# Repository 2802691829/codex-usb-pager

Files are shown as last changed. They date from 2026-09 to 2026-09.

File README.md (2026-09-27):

# Codex USB Pager

一个基于 RP2040-Zero 的桌面 USB 状态提示器。它通过 USB CDC 接收电脑端汇总状态，
用 1.3 英寸 ST7789 屏幕显示 Codex 任务状态、并行任务数量和每周余量，并在需要人工
处理或任务完成时通过有源蜂鸣器提示。

本仓库同时包含程序源码、主机端工具、测试、已验证 UF2，以及最终四卡扣树脂外壳的
可编辑模型和打印文件。

## 项目简介

主要能力：

- 将多个 Codex 任务聚合为一个 `RUNNING`、`WAIT`、`DONE` 或 `ERROR` 状态；
- 在屏幕上显示 Blossom 动画、并行任务效果和周余量；
- 通过边沿事件控制蜂鸣器，普通运行和心跳保持静音；
- 提供可编辑 FreeCAD 外壳、STEP 交换模型及前后壳 STL；
- 保留固件、主机端和外壳几何测试，方便后续维护。

## 硬件与接线

核心硬件：

- 控制器：RP2040-Zero；
- 屏幕：1.3 英寸 ST7789 IPS，240 × 240，七针 SPI；
- 蜂鸣器：三针低电平触发有源蜂鸣器；
- 板载状态灯：GP16 上的 WS2812；
- 连接方式：RP2040-Zero USB-C，USB CDC。

| 模块引脚 | RP2040-Zero | 说明 |
| --- | --- | --- |
| 屏幕 GND | GND | 共地 |
| 屏幕 VCC | 3V3 | 不要接 5 V |
| 屏幕 SCL | GP12 | PIO SPI 时钟 |
| 屏幕 SDA | GP11 | PIO SPI 数据 |
| 屏幕 RES | GP10 | 复位 |
| 屏幕 DC | GP9 | 命令/数据 |
| 屏幕 BLK | GP8 | 高电平开启背光 |
| 蜂鸣器 GND | GND | 共地 |
| 蜂鸣器 IO | GP14 | 低电平触发 |
| 蜂鸣器 VCC | 3V3 | 模块供电 |

不要使用裸露的两针无源蜂鸣器。

## USB 状态协议

电脑端通过 USB CDC 发送一行以换行符结束的 ASCII 快照：

```text
STATE <state> RUN=<n> WAIT=<n> DONE=<n> BAL=<token> EV=<event>
```

示例：

```text
STATE RUNNING RUN=2 WAIT=0 DONE=14 BAL=82 EV=NONE
```

- 状态：`IDLE`、`RUNNING`、`WAIT`、`DONE`、`ERROR`；
- 事件：`NONE`、`WAIT`、`DONE`、`ERROR`；
- 8 秒未收到有效快照时，固件进入 `OFFLINE`；
- `RUNNING` 且 `RUN>1` 时显示多任务动画。

## 屏幕与蜂鸣器行为

- `OFFLINE`：六个灰色 Blossom 部件落到白色六边形底部；
- `IDLE/READY`：六个绿色部件缓慢环绕，中央显示周余量；
- `RUNNING`：紫色 Blossom 旋转并带有加速和缩放脉冲；
- 多任务运行：主 Blossom 位于前方，后方叠加模糊彩色层；
- `WAIT`：琥珀色确认画面；
- `DONE`：完成画面每三秒脉冲一次，不显示勾号。

蜂鸣器事件：

- `EV=WAIT`：三次安静短鸣；
- `EV=DONE`：一次安静短鸣；
- `EV=ERROR`：五次安静短鸣；
- `RUNNING`、`IDLE`、`OFFLINE`、心跳和普通工具活动静音。

## 快速使用已验证固件

已打包固件位于：

```text
firmware-release/codex_pager_rp2040.uf2
```

烧录步骤：

1. 按住 RP2040-Zero 的 `BOOT` 键；
2. 连接 USB，或在按住 `BOOT` 时复位；
3. 等待电脑出现 `RPI-RP2` 磁盘；
4. 将 UF2 文件复制到该磁盘；
5. 复制完成后磁盘自动消失，控制器重新启动。

仅修改电脑端 Hook 或聚合逻辑时不需要重新烧录固件。

## 从源码构建固件

需要 Raspberry Pi Pico SDK、CMake 和可用的 ARM GCC 工具链。在仓库根目录运行：

```powershell
powershell -ExecutionPolicy Bypass -File tools/build_rp2040.ps1
```

构建结果：

```text
build-rp2040/codex_pager_rp2040.uf2
```

固件源码位于 `ports/rp2040-zero/firmware/`，原生行为测试位于
`ports/rp2040-zero/tests/`。

## 主机端工具

需要 Python 3，并安装串口与测试依赖：

```powershell
python -m pip install pyserial pytest
```

主要入口：

- `tools/pager_daemon.py`：聚合任务状态并持续发送 USB 快照；
- `tools/pager_hook_runtime.py`：接收 Codex Hook 事件；
- `tools/session_watcher.py`：读取语义会话事件；
- `tools/pager_runtime.py`：维护多任务运行状态；
- `tools/pager_transport.py`：USB 串口传输；
- `tools/weekly_balance.py`：读取周余量。

启动守护进程：

```powershell
python tools/pager_daemon.py
```

`installed-hooks/` 保存当时安装使用的 Hook 和配置快照。复制或修改 Hook 前，请先阅读
`PROGRAM_HANDOFF.md`，并根据本机 Codex 配置目录调整绝对路径。同一时间只运行一个
`pager_daemon.py` 进程。

## 最终四卡扣外壳

最终模型位于 `enclosure/`：

- 可编辑 FreeCAD：`enclosure/outputs/blossom-enclosure.FCStd`；
- STEP：`enclosure/outputs/blossom-enclosure.step`；
- 前壳 STL：`enclosure/outputs/blossom-front.stl`；
- 后壳 STL：`enclosure/outputs/blossom-rear.stl`；
- 参数化建模源码：`enclosure/cad/`；
- 几何测试：`enclosure/tests/`；
- 审计结果：`enclosure/outputs/audit.json`。

只有 `audit.json` 中 `passed=true`，并且 `checks` 中每一项均为 `true` 时，STL 才可
作为打印候选。

树脂打印建议：

- 倾斜摆放，避免将正反面 Blossom 浮雕和正面六边形承靠边直接贴平台；
- 支撑尽量放在隐藏内表面，避开屏幕承靠面、四个卡扣受力面和滑动导轨；
- 普通壳壁为 1.50 mm；卡扣根部和导轨受力壁不低于 1.30 mm；
- 已知薄桥、支撑和止挡不低于 0.80 mm；
- 清洗、排液并完全固化后再试装，不要强压未固化卡扣。

合盖顺序：

1. 将上方两个公头倾斜插入后壳上方接收槽；
2. 放平前壳；
3. 从底边向上滑动 2.50 mm，直到下方两个卡扣进入浅止动。

USB 开口相对早期基线向上移动 5.00 mm。蜂鸣器完全内置，不设置外部开孔。

## 测试

主机端回归命令：

```powershell
python -m pytest tools/test_pager_runtime.py tools/test_session_watcher.py tools/test_pager_state.py tools/test_codex_log_watcher.py tools/test_pager_transport.py -q
```

外壳源码测试：

```powershell
python -m pytest enclosure/tests -q
```

本次 GitHub 整理按用户要求未重新运行测试；历史交接记录中的最近一次主机端结果为
2026-08-21 的 50 项通过，外壳最终审计文件记录 `passed=true`。

## 目录结构

```text
assets/                 Blossom 原始资源
Core/                   生成后的 Blossom 掩码源码
docs/program-history/   程序设计历史
enclosure/              最终四卡扣外壳源码、测试和输出
firmware-release/       已打包 UF2
installed-hooks/        Hook 安装快照
ports/rp2040-zero/      RP2040 固件和测试
tools/                  电脑端工具和测试
PROGRAM_HANDOFF.md      程序维护交接说明
```

## 维护说明

- 修改前先阅读 `PROGRAM_HANDOFF.md`；
- 保持多任务聚合：单个任务提前完成时必须静音，最后一个活动任务结束后才能发出完成事件；
- 不要随意修改 Blossom 中心、花瓣比例、六边形边界、配色或过渡动画；
- 构建目录、Python 缓存、临时测试目录和对象文件不会纳入版本控制；
- 本仓库不包含旧版外壳基线、旧 ZIP 或工作区中的其他项目。

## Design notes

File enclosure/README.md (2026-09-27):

# Blossom 外壳输出说明

`outputs/` 根目录保存已确认的只读基线；本次四卡扣改造全部位于
`outputs/four-latch-retrofit/`，不会覆盖基线文件。

## 最终文件

- `blossom-enclosure.FCStd`：可编辑 FreeCAD 源模型。
- `blossom-enclosure.step`：前壳与后壳组合交换模型。
- `blossom-front.stl`：前壳树脂打印网格。
- `blossom-rear.stl`：后壳树脂打印网格。
- `audit.json`：尺寸、装配避让和网格完整性审计。
- `review-dimensions.txt`：关键尺寸摘要。
- `review-*.png`：外观、内部、屏幕退让、四卡扣和三段装配复核图。

只有 `audit.json` 中 `passed` 为 `true`，并且所有 `checks` 均为 `true` 时，
两份 STL 才可作为打印候选。

## 合盖顺序

1. 将上方两个公头倾斜插入后壳上方接收槽。
2. 放平前壳。
3. 从底边向上滑动 `2.50 mm`，直到下方两个卡扣进入 `0.25 mm` 浅止动。

屏幕由后壳内陷支撑和四个边缘止挡固定，正面不设屏幕卡槽。USB 开口相对
基线向上移动 `5.00 mm`。蜂鸣器完全内置，本版本不增加蜂鸣器开孔。

## 嘉立创树脂打印

- 建议倾斜摆放，避免把正反 Blossom 浮雕和正面六边形承靠边直接贴平台。
- 支撑尽量落在隐藏内表面，避开屏幕承靠面、四个卡扣受力面和滑动导轨。
- 普通壳壁为 `1.50 mm`；卡扣根部和导轨受力壁不低于 `1.30 mm`；已知薄片、
  桥和止挡不低于 `0.80 mm`。
- 清洗、排液并完全固化后再试装。首次合盖应缓慢滑入，不要在未固化树脂上
  强行按压卡扣。

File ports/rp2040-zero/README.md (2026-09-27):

# Codex Pager: RP2040-Zero Porting Guide

This directory freezes the working STM32 pager design so it can be ported to an
RP2040-Zero without rediscovering the protocol, animation, or asset pipeline.
The STM32 implementation remains the behavioral reference.

## Current Status

The RP2040-Zero now drives the ST7789 through the verified PIO/DMA path. USB
CDC, the onboard WS2812 on GP16, and the optional active-low buzzer on GP14
remain active.

The temporary status effects are:

- `IDLE`: low cool white.
- `RUNNING`: blue-purple breathing.
- Multi-task running: the purple foreground Blossom continues uninterrupted;
  each additional task adds one complete, translucent blue/violet/cyan Blossom
  behind it, capped at three ghosts.
- `WAIT`: amber double flash.
- `DONE`: soft green pop every three seconds.
- `ERROR`: red triple flash and five short buzzer pulses.
- `OFFLINE`: dim red slow flash after eight seconds without a valid snapshot.

Every RGB channel is clamped to 20 out of 255.

## Frozen Behavior

- Display: ST7789, 240x240, RGB565, seven-pin SPI module.
- States: `IDLE`, `RUNNING`, multi-task running, `WAIT`, `DONE`, `ERROR`, and
  `OFFLINE`.
- Fixed visual center: `(120, 109)`.
- Animated region: `(34, 23)`, size `172x172`.
- Footer begins at y=196.
- Frame target: 72 ms.
- State transition: 260 ms exit followed by 480 ms enter.
- Running cycle: 4.7 seconds with continuous angular acceleration and scale.
- Multi-task cycle: 4.6 seconds plus three translucent colored Blossom layers.
- DONE has no check badge. Its pearl Blossom and mint ring pulse every 3 seconds.
- The active-low buzzer is non-blocking: 25 ms on and 180 ms between beeps.
- Host timeout: 8 seconds, then `OFFLINE`.

The exact animation and palette implementation is in
`../../Core/Src/oled.c`. Do not redraw the logo from primitives.

## Proposed RP2040-Zero Wiring

| Display/module pin | RP2040-Zero | Purpose |
| --- | --- | --- |
| GND | GND | Common ground |
| VCC | 3V3 | ST7789 power |
| SCL | GP12 | PIO SPI clock |
| SDA | GP11 | SPI1 TX |
| RES | GP10 | Display reset |
| DC | GP9 | Command/data |
| BLK | GP8 | Backlight, high=on |
| Buzzer IO | GP14 | Active-low buzzer input |
| Buzzer VCC | 3V3 | Buzzer module power |
| Buzzer GND | GND | Common ground |

The bare two-pin passive buzzer is not part of this saved design.

## USB Wire Protocol

The device receives newline-terminated ASCII over USB CDC:

```text
STATE <state> RUN=<n> WAIT=<n> DONE=<n> BAL=<token> EV=<event>\n
```

Example:

```text
STATE RUNNING RUN=3 WAIT=0 DONE=14 BAL=82 EV=NONE
```

Rules:

- `WAIT` has visual priority over running tasks.
- `RUNNING` with `RUN>1` selects the multi-task animation.
- `EV=WAIT`, `EV=DONE`, and `EV=ERROR` trigger 3, 1, and 5 quiet short pulses
  respectively. The boot pulse is one short pulse. RUNNING and multi-task
  running stay silent.
- Events are edge notifications; heartbeat snapshots normally use `EV=NONE`.
- Existing host aggregation remains in `../../tools/`.

## Files To Reuse

| Source | RP2040 use |
| --- | --- |
| `../../assets/openai-blossom.svg` | Canonical official Blossom source |
| `../../tools/generate_blossom_asset.py` | Regenerate the packed mask and sine table |
| `../../Core/Inc/blossom_asset.h` | Copy unchanged |
| `../../Core/Src/blossom_asset.c` | Copy unchanged; 8192-byte 4-bit alpha mask |
| `../../Core/Src/oled.c` | Behavioral reference for palette, animation, and compositing |
| `../../Core/Src/main.c` | Behavioral reference for parsing, timeout, and buzzer scheduling |
| `../../tools/pager_state.py` | Host state aggregation |
| `../../tools/pager_runtime.py` | Multi-task runtime database |
| `../../tools/pager_daemon.py` | Two-second heartbeat sender |

## Recommended Pico SDK Architecture

Use Pico SDK C/C++ with TinyUSB enabled.

1. Core 0 owns TinyUSB CDC, command parsing, the 8-second host timeout, and the
   non-blocking buzzer state machine.
2. The display renderer may remain on core 0 initially. Move it to core 1 only
   if USB servicing becomes uneven during full-frame animation.
3. Use a PIO state machine plus DMA for ST7789 output because the required
   consecutive GP29/GP28 wiring is not a fixed hardware SPI SCK/TX pair.
4. Render one 172-pixel RGB565 scanline into a 344-byte buffer. Use two line
   buffers and DMA so the next line can be composed while the previous line is
   transmitted.
5. Keep all animation calculations integer-only. Reuse `g_sin_q15[256]`, Q12
   scale, 8-bit angle, RGB565 blending, and 4-bit bilinear mask sampling.
6. Call `tud_task()` frequently. Accumulate CDC bytes until newline, then pass
   one complete line to the existing parser logic.

## Porting Boundaries

Preserve these functions conceptually:

```text
ui_init()
ui_set_dashboard(state, run, wait, done, balance)
ui_update(time_ms)
buzzer_start(count)
buzzer_update(time_ms)
process_line(ascii_line)
```

Replace only these STM32-specific pieces:

- `HAL_GetTick()` -> `to_ms_since_boot(get_absolute_time())`
- GPIO BSRR writes -> Pico GPIO helpers or SPI peripheral output
- software SPI and `set_window()` transport -> Pico PIO + DMA
- STM32 USB device stack -> TinyUSB CDC
- STM32 startup, linker script, HAL, and Cube USB files -> Pico SDK CMake target

## Host Discovery Change

`../../tools/send_pager.py` discovers both the Pico SDK RP2040 CDC identity
`2E8A:000A` and the STM32 reference identity `0483:5740`. The RP2040 firmware
uses the product string `Codex Pager`; `--port COMx` remains available.

## Stage 1 Build

Required tools are Pico SDK 2.2.0, ARM GNU Toolchain 14.3, CMake, NMake, and
picotool 2.2.0 or another picotool compatible with SDK requirement 2.1.1.

On this Windows machine, the ARM linker cannot consume object paths containing
Chinese characters. Build through an ASCII source path and keep the SDK and
build directory on an ASCII path. The verified target is:

```text
PICO_BOARD=pico
firmware target: codex_pager_rp2040
UF2: build-rp2040/codex_pager_rp2040.uf2
```

Native core tests:

```powershell
cmake -S ports/rp2040-zero/tests -B <ascii-build-dir> -G "NMake Makefiles"
cmake --build <ascii-build-dir>
ctest --test-dir <ascii-build-dir> --output-on-failure
```

Firmware configuration follows the same pattern with
`ports/rp2040-zero/firmware`, `PICO_SDK_PATH`, `PICO_TOOLCHAIN_PATH`,
`PICO_BOARD=pico`, and `picotool_DIR` set explicitly.

The verified local build helper stages the source and SDK under an ASCII-only
temporary path before compiling, then copies the UF2 back into the project:

```powershell
powershell -ExecutionPolicy Bypass -File tools/build_rp2040.ps1
```

## Acceptance Checklist

- ST7789 initializes at 240x240 with correct orientation and RGB order.
- Blossom bounding box is centered on `(120, 109)` at zero rotation.
- Rotation does not change the center pixel or create a visible jump.
- Single-task running completes a smooth 4.7-second cycle.
- `RUN=3` shows three translucent ghost Blossoms behind the primary Blossom.
- WAIT has three short low-level buzzer pulses without freezing animation.
- DONE contains no check and pulses at 0, 3, 6 seconds.
- State transitions last 650 ms and never clear to a bright frame.
- USB remains responsive while animation is active.
- Missing heartbeat produces OFFLINE after 8 seconds.
- The existing Python state/runtime tests still pass.

## Prompt For A Future Codex Session

```text
Read codex_usb_pager/ports/rp2040-zero/README.md and port_manifest.json.
Continue from the tested stage-1 Pico SDK firmware. Reuse blossom_asset.c/h and
the host wire protocol. Keep ST7789 output on BLK=GP8, DC=GP9, RES=GP10,
SDA=GP11, SCL=GP12 with packed whole-region PIO/DMA output, then add the
non-blocking active-low buzzer on GP14. Build and test before flashing. Do not
redesign the visuals.
```

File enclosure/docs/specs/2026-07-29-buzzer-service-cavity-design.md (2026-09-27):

# Blossom Buzzer Service Cavity Design

Date: 2026-07-29

## Goal

Replace the buzzer-matched cylindrical relief with a substantially larger
service cavity in the left rear Blossom petal. The cavity must maximize usable
assembly space without changing the visible enclosure exterior.

## Approved Geometry

- Keep the buzzer validation envelope at 12.0 mm diameter and 11.5 mm height.
- Remove the buzzer envelope's cylindrical shape as the production cavity
  boundary.
- Create a connected service cavity that opens from the existing rectangular
  electronics cavity into the left Blossom petal.
- Start the service cavity at the PCB/buzzer front plane, Z = 4.30 mm.
- Extend it to Z = 18.30 mm, the safe inner rear surface, instead of stopping
  at the buzzer's 11.5 mm validation height.
- Define its generous pre-clipping window as X = -28.0 to -12.0 mm and
  Y = -5.5 to 18.0 mm. This overlaps the existing electronics cavity by
  2.0 mm and leaves the lower latch and upper locator outside the window.
- Give the pre-clipping window 3.0 mm corner radii.
- Expand the cavity toward the left petal as far as the protected inner
  Blossom contour permits.
- Preserve at least 1.50 mm of exterior wall and relief backing around the new
  cavity.
- Keep the service cavity clear of the upper locator tongue/socket pair and
  the lower hidden spring latch and its activity tunnel.
- Use rounded transitions where the service cavity joins the existing
  electronics cavity. No buzzer-shaped circular wall is retained.

## Closure Features

The small raised feature and matching recess shown near the upper shell edge
are the front-shell locator tongue and rear-shell locator socket. They prevent
upper-edge shear, rocking, and assembly misalignment. The side spring latches
remain responsible for locking the enclosure.

Both upper locators remain unchanged and hidden after assembly.

## Exterior Contract

The following visible geometry must remain unchanged:

- 56.0 mm Blossom outer width and unwarped SVG proportion.
- Front and rear 1.5 mm Blossom relief.
- Front screen hexagon and screen pocket alignment.
- Rear rounded USB opening.
- Continuous front and rear exterior surfaces with no buzzer opening.

The service cavity cutter is clipped to an internal protected Blossom core.
It must not intersect the exterior guard.

## Mechanical Keepouts

The new cavity must not obstruct:

- the 26.30 x 29.30 mm screen pocket and its retainers;
- the four screen locating posts;
- the two upper tongue/socket locators;
- the two lower hidden spring latches and their motion envelopes;
- the USB adapter window and support structure.

## Verification

Automated checks must prove:

- buzzer service cavity exterior breach volume is 0.0 mm3;
- buzzer obstruction volume remains 0.0 mm3;
- closure, USB, screen, and assembly interference volumes remain 0.0 mm3;
- the rear shell remains valid and a single solid;
- front and rear exterior dimensions and relief depths are unchanged;
- the new service cavity is wider and deeper than the 12.0 x 11.5 mm buzzer
  validation envelope;
- rendered rear-inside and assembly-cutaway views visibly show the enlarged
  non-cylindrical cavity;
- front and rear exterior renders remain visually unchanged.

## Deliverables

- Updated FreeCAD source model.
- Regenerated FCStd, STEP, front STL, and rear STL files.
- Updated geometry audit and regression tests.
- Updated review renders and a refreshed handoff archive.

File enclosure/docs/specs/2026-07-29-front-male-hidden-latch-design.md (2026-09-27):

# 前壳公扣、后壳弹片隐藏卡扣设计

日期：2026-07-29

## 背景与问题

上一版闭合结构把插舌盲槽和卡勾槽直接切入前壳。前壳接缝厚度为
2.3 mm，而正面白块区域又下凹 1.5 mm，局部只保留 0.8 mm 材料。
卡槽从内侧继续切入后，与正面凹陷切削发生重叠，形成正面可见孔。

本次修改必须满足：

- 前壳正面和侧面均看不到卡扣孔。
- 后壳背面和侧面也不能出现母槽通孔。
- 仍然采用隐藏结构，不在外轮廓增加凸耳。
- 偶尔拆开时可用指甲完成，不使用螺丝或工具。
- 屏幕固定、USB 后开孔、蜂鸣器全内藏和 1.5 mm Blossom 凹凸保持不变。

## 选定结构

卡扣公母方向反转为“前壳短刚性公扣 + 后壳长弹片母扣”。

### 顶部定位

前壳内侧设置两个刚性定位舌，沿装配方向伸入后壳。后壳内侧设置两个
有封底的定位盲槽。定位舌只负责对中和限制横向晃动，不承担弹性锁止。

初始尺寸：

- 定位舌：宽 5.0 mm、厚 1.0 mm、从接缝向后伸出 2.5 mm。
- 两个定位舌中心为 X = ±10.0 mm、Y = 19.75 mm，以正面有效显示区
  中心为坐标原点。
- 舌尖设置 0.5 mm 导入斜面或等效圆角。
- 后壳盲槽：四周单边间隙 0.25 mm，深度 2.8 mm。
- 盲槽与后壳任何外表面之间保留至少 1.0 mm 实体材料。

### 底部锁止

前壳左右侧花瓣各设置一个短刚性公扣。公扣本体与前壳形成连续实体，
只提供导入斜面和浅锁止台阶，不使用长弹性臂。原底部位置因左侧弹片
会侵入 Blossom 曲面 1.0 mm 外表保护层，并与 USB 内部结构争用空间，
不再使用。

后壳左右侧花瓣各设置一根长悬臂弹片。弹片从后壳较深位置向接缝延伸，
自由端设置母扣窗口或锁止肩。压合时前壳公扣使后壳弹片轻微向外偏转，
越过锁止台阶后回弹。拆卸时，从后壳底部指甲凹位轻撬，20° 脱扣斜面
把轴向拉力转换成小幅弹片偏转。

初始尺寸：

- 前壳公扣宽 4.0 mm，本体厚 1.2 mm。
- 公扣从接缝向后伸出 2.2 mm。
- 两个公扣初始中心为 X = ±15.0 mm、Y = -9.0 mm；实际 CAD 允许在
  相同侧花瓣内微调不超过 1.0 mm，以同时满足外表保护层和内部避让。
- 锁止量 0.35 mm；若首版过紧，优先降到 0.30 mm。
- 导入斜面 35°，脱扣斜面 20°。
- 后壳弹片有效长度 13.0 mm、宽 4.0 mm、厚 1.0 mm。
- 弹片沿 Z 轴布置，自由端靠近接缝，根部位于接缝后方约 13.4 mm。
- 弹片根部圆角 R1.0 mm。
- 弹片周边活动间隙每侧 0.30 mm。
- 指甲凹位保持 10.0 × 1.2 × 0.8 mm，位于后壳底部接缝。

公扣采用短而厚的刚性结构，避免前壳拆开后留下容易折断的长臂。弹性
和磨损集中在可单独重印的后壳上。

## 蜂鸣器净空

蜂鸣器改到屏幕 PCB 左侧、靠上位置，继续完全封闭，不增加声孔。

- 实物圆柱直径 11.0 mm，CAD 净空直径采用 12.0 mm。
- 实物圆柱高度 10.0 mm，CAD 净空高度采用 11.5 mm。
- 用户实测圆柱边缘距 PCB 上边约 7.0 mm、距 PCB 下边约 19.0 mm。
- 屏幕 PCB 高度按 39.22 mm。两组边距与实物直径合计相差 2.22 mm，
  因此以两种中心推算值的平均值定位：在现有外壳坐标系中
  Y = 4.36 mm。
- 使用直径 12.0 mm 净空后，理论上边距约 7.61 mm、下边距约
  19.61 mm。
- 横向按照片将圆柱中心初始设为 X = -9.0 mm。蜂鸣器净空允许通过
  左侧局部圆柱腔超出 28 mm 主电子腔，但不得侵入 1.0 mm 外表保护层。
- 净空从屏幕 PCB 后表面向后延伸 11.5 mm，并与 USB、左右卡扣、
  屏幕定位柱和后壳保持零实体干涉。

## 几何布置

- 两个顶部定位舌和两个侧面公扣均位于 28.0 × 39.5 mm 主电子腔包络
  以外。
- 公扣、弹片和母槽不得与屏幕 PCB、四根定位柱、USB 转接口、USB
  受力板、蜂鸣器或线材包络相交。
- 前壳闭合结构只能增加材料，不得从 `FrontClosureBlank` 原有实体中
  切除材料。
- 后壳定位盲槽、弹片活动腔和母扣窗口全部从接缝内侧形成；任何切削均
  不得到达后壳外表面。
- 前后壳闭合后，公扣和弹片均位于 Blossom 外轮廓投影以内。

## 自动验收

在现有实体审计上增加以下检查：

1. `front_closure_skin_removed_mm3 == 0.0`：最终前壳相对
   `FrontClosureBlank` 不得损失任何原表皮材料。
2. 前壳两个定位舌和两个刚性公扣均与前壳形成连续实体。
3. 后壳两根弹片均与后壳形成连续实体，且各自具有独立活动间隙。
4. 两个公扣均进入对应母扣包络，并具有 0.30–0.35 mm 有效锁止量。
5. 顶部定位舌进入盲槽，但与槽底和四周保留规定间隙。
6. 后壳闭合结构切削不与背面及侧面连续的 1.0 mm 外表保护层相交。
7. 前后壳装配实体干涉体积保持 0。
8. 屏幕和 USB 遮挡体积保持 0。
9. 前壳、后壳均为单一有效实体。
10. `buzzer_obstruction_mm3 == 0.0`：最终后壳、USB 结构和卡扣不得
    进入直径 12.0 mm、高 11.5 mm 的蜂鸣器净空。
11. 蜂鸣器净空与后壳 1.0 mm 外表保护层不得相交。

## 人工验收

重新输出以下不透明审阅图：

- 前壳正面正投影：确认没有矩形孔或透光区域。
- 前壳内面：确认四个公头位置和屏幕固定结构互不干涉。
- 后壳背面正投影：确认母槽和弹片活动腔不透出。
- 后壳内面：确认两根长弹片可以自由变形。
- 接缝剖面和单侧卡扣放大图：确认公扣导入、锁止和脱扣方向。
- 蜂鸣器净空图：确认左侧圆柱包络、USB 和两侧卡扣之间有余量。

首版树脂试装时先检查扣合力、指甲拆卸力和弹片根部是否白化。若扣合
过紧，只调整母扣间隙或把锁止量从 0.35 mm 降到 0.30 mm；不缩短
13.0 mm 弹片，也不在前壳重新开槽。

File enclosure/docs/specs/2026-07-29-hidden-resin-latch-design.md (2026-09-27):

# Blossom 外壳隐藏易拆卡扣设计

日期：2026-07-29

## 目标

把现有四个仅用于占位的矩形块替换为能够真实扣合的隐藏闭合结构，并把完全平整的前壳内面改为能够真实固定屏幕的卡槽与定位柱。外壳使用未知型号的光敏树脂打印，因此按普通偏脆树脂设计：装好后可靠固定，偶尔拆开时可用指甲轻松开启，不需要螺丝或工具。

## 现有问题

当前 `TopHookLeft`、`TopHookRight`、`ReleaseLatchLeft` 和 `ReleaseLatchRight` 都是融合在后壳上的简单矩形实体。前壳没有配合槽，这些实体也没有弹性臂、倒钩、导入斜面或脱扣斜面，所以不能产生机械锁止。现有审计只检查对象名称是否存在，无法证明前后壳能够扣合。

当前前壳内面只有一块平整的矩形承托面，没有与屏幕玻璃外框配合的卡槽，也没有利用 PCB 四角安装孔的定位柱。屏幕位置仅由 28 × 39.5 mm 电子组件包络间接表达，不能保证实际显示区域与正面六边形窗口同心，也不能保证拆下后壳时屏幕仍固定在前壳。

## 闭合结构

采用“顶部定位插舌 + 底部双悬臂浅卡勾”：

1. 后壳顶部设置两个刚性插舌，前壳内侧设置两个盲槽。装配时先以小角度插入顶部，再压下后壳底部。插舌只负责定位和形成开启转轴，不依靠弯曲锁止。
2. 后壳底部左右各设置一个长悬臂卡勾。卡臂从后壳内部向前壳延伸，位于电子器件包络之外，并与后壳形成连续实体。
3. 前壳内侧切出两个对应卡槽。压合时，卡勾的导入斜面使卡臂轻微向内偏转；越过槽口后回弹并形成浅锁止。
4. 后壳底部接缝设置一个不贯穿的指甲凹位。拆壳时从凹位轻撬，卡勾上的脱扣斜面把轴向拉力转化为很小的卡臂偏转，使底端先脱开，再从顶部插舌退出。
5. 所有插舌、卡臂、卡勾和卡槽均位于 Blossom 外轮廓以内；闭合后从正面、背面和侧面都看不到凸出的卡扣。

## 初始尺寸

尺寸以首版试打印为基准，后续只通过参数调整：

- 顶部插舌：每个宽 5.0 mm、厚 1.0 mm、有效插入 2.5 mm。
- 插舌盲槽：单边装配间隙 0.25 mm，槽底保留至少 0.8 mm 壁厚。
- 底部卡臂：每个长 13.0 mm、宽 4.0 mm、厚 1.0 mm。
- 卡臂根部圆角：半径 1.0 mm，避免树脂应力集中。
- 卡勾锁止量：0.40 mm。
- 卡勾导入斜面：35°。
- 卡勾脱扣斜面：20°，避免形成难以撬开的直角倒扣。
- 卡槽周边间隙：每侧 0.30 mm。
- 指甲凹位：宽 10.0 mm、高 1.2 mm、最大内凹 0.8 mm，仅削薄后壳接缝外缘，不贯穿壳体。
- 最小实体壁厚：0.8 mm。

若切片软件的尺寸补偿或打印收缩导致配合偏紧，优先增加卡槽间隙或把锁止量从 0.40 mm 降至 0.30 mm，不缩短卡臂。

## 前壳屏幕固定结构

屏幕模块使用用户提供的 1.3 英寸 ST7789 尺寸图和实测高度：

- PCB 外形：27.78 × 39.22 mm。
- 屏幕有效显示区：23.40 × 23.40 mm。
- 屏幕玻璃外框：25.30 × 29.22 mm。
- 屏幕玻璃正面到 PCB 正面：2.0 mm。
- 四个安装孔：直径 2.0 mm，孔中心距 PCB 各边均为 2.50 mm。

屏幕固定采用“屏幕面卡槽 + 四定位柱 + 两个浅防脱压唇”：

1. 前壳内面增加 25.70 × 29.62 mm 的矩形屏幕面卡槽，等于屏幕玻璃外框四周各留 0.20 mm 间隙。卡槽有效深度 1.0 mm，承力面避开 23.40 × 23.40 mm 有效显示区，并在正面六边形窗口以外形成分散承托。
2. 四根定位柱利用 PCB 四角的直径 2.0 mm 安装孔定位。柱中心相对 PCB 中心的坐标为 X = ±11.39 mm、Y = ±17.11 mm；柱径 1.65 mm，根部加强台直径 3.2 mm，根部带圆角。
3. 定位柱只控制平面位置，不承担屏幕压紧力。屏幕玻璃正面到 PCB 正面的 2.0 mm 高度用于确定卡槽承力面、加强台和定位柱的 Z 向关系。
4. 屏幕面卡槽左右各设置一个隐藏的浅防脱压唇。压唇只越过屏幕玻璃后缘 0.25 mm，不接触 PCB 边缘，不压迫有效显示区；拆下后壳时屏幕仍保留在前壳。
5. 根据尺寸图，有效显示区中心相对 PCB 中心向排针一侧偏移 1.64 mm。正面六边形窗口继续以有效显示区中心为基准；PCB、屏幕玻璃卡槽和四根定位柱整体向排针对侧平移 1.64 mm，不能再与六边形窗口直接同心。
6. 屏幕装入方向为从前壳内侧压入。卡槽入口和压唇均增加圆角或导入斜面，避免刮伤屏幕玻璃边缘。
7. 后壳 28 × 39.5 mm 电子腔与 PCB 使用相同的 -1.64 mm 中心偏移，电子腔底边位于 Y = -21.39 mm。USB 开孔底边随 PCB 基准移到 Y = -24.75 mm，继续保持距屏幕 PCB 底边 3.5 mm。

## 与现有结构的关系

- 删除四个矩形占位块及把它们直接融合到后壳的逻辑。
- 删除现有整块矩形 `screen_ledge`，改为屏幕面卡槽、分散承托面、四根定位柱和两个浅防脱压唇。
- USB 圆角开孔、USB 受力板和 5 mm 内部间隙保持不变。
- 蜂鸣器继续完全藏在内部，不增加声孔。
- 正反面 Blossom 凹凸深度 1.5 mm 和圆滑过渡保持不变。
- 卡臂与电子器件腔、屏幕 PCB、USB 转接口及线材包络不得相交。

## 验收与验证

模型和自动检查必须同时满足：

1. 前壳包含两个真实插舌盲槽和两个真实卡槽；后壳包含两个插舌及两个带斜面的悬臂卡勾。
2. 卡槽必须从前壳实体中实际切除，卡臂和插舌必须与后壳形成连续实体，不能只创建同名辅助对象。
3. 装配位置下，前后壳的非配合实体不得互相穿透；卡勾位于对应卡槽包络内并具有 0.30–0.40 mm 的有效锁止量。
4. 指甲凹位不贯穿壳体，外轮廓没有新增卡扣凸起。
5. 屏幕和 USB 的遮挡体积均为 0。
6. FreeCAD 几何有效性检查通过，前壳和后壳均为可导出的有效实体。
7. 输出正面、背面、侧面、接缝剖面和卡扣局部放大图供人工确认；确认后再导出最终 STL。
8. 屏幕卡槽、定位柱和防脱压唇必须与前壳形成连续实体，不能只是同名辅助对象。
9. 四根定位柱中心与安装孔理论中心偏差为 0；定位柱与直径 2.0 mm 安装孔之间保留 0.175 mm 径向间隙。
10. 屏幕玻璃外框与卡槽之间保留每侧 0.20 mm 间隙，有效显示区与正面六边形窗口按显示区中心对齐。
11. 屏幕承托面和防脱压唇不得侵入 23.40 × 23.40 mm 有效显示区；定位柱及加强台不得与屏幕玻璃外框相交。
12. 装配位置下前壳与后壳的实体干涉体积为 0；四根定位柱及屏幕固定结构不得与后壳电子腔边缘相交。

## 首版试装预期

合壳时先插入顶部，再按压底部两侧，能够感觉到一次轻微扣合。拆壳时用指甲从底部凹位轻撬，不需要明显蛮力；后壳底部先脱开，随后向下退出顶部插舌。卡扣不应出现白化、裂纹或永久变形。

屏幕从前壳内侧装入时，屏幕玻璃外框先进入矩形卡槽，四个安装孔随后落到定位柱上，左右浅压唇以很小变形越过玻璃后缘。屏幕应无明显晃动，玻璃和 PCB 不受持续挤压；拆下后盖并轻晃前壳时，屏幕不脱落。

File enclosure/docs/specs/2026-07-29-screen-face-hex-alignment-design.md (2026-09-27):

# 屏幕凸起卡槽与六边形视窗对齐设计

日期：2026-07-29

## 问题与根因

当前前壳使用 `27.1 mm` 的六边形对边尺寸。该正六边形采用上下顶点
朝向，因此上下顶点距离为：

`27.1 / (sqrt(3) / 2) = 31.29 mm`

该开口高于屏幕凸起部分的 `29 mm` 高度，并且以外壳/显示有效区中心
定位，没有从屏幕凸起顶部建立基准。因此六边形超出屏幕平面，屏幕卡槽
也表现为按旧的近似玻璃尺寸固定，而不是卡住实际屏幕凸起。

## 已确认的实物尺寸

- 屏幕凸起部分：宽 `26.0 mm`、高 `29.0 mm`。
- 屏幕凸起四周有 `0.5 mm` 黑边，外观上不得从前壳视窗露出。
- 屏幕凸起底部有 `3.0 mm` 非显示区域，六边形视窗不得保留在该区域。
- 六边形上下顶点距离：`23.5 mm`。
- 卡槽采用方案 1：屏幕凸起四周单边装配间隙 `0.15 mm`。

PCB 的 `27.78 × 39.22 mm` 外形和四个 `Ø2 mm` 定位孔继续用于定位柱，
但不再作为屏幕卡槽和六边形视窗的外形基准。

沿用规格图中屏幕凸起顶部距 PCB 顶边 `5.00 mm` 的定位尺寸。将屏幕凸起
高度改为实测 `29.00 mm` 后，其底边距 PCB 底边为
`39.22 - 5.00 - 29.00 = 5.22 mm`。

## 屏幕凸起卡槽

卡槽内包络为：

- 宽：`26.0 + 2 × 0.15 = 26.30 mm`
- 高：`29.0 + 2 × 0.15 = 29.30 mm`

卡槽的前端承托平面与屏幕凸起正面平行并贴合，使屏幕凸起进入卡槽后
由前壳内面确定 Z 向位置。四根 PCB 定位柱保留，负责孔位对中；卡槽负责
约束屏幕凸起的 X/Y 外形。左右压片继续从背面压住屏幕凸起，但不得进入
六边形可视开口，也不得与蜂鸣器 `Ø12 × 11.5 mm` 净空相交。

屏幕凸起正面和卡槽承托平面均使用前壳内面
`Z = front_seam_z = 2.30 mm` 作为装配基准。`2.0 mm` 的屏幕凸起厚度
从该平面向后壳方向延伸；不得用 PCB 正面或背面替代这个承托基准。

卡槽不得以 PCB 的 `27.78 × 39.22 mm` 外框生成，也不得将 PCB 整体夹紧
在玻璃/屏幕凸起卡槽内。

在现有坐标系中，PCB 中心 Y 为 `-1.64 mm`，因此：

- PCB 顶边 Y：`-1.64 + 39.22 / 2 = 17.97 mm`
- 屏幕凸起顶边 Y：`17.97 - 5.00 = 12.97 mm`
- 屏幕凸起中心 Y：`12.97 - 29.00 / 2 = -1.53 mm`

卡槽中心使用 `(X, Y) = (0.00, -1.53) mm`，不再直接复用 PCB 中心。

## 六边形视窗

六边形保持正六边形、上下顶点朝向：

- 上下顶点距离：`23.50 mm`
- 左右对边距离：`23.50 × sqrt(3) / 2 = 20.35 mm`

比例约束的含义是六边形自身保持正六边形、Blossom 外形继续按原 SVG
等比生成，二者均不得沿单一轴拉伸。Blossom 外壳目标宽度保持
`56.0 mm`；只把独立六边形切口等比缩放到 `23.50 mm` 上下顶点距离，
不把整个外壳缩小到无法容纳屏幕 PCB 的尺寸。

定位使用屏幕凸起顶部，而不是 PCB、外壳或旧显示有效区中心：

1. 屏幕凸起顶部为 Y 向基准。
2. 六边形上顶点位于屏幕凸起顶部向下 `0.50 mm`，遮住顶部黑边。
3. 六边形下顶点位于上顶点向下 `23.50 mm`。
4. 屏幕凸起底边距六边形下顶点：
   `29.0 - 0.5 - 23.5 = 5.0 mm`。

因此底部 `3.0 mm` 非显示区、底部 `0.5 mm` 黑边以及额外 `1.5 mm`
遮挡余量均位于前壳覆盖区内，不会从六边形视窗露出。

横向以 `26.0 mm` 屏幕凸起中心对齐。六边形左右对边仅宽 `20.35 mm`，
每侧覆盖余量为 `(26.0 - 20.35) / 2 = 2.825 mm`，大于 `0.5 mm`
黑边宽度。

对应现有外壳坐标：

- 六边形上顶点 Y：`12.97 - 0.50 = 12.47 mm`
- 六边形中心 Y：`12.47 - 23.50 / 2 = 0.72 mm`
- 六边形下顶点 Y：`0.72 - 23.50 / 2 = -11.03 mm`

六边形中心使用 `(X, Y) = (0.00, 0.72) mm`，不得再次居中到外壳原点。

六边形切口只贯穿前壳显示窗口所需厚度，并在屏幕凸起正面平面终止；
不得延伸到 PCB 平面，也不得切坏卡槽、定位柱、压片或隐藏卡扣。

## 保持不变的结构

- USB 后开孔尺寸、圆角和位置。
- 蜂鸣器 `Ø12 × 11.5 mm` 内部净空及无声孔设计。
- 前壳刚性公扣、后壳弹性母扣和指甲拆卸凹位。
- 前后壳 Blossom 凹凸高度差 `1.5 mm`。
- Blossom 外形目标宽度 `56.0 mm`，SVG 等比缩放，不拉伸。
- 四个 PCB 定位柱的孔位基准。

## 自动验收

1. 参数检查：
   - 六边形上下顶点距离为 `23.50 mm`。
   - 六边形左右对边距离为 `20.35 mm`，允许计算舍入误差 `±0.01 mm`。
   - 屏幕凸起包络为 `26.0 × 29.0 mm`。
   - 卡槽内包络为 `26.30 × 29.30 mm`。
2. 位置检查：
   - 六边形上顶点距屏幕凸起顶部 `0.50 mm`。
   - 六边形下顶点距屏幕凸起底部 `5.00 mm`。
   - 六边形与屏幕凸起横向中心一致。
   - 屏幕凸起顶边距 PCB 顶边 `5.00 mm`，卡槽中心 Y 为 `-1.53 mm`。
   - 六边形中心 Y 为 `0.72 mm`。
   - 屏幕凸起正面与卡槽承托面同位于 `Z = 2.30 mm`。
3. 几何检查：
   - 六边形切口完全位于屏幕凸起投影内。
   - 卡槽与六边形切口、定位柱、压片的实体关系正确。
   - 屏幕、USB、蜂鸣器及卡扣实体干涉体积均为 `0`。
   - 前壳和后壳均保持单一有效实体。
4. 回归检查：
   - 现有卡扣咬合、活动间隙、蜂鸣器间隙和 USB 开口契约继续通过。

## 人工验收视图

- 前壳正面正投影：六边形上顶点从屏幕顶部黑边内侧开始，四周不露黑边，
  底部不露 `3 mm` 非显示区。
- 前壳内面正投影：能看到 `26.30 × 29.30 mm` 屏幕凸起卡槽、四根 PCB
  定位柱和左右压片，且卡槽不再沿 PCB 外框生成。
- 屏幕装配剖面：屏幕凸起正面与前壳承托平面贴合，PCB 位于卡槽后方，
  六边形切口不延伸到 PCB 平面。

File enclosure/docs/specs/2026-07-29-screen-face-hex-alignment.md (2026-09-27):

# Screen Face Pocket and Hex Alignment Implementation Plan

> **For agentic workers:** REQUIRED SUB-SKILL: Use superpowers:subagent-driven-development (recommended) or superpowers:executing-plans to implement this plan task-by-task. Steps use checkbox (`- [ ]`) syntax for tracking.

**Goal:** Rebuild the front shell so its locating pocket grips the measured
`26 × 29 mm` raised screen face and its regular hexagonal window is `23.5 mm`
point-to-point, top-referenced to hide the black border and lower non-display
area.

**Architecture:** Keep PCB-hole posts referenced to the PCB, but introduce
separate screen-face and window datums in `EnclosureParameters`. Build the
screen pocket from the face datum, translate the independent regular-hex cut
to its calculated Y centre, and expose actual FreeCAD bounds through the audit
so tests verify the exported solid rather than source constants alone.

**Tech Stack:** Python 3, pytest, FreeCAD 1.1 Python API, OpenCascade/Part,
FreeCAD GUI renderer.

## Global Constraints

- Blossom target width remains `56.0 mm`; its SVG is uniformly scaled and
  never stretched along one axis.
- The regular hex remains undistorted, with `23.50 mm` between top and bottom
  vertices and `20.35 mm` between left and right flats.
- Raised screen face is `26.0 × 29.0 mm`; pocket clearance is `0.15 mm` per
  side, producing `26.30 × 29.30 mm`.
- Raised-face top is `5.00 mm` below the PCB top; face centre Y is `-1.53 mm`.
- Hex top vertex is `0.50 mm` below the face top; hex centre Y is `0.72 mm`;
  its bottom vertex leaves `5.00 mm` of covered face.
- Raised-face front and the front-shell bearing plane are both `Z = 2.30 mm`.
- USB, buzzer, hidden latches, PCB locating posts and `1.5 mm` Blossom relief
  remain unchanged and unobstructed.

---

### Task 1: Screen-face and regular-hex parameter contract

**Files:**
- Modify: `codex_usb_pager/enclosure/tests/test_enclosure_params.py`
- Modify: `codex_usb_pager/enclosure/cad/enclosure_params.py`

**Interfaces:**
- Consumes: existing PCB centre and dimensions.
- Produces: `front_hex_point_to_point_mm`,
  `front_hex_across_flats_mm`, `front_hex_center_y_mm`,
  `screen_face_center_y_mm`, `screen_face_top_y_mm`,
  `screen_pocket_mm`.

- [ ] **Step 1: Write failing parameter tests**

```python
def test_hex_is_regular_and_top_referenced_to_screen_face():
    assert DEFAULTS.front_hex_point_to_point_mm == 23.5
    assert round(DEFAULTS.front_hex_across_flats_mm, 2) == 20.35
    assert DEFAULTS.screen_face_top_y_mm == 12.97
    assert DEFAULTS.front_hex_center_y_mm == 0.72
    assert DEFAULTS.front_hex_top_margin_mm == 0.50
    assert DEFAULTS.front_hex_bottom_margin_mm == 5.00

def test_screen_pocket_grips_measured_raised_face():
    assert DEFAULTS.screen_face_mm == (26.0, 29.0)
    assert DEFAULTS.screen_face_clearance_mm == 0.15
    assert DEFAULTS.screen_pocket_mm == (26.30, 29.30)
    assert DEFAULTS.screen_face_center_y_mm == -1.53
    assert DEFAULTS.screen_face_top_offset_from_pcb_mm == 5.0
```

- [ ] **Step 2: Verify the new tests fail for the old values**

Run:

```powershell
python -m pytest enclosure/tests/test_enclosure_params.py -q
```

Expected: failures showing the old `31.3 mm` point-to-point hex,
`25.30 × 29.22 mm` face and `0.20 mm` side clearance.

- [ ] **Step 3: Implement the datum properties**

Use these definitions in `EnclosureParameters`:

```python
front_hex_point_to_point_mm: float = 23.5
screen_face_mm: tuple[float, float] = (26.0, 29.0)
screen_face_clearance_mm: float = 0.15
screen_face_top_offset_from_pcb_mm: float = 5.0
screen_black_border_mm: float = 0.5

@property
def front_hex_across_flats_mm(self) -> float:
    return self.front_hex_point_to_point_mm * sqrt(3.0) / 2.0

@property
def screen_face_top_y_mm(self) -> float:
    return round(
        self.screen_pcb_center_y_mm
        + self.screen_pcb_mm[1] / 2.0
        - self.screen_face_top_offset_from_pcb_mm,
        2,
    )

@property
def screen_face_center_y_mm(self) -> float:
    return round(
        self.screen_face_top_y_mm - self.screen_face_mm[1] / 2.0,
        2,
    )

@property
def front_hex_center_y_mm(self) -> float:
    return round(
        self.screen_face_top_y_mm
        - self.screen_black_border_mm
        - self.front_hex_point_to_point_mm / 2.0,
        2,
    )
```

Keep `front_hex_across_corners_mm` as a compatibility property returning
`front_hex_point_to_point_mm`.

- [ ] **Step 4: Verify parameter tests and the complete pure-Python suite**

Run:

```powershell
python -m pytest enclosure/tests/test_enclosure_params.py -q
python -m pytest enclosure/tests -q
```

Expected: all tests pass except later geometry-contract tests that have not
yet been introduced.

- [ ] **Step 5: Commit Task 1**

```powershell
git add codex_usb_pager/enclosure/cad/enclosure_params.py codex_usb_pager/enclosure/tests/test_enclosure_params.py
git commit -m "feat: define measured screen face and hex datums"
```

### Task 2: Build the raised-face pocket and translated hex cut

**Files:**
- Modify: `codex_usb_pager/enclosure/tests/test_screen_mount_contract.py`
- Modify: `codex_usb_pager/enclosure/cad/build_blossom_enclosure.py`

**Interfaces:**
- Consumes: Task 1 datum properties.
- Produces: translated `FrontHexCut`, `ScreenPocketEnvelope`,
  face-centred locating frame and retainers; PCB posts remain PCB-centred.

- [ ] **Step 1: Write failing build-contract tests**

```python
def test_regular_hexagon_accepts_an_xy_centre():
    assert "def regular_hexagon(" in BUILD
    assert "center_x: float = 0.0" in BUILD
    assert "center_y: float = 0.0" in BUILD
    assert "DEFAULTS.front_hex_center_y_mm" in BUILD

def test_screen_frame_uses_face_centre_but_posts_keep_pcb_centres():
    mount = BUILD[BUILD.index("def build_screen_mount("):]
    assert "DEFAULTS.screen_face_center_y_mm" in mount
    assert "DEFAULTS.screen_post_centres_mm" in mount
    assert '"ScreenPocketEnvelope"' in BUILD
```

- [ ] **Step 2: Verify contract tests fail**

Run:

```powershell
python -m pytest enclosure/tests/test_screen_mount_contract.py -q
```

Expected: failure because the hex is origin-centred and the frame reuses the
PCB centre.

- [ ] **Step 3: Translate the regular hex without distorting it**

Change the helper signature and point creation:

```python
def regular_hexagon(
    across_flats: float,
    z: float,
    height: float,
    center_x: float = 0.0,
    center_y: float = 0.0,
):
    apothem = across_flats / 2.0
    radius = apothem / (sqrt(3.0) / 2.0)
    points = [
        App.Vector(
            center_x + radius * cos(pi / 6.0 + index * pi / 3.0),
            center_y + radius * sin(pi / 6.0 + index * pi / 3.0),
            z,
        )
        for index in range(6)
    ]
```

Create `front_hex_cut` with
`center_y=DEFAULTS.front_hex_center_y_mm`.

- [ ] **Step 4: Separate screen-face and PCB datums**

Inside `build_screen_mount()`:

```python
pocket_width, pocket_height = DEFAULTS.screen_pocket_mm
face_centre_y = DEFAULTS.screen_face_center_y_mm
```

Use `face_centre_y` for the rectangular frame, face envelope and retainers.
Continue using `DEFAULTS.screen_post_centres_mm` for all four posts. Create a
clearance solid named `ScreenPocketEnvelope` with dimensions
`26.30 × 29.30 mm`, based at `Z = 2.30 mm`, for audit and review only.

- [ ] **Step 5: Verify build-contract and full tests**

Run:

```powershell
python -m pytest enclosure/tests/test_screen_mount_contract.py -q
python -m pytest enclosure/tests -q
```

Expected: all pure-Python tests pass.

- [ ] **Step 6: Commit Task 2**

```powershell
git add codex_usb_pager/enclosure/cad/build_blossom_enclosure.py codex_usb_pager/enclosure/tests/test_screen_mount_contract.py
git commit -m "feat: align screen pocket and front hex"
```

### Task 3: Audit actual exported face, pocket and window geometry

**Files:**
- Modify: `codex_usb_pager/enclosure/tests/test_audit_contract.py`
- Modify: `codex_usb_pager/enclosure/tests/freecad_latch_geometry_contract.py`
- Modify: `codex_usb_pager/enclosure/cad/audit_blossom_enclosure.py`

**Interfaces:**
- Consumes: `FrontHexCut`, `ScreenFaceEnvelope`, `ScreenPocketEnvelope`.
- Produces: serialisable actual-bound metrics and FreeCAD assertions.

- [ ] **Step 1: Add failing audit-contract fields**

Require these report fields:

```python
required = {
    "front_hex_point_to_point_mm",
    "front_hex_across_flats_mm",
    "front_hex_center_y_mm",
    "screen_face_dimensions_mm",
    "screen_face_center_y_mm",
    "screen_pocket_dimensions_mm",
    "screen_pocket_center_y_mm",
    "screen_hex_top_margin_mm",
    "screen_hex_bottom_margin_mm",
    "screen_face_front_z_mm",
}
assert required <= set(AUDIT_SOURCE)
```

- [ ] **Step 2: Verify the audit tests fail**

Run:

```powershell
python -m pytest enclosure/tests/test_audit_contract.py -q
```

Expected: missing actual-bound fields.

- [ ] **Step 3: Report actual FreeCAD bounds**

Read `ScreenPocketEnvelope` and derive:

```python
hex_box = front_hex.BoundBox
face_box = screen_face.BoundBox
pocket_box = screen_pocket.BoundBox
```

Return rounded values for X/Y lengths and centres, plus:

```python
"screen_hex_top_margin_mm": round(face_box.YMax - hex_box.YMax, 3),
"screen_hex_bottom_margin_mm": round(hex_box.YMin - face_box.YMin, 3),
"screen_face_front_z_mm": round(face_box.ZMin, 3),
```

- [ ] **Step 4: Assert actual exported geometry**

Extend `freecad_latch_geometry_contract.py`:

```python
assert_close(report["front_hex_point_to_point_mm"], 23.50)
assert_close(report["front_hex_across_flats_mm"], 20.35)
assert_close(report["front_hex_center_y_mm"], 0.72)
assert report["screen_face_dimensions_mm"] == [26.0, 29.0]
assert report["screen_pocket_dimensions_mm"] == [26.3, 29.3]
assert_close(report["screen_face_center_y_mm"], -1.53)
assert_close(report["screen_pocket_center_y_mm"], -1.53)
assert_close(report["screen_hex_top_margin_mm"], 0.50)
assert_close(report["screen_hex_bottom_margin_mm"], 5.00)
assert_close(report["screen_face_front_z_mm"], 2.30)
```

Retain every existing USB, buzzer, latch, interference and single-solid
assertion.

- [ ] **Step 5: Verify pure-Python tests**

Run:

```powershell
python -m pytest enclosure/tests -q
```

Expected: all tests pass.

- [ ] **Step 6: Commit Task 3**

```powershell
git add codex_usb_pager/enclosure/cad/audit_blossom_enclosure.py codex_usb_pager/enclosure/tests/test_audit_contract.py codex_usb_pager/enclosure/tests/freecad_latch_geometry_contract.py
git commit -m "test: audit screen pocket and hex alignment"
```

### Task 4: Cold-build, render and final visual acceptance

**Files:**
- Modify if required by the new review object:
  `codex_usb_pager/enclosure/cad/render_blossom_review.py`
- Modify if required:
  `codex_usb_pager/enclosure/tests/test_render_contract.py`
- Generate ignored artifacts:
  `codex_usb_pager/enclosure/outputs/*`

**Interfaces:**
- Consumes: all Task 1–3 geometry and audit objects.
- Produces: FCStd, STEP, front/rear STL and seven stable review PNGs.

- [ ] **Step 1: Cold-build FreeCAD outputs**

Run from `codex_usb_pager`:

```powershell
"code=open(r'enclosure/cad/build_blossom_enclosure.py').read(); exec(compile(code, r'enclosure/cad/build_blossom_enclosure.py', 'exec'), {'__name__':'__main__','__file__':r'enclosure/cad/build_blossom_enclosure.py'})" | & 'C:\Program Files\FreeCAD 1.1\bin\FreeCADCmd.exe' -c
```

Expected: `BUILD PASS`.

- [ ] **Step 2: Run actual FreeCAD audit and geometry contract**

Run:

```powershell
"import sys; sys.argv=[r'enclosure/cad/audit_blossom_enclosure.py', r'enclosure/outputs/blossom-enclosure.FCStd']; code=open(r'enclosure/cad/audit_blossom_enclosure.py').read(); exec(compile(code, r'enclosure/cad/audit_blossom_enclosure.py', 'exec'), {'__name__':'__main__','__file__':r'enclosure/cad/audit_blossom_enclosure.py'})" | & 'C:\Program Files\FreeCAD 1.1\bin\FreeCADCmd.exe' -c

"import sys; sys.argv=[r'enclosure/tests/freecad_latch_geometry_contract.py', r'enclosure/outputs/blossom-enclosure.FCStd']; code=open(r'enclosure/tests/freecad_latch_geometry_contract.py').read(); exec(compile(code, r'enclosure/tests/freecad_latch_geometry_contract.py', 'exec'), {'__name__':'__main__','__file__':r'enclosure/tests/freecad_latch_geometry_contract.py'})" | & 'C:\Program Files\FreeCAD 1.1\bin\FreeCADCmd.exe' -c
```

Expected: audit fields match the spec and
`FREECAD LATCH CONTRACT PASS`.

- [ ] **Step 3: Render review images**

Run:

```powershell
$macro=(Resolve-Path 'enclosure\cad\render_blossom_review.FCMacro').Path
$process=Start-Process -FilePath 'C:\Program Files\FreeCAD 1.1\bin\FreeCAD.exe' -ArgumentList @($macro) -WindowStyle Hidden -Wait -PassThru
$process.ExitCode
```

Expected: exit code `0`, seven `1600 × 1200` PNGs and no lingering FreeCAD
process.

- [ ] **Step 4: Inspect front exterior, front inside and assembly views**

Confirm:

- outer Blossom remains `56.0 mm` and visually undistorted;
- hex is regular, centred X=0 and Y=0.72, with no black-border exposure;
- pocket follows the `26 × 29 mm` raised face, not the PCB outline;
- four PCB posts, both retainers, USB, buzzer and hidden latches remain clear.

- [ ] **Step 5: Run final suite and clean-state checks**

```powershell
python -m pytest enclosure/tests -q
git diff --check
git status --short --branch
```

Expected: all tests pass, no whitespace errors, only intentional tracked
changes before the final commit.

- [ ] **Step 6: Commit any renderer updates**

```powershell
git add codex_usb_pager/enclosure/cad/render_blossom_review.py codex_usb_pager/enclosure/tests/test_render_contract.py
git commit -m "test: review corrected screen and hex alignment"
```

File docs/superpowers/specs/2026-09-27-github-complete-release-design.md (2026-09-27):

# Codex USB Pager GitHub 完整发布设计

日期：2026-09-27

## 目标

把 Codex USB Pager 的程序与最终外壳模型整理到同一个独立 GitHub 仓库，
为后续下载、维护、构建、烧录和树脂打印提供一份清晰、可复现的发布源。

## 仓库设置

- 仓库名：`codex-usb-pager`
- 默认可见性：私有
- 默认分支：`main`
- 本地独立仓库：`C:\Users\28026\Documents\saltyfish\codex-usb-pager-github`
- 不上传原始 `saltyfish` 工作区中的其他项目。

## 内容结构

程序文件保持当前独立仓库结构不变，包括：

- RP2040-Zero 固件源码、测试和已验证 UF2；
- 主机端事件聚合、USB 通信、周余量读取和测试；
- Blossom 图形资源和程序设计历史；
- 程序交接说明与已安装 Hook 快照。

新增 `enclosure/`，只收录最终四卡扣外壳版本：

- `enclosure/cad/`：参数、建模、渲染和审计脚本；
- `enclosure/tests/`：外壳几何与源码约束测试；
- `enclosure/outputs/`：FreeCAD 源文件、STEP、前后壳 STL、`audit.json`、
  尺寸摘要和复核图；
- `enclosure/docs/`：最终外壳相关设计与实施文档。

旧基线外壳、旧 ZIP、构建缓存、Python 缓存、临时测试目录、对象文件和
重复输出不进入仓库。

## README

根目录 `README.md` 使用中文，按实际使用顺序说明：

1. 项目用途与仓库目录；
2. RP2040-Zero、屏幕、蜂鸣器接线；
3. USB 状态协议和屏显/蜂鸣器行为；
4. 直接使用已验证 UF2 的烧录步骤；
5. 从源码构建固件的方法；
6. 主机端工具的安装、启动与验证；
7. 最终四卡扣外壳文件选择、树脂打印建议和合盖顺序；
8. 测试命令、维护入口和已知环境注意事项。

README 不声称未重新验证的功能已经通过测试，并明确外壳输出必须以
`audit.json` 中 `passed=true` 且所有检查为真作为打印候选条件。

## 验证与安全

上传前执行以下检查：

- 文件清单与目录结构检查；
- 密钥、令牌、密码和私钥模式扫描；
- Git 暂存差异与工作区状态检查；
- 外壳审计结果读取与关键输出存在性检查；
- README 中的路径和命令与实际仓库一致性检查。

本任务不修改固件、主机端业务逻辑或外壳几何，不烧录设备，也不删除原始
工作区文件。

## 发布流程

1. 在本地独立仓库加入最终外壳文件并更新 README；
2. 完成验证后提交到 `main`；
3. 用户在 GitHub 完成一次登录；
4. 创建私有仓库 `codex-usb-pager`；
5. 配置 `origin` 并推送 `main`；
6. 打开仓库页面，核对 README 和文件目录可见。

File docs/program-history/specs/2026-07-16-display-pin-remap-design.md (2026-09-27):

# Display Pin Remap Design

## Goal

Move the ST7789 control signals to a compact PB5-PB9 group so the screen wiring can be resoldered cleanly and tested independently from the animation renderer.

## Wiring

| ST7789 pin | STM32F103 pin |
| --- | --- |
| GND | GND |
| VCC | 3.3V |
| SCL | PB9 |
| SDA | PB8 |
| RES | PB7 |
| DC | PB6 |
| BLK | PB5 |

## Transport

PB9 and PB8 are not an STM32F103 hardware SPI clock/data pair. The diagnostic firmware therefore uses software SPI. It starts at the established low diagnostic rate so wiring and display initialization are tested before performance tuning.

## Diagnostic Behavior

After reset, the display initializes and shows three static horizontal bars: red, green, and blue. Codex state rendering remains disabled during this test. A successful result is three stable colored bars with no black screen.

## Verification

1. Automated tests assert the pin mapping and diagnostic transport configuration.
2. The firmware builds without errors.
3. STM32CubeProgrammer verifies the programmed image.
4. The user visually confirms the RGB bars before animation rendering is restored.

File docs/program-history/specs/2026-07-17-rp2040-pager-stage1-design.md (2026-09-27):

# RP2040 Pager Stage 1 Design

## Goal

Bring up the RP2040-Zero as the new Codex pager core using USB CDC and its onboard WS2812 status LED before the replacement ST7789 display arrives.

## Hardware

- Controller: RP2040-Zero with 264 KB SRAM and 2 MB flash.
- Onboard status LED: WS2812 data input on GP16.
- Maximum LED brightness: 8 percent.
- Buzzer reserved for stage 1 follow-up: active low three-pin module, IO on GP14, VCC on 3V3, and common GND.
- No display or buzzer is connected during the initial USB and LED bring-up.

## Future Display Pinout

The replacement seven-pin ST7789 display will use the physically sequential left-side pads:

| ST7789 | RP2040-Zero |
| --- | --- |
| GND | GND |
| VCC | 3V3 |
| SCL | GP29 |
| SDA | GP28 |
| RES | GP27 |
| DC | GP26 |
| BLK | GP15 |

GP29 and GP28 will use a PIO state machine with DMA rather than a fixed-function SPI peripheral. Display implementation is outside stage 1.

## Firmware Architecture

- Build with the Raspberry Pi Pico SDK in C/C++.
- Expose a USB CDC serial interface compatible with the existing line-oriented pager protocol.
- Parse complete newline-terminated snapshots without blocking the animation loop.
- Keep the most recent valid snapshot and transition to OFFLINE after the existing host timeout.
- Drive the single WS2812 from a dedicated PIO state machine on GP16.
- Run stage 1 on one core. Reserve multicore rendering and display DMA for the display stage.

## State Behavior

| State | LED behavior | Buzzer behavior after follow-up |
| --- | --- | --- |
| IDLE | Low-brightness cool white | Silent |
| RUNNING | Smooth blue-purple breathing | Silent |
| MULTI | Alternating blue and purple | Silent |
| WAIT | Amber double flash | Two very short pulses |
| DONE | Soft green pop | One very short pulse |
| ERROR | Red triple flash | Three very short pulses |
| OFFLINE | Dim red slow flash | Silent |

All LED effects use a perceptual brightness curve and never exceed 8 percent output.

## Protocol Compatibility

Stage 1 accepts the existing snapshot format, including state, running count, waiting count, completed count, balance, and event fields. Multiple running tasks select MULTI. Unknown or malformed lines do not replace the last valid state.

## Verification

1. Unit tests cover parsing, state selection, timeout behavior, and LED effect bounds.
2. The Pico SDK build produces a UF2 image for RP2040.
3. Copying the UF2 to RPI-RP2 reboots the board as a USB CDC device.
4. A host smoke test sends IDLE, RUNNING, MULTI, WAIT, DONE, ERROR, and OFFLINE snapshots and verifies the corresponding onboard LED behavior.
5. Stage 1 is accepted before any display or buzzer wiring is added.

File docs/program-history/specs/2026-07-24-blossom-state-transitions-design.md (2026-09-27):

# Blossom State Transition Design

## Goal

Replace generic scene cross-fades between `OFFLINE`, `READY`, and `RUNNING`
with continuous Blossom motion that communicates the state change itself.
The animation must remain responsive to Codex events, preserve the official
Blossom geometry, and avoid visible seams, image swaps, or paused rotation.

This design also defines the return to `READY` after a run or the existing
completion hold finishes.

## Steady States

### OFFLINE

- The Blossom is separated into six complete woven pieces.
- The pieces use a restrained blue-gray color: logical RGB `#738094`.
- Position, angle, drift phase, and drift period differ for every piece.
- Motion is slow and irregular. The pieces never gather while offline.
- Weekly balance is hidden.

### READY

- The same six pieces are evenly spaced around the center.
- All pieces use green: logical RGB `#39D298`.
- The six-piece group revolves slowly around the center at a constant speed.
- Each piece preserves its orientation relative to the revolving group.
- The weekly remaining value is centered as an integer without a percent sign.

### RUNNING

- The six pieces form one exact, seamless official Blossom.
- The complete Blossom uses a deeper purple: logical RGB `#6449E0`.
- It rotates continuously with the existing subtle scale breathing.
- Rotation uses elapsed time rather than frame count, so a slow frame cannot
  permanently alter speed or introduce an intentional pause.
- Weekly balance is hidden.

## Lossless Six-Piece Asset

The asset generator derives six mutually exclusive masks from the existing
official Blossom mask. Every lit source pixel belongs to exactly one piece.
At the assembled origin:

`piece_0 | piece_1 | ... | piece_5 == official_blossom`

The six masks may touch but cannot overlap or leave uncovered pixels. Their
union is the running-state image. Firmware does not replace the assembled
pieces with a second logo bitmap at the end of a transition.

This invariant removes the seam and geometry jump seen when independent
outlined petals were cross-faded into a separate full-logo image.

## State Transitions

All timings start immediately when the new host state is accepted. Smoothstep
or smootherstep easing is used for position, orientation, scale, color, and
text opacity. No transition begins with a stationary delay.

### READY To RUNNING

1. Over 900 ms, the green pieces leave the ready orbit and follow continuous
   curved paths into their exact assembled positions. The weekly value fades
   out during the first 650 ms.
2. The seamless green Blossom holds for 150 ms. It does not rotate yet.
3. Over 400 ms, the complete Blossom changes from `#39D298` to `#6449E0`.
4. Rotation starts only after the color transition completes and then remains
   continuous for the entire running state.

Total time to steady `RUNNING` is 1,450 ms. Visual response begins on the first
rendered frame after the state event.

### RUNNING Or DONE To READY

1. Over 350 ms, the complete Blossom decelerates smoothly and stops at the
   nearest visually balanced orientation.
2. Over 350 ms, purple changes to ready green while the Blossom remains whole.
3. Over 800 ms, the six masks separate from their exact assembled positions
   and move to the six evenly spaced ready-orbit positions.
4. The weekly value fades in during the final 550 ms. Slow ready revolution
   begins as the separation finishes, with matched angular velocity at the
   handoff.

The existing `DONE` presentation and hold remain intact. When that hold ends,
the same whole-Blossom-to-ready separation sequence is used.

### OFFLINE To READY

1. Each gray piece immediately reduces its independent drift and angular
   wobble.
2. Over 1,200 ms, all six pieces follow separate curved paths to the evenly
   spaced ready ring, correct their orientations, and change from `#738094`
   to `#39D298`.
3. The weekly value fades in over the final 500 ms.
4. Ready revolution begins with continuous phase and velocity as the pieces
   reach their destinations.

This path does not assemble the full Blossom. It directly converts irregular
offline scatter into the ordered ready orbit.

### READY To OFFLINE

When the host heartbeat expires or the desktop bridge exits, the ready orbit
loses synchronization over 900 ms. The pieces change from green to blue-gray,
separate toward their offline anchor positions, and acquire their individual
drift phases. The weekly value fades out during the first 450 ms.

## State And Event Flow

The host continues to send the existing state snapshot and heartbeat. A newly
received state updates the transition target immediately. Firmware owns all
animation time and does not require per-frame USB traffic.

If a new state arrives during a transition, the next transition starts from
the currently rendered pose, color, angular velocity, and text opacity. It
must not restart from a canned endpoint. Priority and multi-task state
selection remain controlled by the existing pager core.

Heartbeat timeout remains the source of `OFFLINE`. A valid snapshot received
while offline starts `OFFLINE -> READY`, or transitions directly toward a
higher-priority active state when Codex is already running.

## Rendering And Performance

- Reuse the existing packed RGB565 double-buffered scene and DMA transport.
- Precompute the six source masks at build time. Do not allocate per frame.
- Use fixed-point interpolation for transforms and RGB565 color changes.
- Clear and redraw only the established animated scene region.
- Frame timing remains elapsed-time based with a 25 ms target.
- No transition may add a deliberate wait, full-screen clear, row-by-row DMA
  restart, or second full-resolution transition buffer.

## Verification

Host and firmware tests must cover:

- every official Blossom pixel belongs to exactly one of the six masks;
- the assembled six-mask union equals the official Blossom byte for byte;
- no uncovered seam exists at the `READY -> RUNNING` endpoint;
- state color endpoints match the three logical RGB values;
- position, rotation, scale, and opacity are continuous at every phase
  boundary;
- running rotation begins after recoloring and never intentionally pauses;
- running or done returns through the green separation animation;
- offline recovery reaches the ordered ready orbit without full assembly;
- a state interruption continues from the current rendered pose;
- weekly balance fades only on transitions that enter or leave `READY`;
- the host build, RP2040 firmware build, and existing transport tests pass.

Physical verification on the 240 x 240 ST7789 panel must confirm:

- green and deep purple are clearly distinguishable;
- the assembled Blossom has no visible gaps;
- no horizontal refresh band or full-frame flash appears;
- transitions begin promptly when a Codex state changes;
- steady running animation remains smooth at the achieved frame rate.

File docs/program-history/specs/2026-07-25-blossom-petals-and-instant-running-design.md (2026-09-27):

# Blossom Petals And Instant Running Design

## Scope

This change corrects two behaviors in the RP2040-Zero Codex pager:

1. READY and OFFLINE must use six closed Blossom petals whose proportions and
   ribbon thickness match the canonical Blossom asset.
2. RUNNING must be sent as soon as Codex accepts a user prompt, without waiting
   for the buffered JSONL session event.

The display wiring, ST7789 profile, weekly balance display, buzzer behavior,
USB CDC protocol, and existing state priority remain unchanged.

## Canonical Visual Source

`assets/openai-blossom.svg` is the only geometry source.

The six petal masks are generated from the six outer hole contours in that SVG:

- Preserve each original hole contour without resizing or reshaping it.
- Expand each hole outward by the canonical ribbon width of 15.889 SVG units.
- Subtract the original hole from the expanded region.
- The result is one closed ring with a continuous inner and outer edge.
- Generate all six rings at one shared scale and one shared ribbon width.
- Do not independently fit, crop, or normalize individual petals.

The full assembled RUNNING logo continues to use the canonical complete
Blossom alpha mask. The six ring masks are not permanently overlaid at the
center because that would produce incorrect overlaps.

## State Motion

### READY

- Six green closed petals orbit the center at equal angular spacing.
- All petals use the same source scale and ribbon width.
- Weekly balance remains centered as digits only.

### READY To RUNNING

- The first RUNNING frame changes the petals to the running purple palette.
- The six petals begin moving toward their canonical center positions
  immediately.
- The aggregation lasts 800 ms.
- Near the end of aggregation, the six petal layer fades out while the complete
  canonical Blossom layer fades in at the same position and scale.
- The crossfade must not expose a gap or show six closed rings stacked at full
  opacity.
- Once assembled, the complete Blossom starts the existing faster RUNNING
  rotation.

### RUNNING To READY

- Rotation eases to a stop.
- The complete purple Blossom crossfades to six green closed petals.
- The petals separate to their READY orbit without a size jump.

### OFFLINE To READY

- Offline petals retain their irregular drifting positions.
- They recolor to READY green and settle into the regular orbit.
- They do not assemble into the full Blossom during this transition.

## Immediate RUNNING Detection

The existing JSONL watcher remains useful for completion and fallback events,
but it cannot be the primary prompt-start signal because Codex may buffer its
write for tens of seconds.

The daemon adds an incremental watcher for:

`%USERPROFILE%\.codex\logs_2.sqlite`

The watcher:

- Opens the database read-only and remains compatible with WAL mode.
- Records the current maximum `logs.id` at startup to ignore stale entries.
- Polls only rows with `id > last_id`.
- Detects `target = codex_core::session::handlers` entries whose body contains
  a `Submission` with `op: UserInput`.
- Uses the row's `thread_id` as the task identifier.
- Records `UserPromptSubmit` and sends the aggregate snapshot immediately.
- Advances its cursor even for irrelevant rows.
- Reopens the database after replacement, transient locking, or schema access
  failure.

The target from prompt acceptance to serial write is under 100 ms on the local
machine. The existing JSONL detection remains as a deduplicated fallback.

## Data Flow

1. Codex accepts the user's prompt.
2. Codex writes the submission log row.
3. The SQLite watcher detects the new row.
4. `RuntimeStore` records the task as RUNNING.
5. The daemon sends the aggregate `STATE ...` line over USB CDC.
6. RP2040 changes the first display frame to running purple and starts
   aggregation.

## Error Handling

- Missing or locked log database: continue using JSONL and heartbeat fallback.
- Duplicate SQLite and JSONL prompt events: update the same task row without
  creating an additional task.
- USB temporarily unavailable: retain runtime state and retry on heartbeat.
- Invalid or missing `thread_id`: ignore the row and advance the log cursor.
- Asset generation failure: do not replace the existing generated C asset.

## Verification

Automated checks must prove:

- Six petal masks exist and all are closed rings.
- Every mask uses the same ribbon width within raster tolerance.
- All six masks use a shared global scale.
- The full Blossom remains unchanged.
- Aggregation starts purple at elapsed time zero.
- Aggregation ends on the canonical full mask without a size jump.
- A new SQLite UserInput row produces one immediate RUNNING event.
- Old, irrelevant, duplicate, missing-thread, and locked-database cases are
  handled safely.
- Existing host tests, Python tests, RP2040 build, SRAM size check, and USB
  flash verification pass.

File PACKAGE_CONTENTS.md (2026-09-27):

# Package Contents

The ZIP beside this folder contains the current program handoff only:

- `PROGRAM_HANDOFF.md` and `NEW_SESSION_PROMPT.txt`
- active RP2040 firmware and firmware tests
- computer-side pager tools and Python tests
- canonical Blossom asset and generated mask source
- program design plans/specifications
- current verified UF2 image
- installed pager hook scripts and hook JSON snapshot

Build folders, Python caches, temporary test directories, STM32 third-party
libraries, enclosure/CAD files, and unrelated workspace files are excluded.

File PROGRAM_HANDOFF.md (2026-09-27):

# Codex USB Pager Program Handoff

Updated: 2026-08-21

This document is the source of truth for the program side of the finished
Codex pager. The enclosure is complete and is intentionally outside this
handoff.

## 1. Current Hardware

- Controller: RP2040-Zero, RP2040 dual-core Cortex-M0+, 2 MB flash.
- Display: 1.3-inch ST7789 IPS, 240 x 240, seven-pin SPI module.
- Buzzer: three-pin active buzzer module marked `Low level trigger`.
- Onboard status LED: WS2812 on GP16.
- Host connection: USB CDC over the RP2040-Zero USB-C connector.

### Wiring

| Module pin | RP2040-Zero pin | Notes |
| --- | --- | --- |
| Display GND | GND | Common ground |
| Display VCC | 3V3 | Do not use 5 V |
| Display SCL | GP12 | PIO SPI clock |
| Display SDA | GP11 | PIO SPI data |
| Display RES | GP10 | Reset |
| Display DC | GP9 | Command/data |
| Display BLK | GP8 | Backlight, high = on |
| Buzzer GND | GND | Common ground |
| Buzzer IO | GP14 | Active-low trigger |
| Buzzer VCC | 3V3 | Module power |

The bare two-pin passive buzzer is not used.

## 2. USB Protocol

The computer sends one newline-terminated ASCII snapshot over USB CDC:

```text
STATE <state> RUN=<n> WAIT=<n> DONE=<n> BAL=<token> EV=<event>\n
```

Example:

```text
STATE RUNNING RUN=2 WAIT=0 DONE=14 BAL=82 EV=NONE
```

States: `IDLE`, `RUNNING`, `WAIT`, `DONE`, `ERROR`. If no valid snapshot is
received for 8 seconds, the firmware enters `OFFLINE`. `RUNNING` with
`RUN>1` selects the multi-task scene.

Events are edge notifications: `NONE`, `WAIT`, `DONE`, `ERROR`.

## 3. Current Visual Behavior

- `OFFLINE`: six grey Blossom pieces fall and remain irregularly piled near
  the bottom, bounded by the white hexagon.
- `IDLE/READY`: six green pieces are evenly separated around the center and
  orbit slowly. Weekly balance is shown as a number in the center.
- `RUNNING`: assembled purple Blossom rotates with acceleration and a scale
  pulse around a fixed center.
- Multi-task running: the main Blossom remains in front; additional blurred
  colored Blossom layers rotate behind it, capped by the firmware design.
- `WAIT`: amber confirmation scene.
- `DONE`: no check mark; the completed scene pulses every three seconds.
- The white hexagon is the reserved visible boundary used by the finished
  enclosure opening.

Do not redraw the Blossom or change its center, petal proportions, hexagon,
palette, or transition choreography unless the user explicitly requests it.

## 4. Buzzer Rules

- `EV=WAIT`: three quiet short pulses.
- `EV=DONE`: one quiet short pulse.
- `EV=ERROR`: five quiet short pulses.
- `RUNNING`, `IDLE`, `OFFLINE`, heartbeats, and normal tool activity are
  silent.
- The firmware uses 25 ms on and 180 ms gap, non-blocking.

### False-beep fix made on 2026-08-21

The false beeps did not originate in the RP2040 buzzer driver. They came from
host events being interpreted as final completion:

1. A hidden approval-review turn produced `task_complete` while the visible
   user task was still running.
2. Network reconnect/abort produced `turn_aborted`, previously mapped to
   completion.
3. A context-free Stop/notify path duplicated completion notifications.

Current host behavior:

- Hidden internal approval-review messages and their completion are ignored.
- `turn_aborted` changes the task to `IDLE` and emits no buzzer event.
- Stop Hooks and legacy notify-DONE calls do not decide completion.
- Final completion comes from the semantic session JSONL `task_complete`.
- With multiple tasks, an early completion is retained silently. `DONE` is
  emitted once only after no task remains in RUNNING or WAIT.
- `PermissionRequest` remains the only normal source of `EV=WAIT`.

Relevant files:

- `tools/session_watcher.py`
- `tools/pager_hook_runtime.py`
- `tools/pager_runtime.py`
- `tools/pager_daemon.py`
- `ports/rp2040-zero/firmware/src/buzzer.c`

## 5. Host Signal Pipeline

The active host hook is:

```text
C:\Users\28026\.codex\hooks\codex_pager.py
```

It locates this project at:

```text
C:\Users\28026\Documents\saltyfish\codex_usb_pager\tools
```

The active configuration has two compatible notification entry points:

- `C:\Users\28026\.codex\hooks.json` for prompt, tool, permission, and Stop
  hooks.
- `notify` in `C:\Users\28026\.codex\config.toml` calling
  `codex_notify_pager.py` after a turn.

Both eventually pass through `pager_hook_runtime.py`. Stop is deliberately
ignored there, so duplicate DONE notifications cannot reach the buzzer.

The daemon also watches:

- `C:\Users\28026\.codex\logs_2.sqlite` for prompt-start activity.
- `C:\Users\28026\.codex\sessions\*.jsonl` for semantic turn events.
- Codex usage data for weekly balance updates.

Runtime aggregation is stored in:

```text
%TEMP%\codex_pager_runtime.sqlite
```

Only one `pager_daemon.py` process should run.

## 6. Important Source Files

- `ports/rp2040-zero/firmware/`: active RP2040 firmware.
- `ports/rp2040-zero/tests/`: native firmware behavior tests.
- `ports/rp2040-zero/README.md`: build, protocol, wiring, and acceptance notes.
- `tools/`: host hooks, daemon, USB transport, balance reader, and tests.
- `assets/openai-blossom.svg`: canonical Blossom source.
- `Core/Inc/blossom_asset.h` and `Core/Src/blossom_asset.c`: generated packed
  Blossom mask used by the RP2040 target.
- `docs/superpowers/plans` and `docs/superpowers/specs`: program design history.

## 7. Build, Test, and Flash

Build the RP2040 firmware through the ASCII-path helper:

```powershell
powershell -ExecutionPolicy Bypass -File tools/build_rp2040.ps1
```

Output:

```text
build-rp2040\codex_pager_rp2040.uf2
```

Current packaged UF2 SHA-256:

```text
BEA1BA1EAFFA862EFF384F55C65FCB4C9D2883CC2602B250E1D0FD3D482FAD3A
```

To flash: hold BOOT while connecting or resetting the RP2040-Zero, wait for
the `RPI-RP2` drive, then copy the UF2 to that drive. The drive disappears
after a successful flash. Host-only hook fixes do not require reflashing.

Host regression command:

```powershell
python -m pytest tools/test_pager_runtime.py tools/test_session_watcher.py tools/test_pager_state.py tools/test_codex_log_watcher.py tools/test_pager_transport.py -q
```

Latest result on 2026-08-21: 50 tests passed.

## 8. Known Local Environment Issues

- Some old pytest temporary folders have Windows permission residue. Use a
  fresh unique `--basetemp` or elevated test run. This does not affect pager
  runtime behavior. Cleanup is recommended later.
- The primary Codex session JSONL was about 536 MB during the last diagnosis.
  Archive/rotate it only after fully closing Codex. This is recommended to
  prevent future watcher slowdown.
- The working tree contains many uncommitted and untracked project files.
  Do not reset, clean, or delete them automatically.
- Build through `tools/build_rp2040.ps1`; older toolchains failed on paths with
  Chinese characters and occasionally left PDB/build processes behind.

## 9. First Checks in a New Session

1. Read this file and `ports/rp2040-zero/README.md` before editing.
2. Confirm the pager appears as USB CDC and only one daemon is alive.
3. Read the runtime snapshot; during work it must be `RUNNING` with
   `EV=NONE`.
4. Run the host regression tests before modifying the hook pipeline.
5. For a buzzer complaint, first log the received host event and snapshot.
   Do not change the firmware buzzer timings until the host source is proven.
6. Preserve multi-task aggregation: individual task completion must stay
   silent until the last active task finishes.

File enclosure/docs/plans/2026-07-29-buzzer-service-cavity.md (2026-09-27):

# Buzzer Service Cavity Implementation Plan

> **For agentic workers:** REQUIRED SUB-SKILL: Use superpowers:subagent-driven-development (recommended) or superpowers:executing-plans to implement this plan task-by-task. Steps use checkbox (`- [ ]`) syntax for tracking.

**Goal:** Replace the buzzer-matched rear relief with a large, non-cylindrical left-petal service cavity while preserving the complete visible enclosure and all closure features.

**Architecture:** Keep the cylindrical 12.0 x 11.5 mm buzzer object only as an assembly-validation envelope. Build a separate rounded rectangular service window, clip it to a 1.50 mm protected Blossom core, subtract only its new volume outside the existing electronics cavity, and audit the resulting exterior wall, keepouts, and assembly. Update the review renderer so the enlarged service volume is directly visible beside the buzzer envelope.

**Tech Stack:** Python 3, FreeCAD 1.1 Part workbench, pytest, PowerShell.

## Global Constraints

- Blossom exterior width remains 56.0 mm with unchanged SVG proportions.
- Front and rear relief depth remains 1.5 mm.
- Buzzer validation envelope remains 12.0 mm diameter x 11.5 mm high at centre (-9.0, 4.36) mm.
- Service window bounds are X = -28.0 to -12.0 mm, Y = -5.5 to 18.0 mm, and Z = 4.30 to 18.30 mm.
- Service window corner radius is 3.0 mm.
- The service cavity keeps at least 1.50 mm of protected exterior wall.
- Top locator tongues/sockets, lower hidden latches, screen mounts, USB structures, and exterior appearance remain unchanged.
- No buzzer sound opening is added.

---

### Task 1: Define the service-cavity datum contract

**Files:**
- Modify: `codex_usb_pager/enclosure/cad/enclosure_params.py`
- Create: `codex_usb_pager/enclosure/tests/test_buzzer_service_cavity_contract.py`

**Interfaces:**
- Consumes: `EnclosureParameters`, the approved screen PCB rear plane, and the existing internal envelope.
- Produces: `buzzer_service_window_mm`, `buzzer_service_window_origin_mm`, `buzzer_service_corner_radius_mm`, `buzzer_service_wall_mm`, `buzzer_front_z_mm`, and `buzzer_service_depth_mm`.

- [ ] **Step 1: Write the failing parameter tests**

```python
from pathlib import Path

from enclosure.cad.enclosure_params import DEFAULTS

BUILD = Path("enclosure/cad/build_blossom_enclosure.py").read_text(
    encoding="utf-8"
)

def test_large_buzzer_service_window_has_approved_datums():
    assert DEFAULTS.buzzer_service_window_mm == (16.0, 23.5)
    assert DEFAULTS.buzzer_service_window_origin_mm == (-28.0, -5.5)
    assert DEFAULTS.buzzer_service_corner_radius_mm == 3.0
    assert DEFAULTS.buzzer_service_wall_mm == 1.50
    assert DEFAULTS.buzzer_front_z_mm == 4.30
    assert DEFAULTS.buzzer_service_depth_mm == 14.0

def test_buzzer_validation_envelope_remains_measured_hardware():
    assert DEFAULTS.buzzer_clearance_mm == (12.0, 11.5)
    assert DEFAULTS.buzzer_centre_mm == (-9.0, 4.36)
```

- [ ] **Step 2: Run the focused test and verify RED**

Run:

```powershell
python -m pytest enclosure/tests/test_buzzer_service_cavity_contract.py -q
```

Expected: FAIL because the `buzzer_service_*` parameters and derived properties do not exist.

- [ ] **Step 3: Add the exact parameters and derived properties**

Add these fields beside the existing buzzer dimensions:

```python
    buzzer_service_window_mm: tuple[float, float] = (16.0, 23.5)
    buzzer_service_window_origin_mm: tuple[float, float] = (-28.0, -5.5)
    buzzer_service_corner_radius_mm: float = 3.0
    buzzer_service_wall_mm: float = 1.50
```

Add these properties to `EnclosureParameters`:

```python
    @property
    def buzzer_front_z_mm(self) -> float:
        return round(
            self.front_seam_z_mm + self.screen_face_to_pcb_mm,
            2,
        )

    @property
    def buzzer_service_depth_mm(self) -> float:
        rear_inner_z = (
            self.front_seam_z_mm + self.internal_envelope_mm[2]
        )
        return round(rear_inner_z - self.buzzer_front_z_mm, 2)
```

- [ ] **Step 4: Run the focused test and the full pure-Python suite**

Run:

```powershell
python -m pytest enclosure/tests/test_buzzer_service_cavity_contract.py -q
python -m pytest enclosure/tests -q
```

Expected: the focused tests PASS and the existing suite remains green.

- [ ] **Step 5: Commit the datum contract**

```powershell
git add codex_usb_pager/enclosure/cad/enclosure_params.py codex_usb_pager/enclosure/tests/test_buzzer_service_cavity_contract.py
git commit -m "feat: define enlarged buzzer service cavity"
```

---

### Task 2: Build and audit the protected left-petal cavity

**Files:**
- Modify: `codex_usb_pager/enclosure/tests/test_buzzer_service_cavity_contract.py`
- Modify: `codex_usb_pager/enclosure/cad/build_blossom_enclosure.py`
- Modify: `codex_usb_pager/enclosure/cad/audit_blossom_enclosure.py`
- Modify: `codex_usb_pager/enclosure/tests/test_audit_contract.py`
- Modify: `codex_usb_pager/enclosure/tests/freecad_latch_geometry_contract.py`

**Interfaces:**
- Consumes: the Task 1 service window parameters and `rounded_rectangle_prism()`.
- Produces: FreeCAD objects `BuzzerServiceWindow`, `BuzzerServiceEnvelope`, `BuzzerServiceCavity`, and `BuzzerServiceExteriorGuard`; serialisable audit fields for size, depth, breach, and keepout intersections.

- [ ] **Step 1: Extend the source contract with the desired non-cylindrical build**

Append:

```python
def test_build_uses_a_protected_non_cylindrical_service_cavity():
    for name in (
        '"BuzzerServiceWindow"',
        '"BuzzerServiceEnvelope"',
        '"BuzzerServiceCavity"',
        '"BuzzerServiceExteriorGuard"',
    ):
        assert name in BUILD
    assert "buzzer_service_window.common(buzzer_service_core)" in BUILD
    assert "buzzer_service_envelope.cut(cavity)" in BUILD
    assert "rear_body = rear_body.cut(buzzer_service_cavity)" in BUILD
    assert "buzzer_clearance = buzzer_envelope.cut(cavity)" not in BUILD
```

- [ ] **Step 2: Run the source contract and verify RED**

Run:

```powershell
python -m pytest enclosure/tests/test_buzzer_service_cavity_contract.py -q
```

Expected: FAIL because no service-cavity objects or clipped cutter exist.

- [ ] **Step 3: Build the window, protected core, and physical cavity**

Replace the cylindrical `buzzer_clearance` production cutter with:

```python
    buzzer_front_z = DEFAULTS.buzzer_front_z_mm
    buzzer_envelope = Part.makeCylinder(
        DEFAULTS.buzzer_clearance_mm[0] / 2.0,
        DEFAULTS.buzzer_clearance_mm[1],
        App.Vector(
            DEFAULTS.buzzer_centre_mm[0],
            DEFAULTS.buzzer_centre_mm[1],
            buzzer_front_z,
        ),
    )
    service_x, service_y = DEFAULTS.buzzer_service_window_origin_mm
    service_width, service_height = DEFAULTS.buzzer_service_window_mm
    buzzer_service_window = rounded_rectangle_prism(
        service_width,
        service_height,
        DEFAULTS.buzzer_service_corner_radius_mm,
        DEFAULTS.buzzer_service_depth_mm,
        App.Vector(service_x, service_y, buzzer_front_z),
    )
    service_guard_ratio = (
        DEFAULTS.blossom_target_width_mm
        - 2.0 * DEFAULTS.buzzer_service_wall_mm
    ) / DEFAULTS.blossom_target_width_mm
    buzzer_service_core = Part.makeLoft(
        [
            wire_profile(
                outer_wire,
                svg_scale * service_guard_ratio,
                DEFAULTS.front_seam_z_mm - 0.1,
            ),
            wire_profile(
                outer_wire,
                svg_scale * service_guard_ratio,
                DEFAULTS.front_seam_z_mm
                + DEFAULTS.internal_envelope_mm[2],
            ),
            wire_profile(
                outer_wire,
                svg_scale * 0.965 * service_guard_ratio,
                DEFAULTS.maximum_thickness_mm
                - DEFAULTS.buzzer_service_wall_mm,
            ),
        ],
        True,
        True,
    )
    buzzer_service_envelope = (
        buzzer_service_window.common(buzzer_service_core)
    )
    buzzer_service_cavity = buzzer_service_envelope.cut(cavity)
    buzzer_service_exterior_guard = rear_body.cut(buzzer_service_core)
    service_guard_overlap = buzzer_service_cavity.common(
        buzzer_service_exterior_guard
    ).Volume
    if service_guard_overlap > 1e-5:
        raise RuntimeError(
            "Buzzer service cavity breaches its 1.50 mm guard by "
            f"{service_guard_overlap:.6f} mm^3"
        )
    rear_body = rear_body.cut(buzzer_service_cavity)
    add_feature(document, "BuzzerEnvelope", buzzer_envelope)
    add_feature(document, "BuzzerServiceWindow", buzzer_service_window)
    add_feature(document, "BuzzerServiceEnvelope", buzzer_service_envelope)
    add_feature(document, "BuzzerServiceCavity", buzzer_service_cavity)
    add_feature(
        document,
        "BuzzerServiceExteriorGuard",
        buzzer_service_exterior_guard,
    )
```

Add `buzzer_service_envelope` to `closure_keepouts`. Retain the circular
`BuzzerEnvelope` solely for obstruction checks and the small screen-retainer
manufacturing notch.

- [ ] **Step 4: Run the source contract and verify GREEN**

Run:

```powershell
python -m pytest enclosure/tests/test_buzzer_service_cavity_contract.py -q
```

Expected: PASS.

- [ ] **Step 5: Add failing audit-contract assertions**

Require these object names in `REQUIRED_CLOSURE` and
`test_audit_contract.py`:

```python
    "BuzzerServiceWindow",
    "BuzzerServiceEnvelope",
    "BuzzerServiceCavity",
    "BuzzerServiceExteriorGuard",
```

Require these report fields:

```python
    "buzzer_service_window_dimensions_mm",
    "buzzer_service_envelope_dimensions_mm",
    "buzzer_service_cavity_volume_mm3",
    "buzzer_service_exterior_breach_mm3",
    "buzzer_service_locator_obstruction_mm3",
    "buzzer_service_latch_obstruction_mm3",
```

Run:

```powershell
python -m pytest enclosure/tests/test_audit_contract.py -q
```

Expected: FAIL because the new object requirements and report fields are absent.

- [ ] **Step 6: Extend `audit_document()` with physical service-cavity facts**

Load the shapes:

```python
    buzzer_service_window = document.getObject(
        "BuzzerServiceWindow"
    ).Shape
    buzzer_service_envelope = document.getObject(
        "BuzzerServiceEnvelope"
    ).Shape
    buzzer_service_cavity = document.getObject(
        "BuzzerServiceCavity"
    ).Shape
    buzzer_service_exterior_guard = document.getObject(
        "BuzzerServiceExteriorGuard"
    ).Shape
```

Add:

```python
        "buzzer_service_window_dimensions_mm": [
            round(buzzer_service_window.BoundBox.XLength, 3),
            round(buzzer_service_window.BoundBox.YLength, 3),
            round(buzzer_service_window.BoundBox.ZLength, 3),
        ],
        "buzzer_service_envelope_dimensions_mm": [
            round(buzzer_service_envelope.BoundBox.XLength, 3),
            round(buzzer_service_envelope.BoundBox.YLength, 3),
            round(buzzer_service_envelope.BoundBox.ZLength, 3),
        ],
        "buzzer_service_cavity_volume_mm3": round(
            buzzer_service_cavity.Volume,
            6,
        ),
        "buzzer_service_exterior_breach_mm3": round(
            buzzer_service_cavity.common(
                buzzer_service_exterior_guard
            ).Volume,
            6,
        ),
        "buzzer_service_locator_obstruction_mm3": round(
            sum(
                buzzer_service_envelope.common(item).Volume
                for item in rear_sockets
            ),
            6,
        ),
        "buzzer_service_latch_obstruction_mm3": round(
            sum(
                buzzer_service_envelope.common(item).Volume
                for item in rear_arm_activity_envelopes
            ),
            6,
        ),
```

Replace the obsolete `BuzzerClearance` requirement and guard calculation with
the new service-cavity objects and field.

- [ ] **Step 7: Rebuild and inspect the audit once before hard-coding geometric thresholds**

Run from `codex_usb_pager`:

```powershell
"code=open(r'enclosure/cad/build_blossom_enclosure.py').read(); exec(compile(code, r'enclosure/cad/build_blossom_enclosure.py', 'exec'), {'__name__':'__main__','__file__':r'enclosure/cad/build_blossom_enclosure.py'})" | & 'C:\Program Files\FreeCAD 1.1\bin\FreeCADCmd.exe' -c

"import sys; sys.argv=[r'enclosure/cad/audit_blossom_enclosure.py', r'enclosure/outputs/blossom-enclosure.FCStd']; code=open(r'enclosure/cad/audit_blossom_enclosure.py').read(); exec(compile(code, r'enclosure/cad/audit_blossom_enclosure.py', 'exec'), {'__name__':'__main__','__file__':r'enclosure/cad/audit_blossom_enclosure.py'})" | & 'C:\Program Files\FreeCAD 1.1\bin\FreeCADCmd.exe' -c
```

Expected: build exit 0; service window `[16.0, 23.5, 14.0]`; service envelope
X and Y spans exceed 12.0 mm; service exterior breach, locator obstruction,
latch obstruction, USB obstruction, buzzer obstruction, screen obstruction,
and assembly interference are all `0.0`.

- [ ] **Step 8: Lock the actual geometry into the FreeCAD contract**

Add:

```python
    assert report["buzzer_service_window_dimensions_mm"] == [
        16.0,
        23.5,
        14.0,
    ]
    assert report["buzzer_service_envelope_dimensions_mm"][0] > 12.0
    assert report["buzzer_service_envelope_dimensions_mm"][1] > 12.0
    assert report["buzzer_service_envelope_dimensions_mm"][2] > 11.5
    assert report["buzzer_service_cavity_volume_mm3"] > 0.0
    for field in (
        "buzzer_service_exterior_breach_mm3",
        "buzzer_service_locator_obstruction_mm3",
        "buzzer_service_latch_obstruction_mm3",
    ):
        assert_close(report[field], 0.0)
```

Run:

```powershell
"import sys; sys.argv=[r'enclosure/tests/freecad_latch_geometry_contract.py', r'enclosure/outputs/blossom-enclosure.FCStd']; code=open(r'enclosure/tests/freecad_latch_geometry_contract.py').read(); exec(compile(code, r'enclosure/tests/freecad_latch_geometry_contract.py', 'exec'), {'__name__':'__main__','__file__':r'enclosure/tests/freecad_latch_geometry_contract.py'})" | & 'C:\Program Files\FreeCAD 1.1\bin\FreeCADCmd.exe' -c
```

Expected: `FREECAD LATCH CONTRACT PASS`.

- [ ] **Step 9: Run all tests and commit the geometry**

```powershell
python -m pytest enclosure/tests -q
git diff --check
git add enclosure/cad/build_blossom_enclosure.py enclosure/cad/audit_blossom_enclosure.py enclosure/tests/test_buzzer_service_cavity_contract.py enclosure/tests/test_audit_contract.py enclosure/tests/freecad_latch_geometry_contract.py
git commit -m "feat: enlarge buzzer service cavity"
```

Expected: all tests pass and the commit succeeds.

---

### Task 3: Render, verify, and package the enlarged cavity

**Files:**
- Modify: `codex_usb_pager/enclosure/tests/test_render_contract.py`
- Modify: `codex_usb_pager/enclosure/cad/render_blossom_review.py`
- Modify: `codex_usb_pager/enclosure/README.md`
- Regenerate: `codex_usb_pager/enclosure/outputs/blossom-enclosure.FCStd`
- Regenerate: `codex_usb_pager/enclosure/outputs/blossom-enclosure.step`
- Regenerate: `codex_usb_pager/enclosure/outputs/blossom-front.stl`
- Regenerate: `codex_usb_pager/enclosure/outputs/blossom-rear.stl`
- Regenerate: `codex_usb_pager/enclosure/outputs/review-*.png`
- Refresh: `codex_usb_pager/docs/enclosure_handoff_2026-07-29/`
- Refresh: `codex_usb_pager/docs/enclosure_handoff_2026-07-29.zip`

**Interfaces:**
- Consumes: `BuzzerEnvelope`, `BuzzerServiceEnvelope`, and `BuzzerServiceCavity`.
- Produces: seven verified 1600 x 1200 review images and a self-contained handoff archive.

- [ ] **Step 1: Write the failing renderer contract**

Update the renderer object expectations:

```python
def test_review_renderer_uses_service_cavity_objects():
    source = RENDER.read_text(encoding="utf-8")
    for name in (
        "BuzzerEnvelope",
        "BuzzerServiceEnvelope",
        "BuzzerServiceCavity",
    ):
        assert name in source
    assert '"BuzzerClearance"' not in source

def test_buzzer_review_compares_large_service_space_to_hardware():
    names, direction = _literal_views()["review-buzzer-clearance.png"]
    assert direction == "bottom"
    assert set(names) == {
        "ElectronicCavity",
        "BuzzerEnvelope",
        "BuzzerServiceEnvelope",
    }
```

- [ ] **Step 2: Run the renderer test and verify RED**

Run:

```powershell
python -m pytest enclosure/tests/test_render_contract.py -q
```

Expected: FAIL because the renderer still references `BuzzerClearance` and the
old clipped retainer-gap view.

- [ ] **Step 3: Update the review views and styles**

Use:

```python
    "review-buzzer-clearance.png": (
        (
            "ElectronicCavity",
            "BuzzerEnvelope",
            "BuzzerServiceEnvelope",
        ),
        "bottom",
    ),
```

Replace `BuzzerClearance` in the rear-inside and assembly-cutaway views with
`BuzzerServiceEnvelope` and `BuzzerServiceCavity`. Add:

```python
    "ElectronicCavity": ((0.58, 0.64, 0.70), 82),
    "BuzzerServiceEnvelope": ((0.15, 0.82, 0.48), 68),
    "BuzzerServiceCavity": ((0.96, 0.18, 0.16), 18),
```

Keep `BuzzerEnvelope` blue and translucent so its 12.0 mm hardware boundary is
visibly smaller than the new green service volume.

- [ ] **Step 4: Run the renderer contract and full pure suite**

Run:

```powershell
python -m pytest enclosure/tests/test_render_contract.py -q
python -m pytest enclosure/tests -q
```

Expected: all tests pass.

- [ ] **Step 5: Update the enclosure README**

State that the buzzer is checked with a 12.0 x 11.5 mm hardware envelope but
the physical left-petal service cavity uses the larger protected,
non-cylindrical Blossom-contour volume and has no exterior opening.

- [ ] **Step 6: Cold-build and render**

Run:

```powershell
"code=open(r'enclosure/cad/build_blossom_enclosure.py').read(); exec(compile(code, r'enclosure/cad/build_blossom_enclosure.py', 'exec'), {'__name__':'__main__','__file__':r'enclosure/cad/build_blossom_enclosure.py'})" | & 'C:\Program Files\FreeCAD 1.1\bin\FreeCADCmd.exe' -c

$macro = (Resolve-Path 'enclosure/cad/render_blossom_review.FCMacro').Path
$process = Start-Process -FilePath 'C:\Program Files\FreeCAD 1.1\bin\FreeCAD.exe' -ArgumentList $macro -WindowStyle Hidden -Wait -PassThru
$process.ExitCode
```

Expected: `BUILD PASS`, renderer exit `0`, and seven nonblank PNG files.

- [ ] **Step 7: Inspect the acceptance views**

Open:

- `enclosure/outputs/review-rear-inside.png`
- `enclosure/outputs/review-buzzer-clearance.png`
- `enclosure/outputs/review-assembly-cutaway.png`
- `enclosure/outputs/review-front-exterior.png`
- `enclosure/outputs/review-rear-exterior.png`

Confirm the large cavity visibly follows the safe left-petal volume, the blue
buzzer envelope is substantially smaller, the locator/latch regions remain
intact, and both exterior views are unchanged.

- [ ] **Step 8: Perform final verification**

Run:

```powershell
python -m pytest enclosure/tests -q
git diff --check
"import sys; sys.argv=[r'enclosure/tests/freecad_latch_geometry_contract.py', r'enclosure/outputs/blossom-enclosure.FCStd']; code=open(r'enclosure/tests/freecad_latch_geometry_contract.py').read(); exec(compile(code, r'enclosure/tests/freecad_latch_geometry_contract.py', 'exec'), {'__name__':'__main__','__file__':r'enclosure/tests/freecad_latch_geometry_contract.py'})" | & 'C:\Program Files\FreeCAD 1.1\bin\FreeCADCmd.exe' -c
```

Expected: all pytest tests pass, `git diff --check` is silent, and the FreeCAD
contract prints `PASS` with every interference and exterior-breach field at
`0.0`.

- [ ] **Step 9: Commit renderer and documentation**

```powershell
git add enclosure/cad/render_blossom_review.py enclosure/tests/test_render_contract.py enclosure/README.md
git commit -m "docs: review enlarged buzzer service cavity"
```

- [ ] **Step 10: Refresh and validate the stable handoff**

Copy the regenerated CAD exports, seven review images, updated CAD sources,
tests, specification, and plan into
`codex_usb_pager/docs/enclosure_handoff_2026-07-29/`. Recreate
`codex_usb_pager/docs/enclosure_handoff_2026-07-29.zip`, then confirm the zip
contains the FCStd, STEP, both STL files, and both buzzer review images with
nonzero sizes.

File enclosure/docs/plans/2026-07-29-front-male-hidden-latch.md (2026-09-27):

# Front-Mounted Hidden Latch Implementation Plan

> **For agentic workers:** REQUIRED SUB-SKILL: Use superpowers:subagent-driven-development (recommended) or superpowers:executing-plans to implement this plan task-by-task. Steps use checkbox (`- [ ]`) syntax for tracking.

**Goal:** Replace the visible front-shell latch holes with short rigid male
features on the front side petals and blind sockets plus long flexible female
arms on the rear shell, while reserving the user's relocated buzzer envelope.

**Architecture:** The front closure is additive only: two axial locating tongues and two short wedge hooks fuse to the existing front shell without cutting `FrontClosureBlank`. The rear cover owns all compliant parts and blind recesses. Geometry audit compares the final shells with their pre-closure blanks and renders opaque exterior views so a valid solid cannot hide an exterior breakthrough.

**Tech Stack:** Python 3, pytest, FreeCAD 1.1 Python API (`Part`, `Mesh`, `Import`), FreeCAD GUI macro rendering.

## Global Constraints

- Front closure geometry may add material but must remove exactly `0.0 mm³` from `FrontClosureBlank`.
- Rear locating sockets and latch tunnels must not reach any rear exterior surface.
- Front locating tongues: 5.0 mm wide, 1.0 mm thick, 2.5 mm axial projection, centres X = ±10.0 mm and Y = 19.75 mm.
- Front hooks: 4.0 mm wide, 1.2 mm stem thickness, 2.2 mm axial projection,
  initial centres X = ±15.0 mm and Y = -9.0 mm. A same-petal adjustment up to
  1.0 mm is allowed only when the audit proves it necessary.
- Side hooks and rear arms deflect outward along X; their profiles are built in
  XZ and extruded 4.0 mm along Y.
- Hook engagement is 0.35 mm, entry angle 35°, release angle 20°.
- Rear arms remain 13.0 × 4.0 × 1.0 mm with R1.0 roots and 0.30 mm activity clearance.
- Rear exterior guard thickness is 1.0 mm; the intentional fingernail notch is excluded from the breach calculation.
- The fully internal buzzer uses a reserved cylinder of diameter 12.0 mm and
  height 11.5 mm at initial centre X = -9.0 mm and Y = 4.36 mm. The cylinder
  starts at the screen-PCB rear plane and may require a local rear-shell
  clearance cut, but it must not break the 1.0 mm exterior guard.
- Screen mount, rounded USB rear opening, no buzzer sound hole and 1.5 mm
  Blossom relief remain unchanged.
- Final front/rear assembly interference, screen obstruction, USB obstruction
  and buzzer obstruction must each remain `0.0 mm³`.

---

### Task 1: Encode Reversed-Closure Dimensions

**Files:**
- Modify: `codex_usb_pager/enclosure/cad/enclosure_params.py`
- Modify: `codex_usb_pager/enclosure/tests/test_enclosure_params.py`

**Interfaces:**
- Consumes: `EnclosureParameters` and `DEFAULTS`.
- Produces: named front-male and rear-guard parameters used by the builder and audit.

- [ ] **Step 1: Write the failing parameter test**

Replace `test_hidden_closure_dimensions_are_resin_safe` with:

```python
def test_hidden_closure_places_rigid_males_on_front():
    assert DEFAULTS.closure_style == "front_male_rear_flex"
    assert DEFAULTS.top_tongue_mm == (5.0, 1.0, 2.5)
    assert DEFAULTS.top_tongue_centres_mm == (
        (-10.0, 19.75),
        (10.0, 19.75),
    )
    assert DEFAULTS.front_latch_hook_mm == (4.0, 1.2, 2.2)
    assert DEFAULTS.front_latch_centres_mm == (
        (-15.0, -9.0),
        (15.0, -9.0),
    )
    assert DEFAULTS.buzzer_clearance_mm == (12.0, 11.5)
    assert DEFAULTS.buzzer_centre_mm == (-9.0, 4.36)
    assert DEFAULTS.latch_arm_mm == (13.0, 4.0, 1.0)
    assert DEFAULTS.latch_root_radius_mm == 1.0
    assert DEFAULTS.latch_engagement_mm == 0.35
    assert DEFAULTS.latch_entry_angle_deg == 35.0
    assert DEFAULTS.latch_release_angle_deg == 20.0
    assert DEFAULTS.rear_exterior_guard_mm == 1.0
    assert DEFAULTS.fingernail_notch_mm == (10.0, 1.2, 0.8)
```

- [ ] **Step 2: Run the test and verify RED**

Run:

```powershell
python -m pytest enclosure/tests/test_enclosure_params.py::test_hidden_closure_places_rigid_males_on_front -q
```

Expected: FAIL because `top_tongue_centres_mm`, `front_latch_hook_mm`,
`front_latch_centres_mm`, and `rear_exterior_guard_mm` do not exist and the
old engagement is 0.40 mm.

- [ ] **Step 3: Implement the parameter contract**

Change the closure fields in `EnclosureParameters` to:

```python
    top_tongue_mm: tuple[float, float, float] = (5.0, 1.0, 2.5)
    top_tongue_centres_mm: tuple[tuple[float, float], ...] = (
        (-10.0, 19.75),
        (10.0, 19.75),
    )
    top_tongue_clearance_mm: float = 0.25
    front_latch_hook_mm: tuple[float, float, float] = (4.0, 1.2, 2.2)
    front_latch_centres_mm: tuple[tuple[float, float], ...] = (
        (-15.0, -9.0),
        (15.0, -9.0),
    )
    buzzer_clearance_mm: tuple[float, float] = (12.0, 11.5)
    buzzer_centre_mm: tuple[float, float] = (-9.0, 4.36)
    latch_arm_mm: tuple[float, float, float] = (13.0, 4.0, 1.0)
    latch_root_radius_mm: float = 1.0
    latch_engagement_mm: float = 0.35
    latch_entry_angle_deg: float = 35.0
    latch_release_angle_deg: float = 20.0
    latch_slot_clearance_mm: float = 0.30
    rear_exterior_guard_mm: float = 1.0
    closure_style: str = "front_male_rear_flex"
```

- [ ] **Step 4: Run the parameter suite and verify GREEN**

Run:

```powershell
python -m pytest enclosure/tests/test_enclosure_params.py -q
```

Expected: all parameter tests PASS.

- [ ] **Step 5: Commit**

```powershell
git add -- codex_usb_pager/enclosure/cad/enclosure_params.py codex_usb_pager/enclosure/tests/test_enclosure_params.py
git commit -m "feat: define front-mounted latch dimensions"
```

---

### Task 2: Reverse the Real Closure Geometry

**Files:**
- Modify: `codex_usb_pager/enclosure/cad/enclosure_params.py`
- Modify: `codex_usb_pager/enclosure/cad/build_blossom_enclosure.py`
- Modify: `codex_usb_pager/enclosure/tests/test_enclosure_params.py`
- Modify: `codex_usb_pager/enclosure/tests/test_closure_contract.py`
- Modify: `codex_usb_pager/enclosure/tests/test_audit_contract.py`
- Modify: `codex_usb_pager/enclosure/cad/audit_blossom_enclosure.py`

**Interfaces:**
- Consumes: the parameters from Task 1, screen-PCB placement and the existing
  `make_x_prism` helper.
- Produces: `FrontTopTongue*`, `RearTopSocket*`, `FrontLatchHook*`,
  `RearLatchArm*`, `RearLatchPocket*`, `RearLatchTunnel*`,
  `RearClosureExteriorGuard`, `BuzzerEnvelope`, local buzzer clearance and new
  serialisable audit fields.

- [ ] **Step 1: Write failing source-contract tests**

Replace the old mating-feature and subtraction tests in
`test_closure_contract.py` with:

```python
def test_closure_uses_front_males_and_rear_flexible_receivers():
    for name in (
        '"FrontTopTongueLeft"',
        '"FrontTopTongueRight"',
        '"RearTopSocketLeft"',
        '"RearTopSocketRight"',
        '"FrontLatchHookLeft"',
        '"FrontLatchHookRight"',
        '"RearLatchArmLeft"',
        '"RearLatchArmRight"',
        '"RearLatchPocketLeft"',
        '"RearLatchPocketRight"',
        '"RearLatchTunnelLeft"',
        '"RearLatchTunnelRight"',
        '"RearClosureExteriorGuard"',
        '"BuzzerEnvelope"',
        '"FingernailNotch"',
    ):
        assert name in BUILD

def test_front_closure_is_additive_and_rear_receivers_are_subtractive():
    assert "front_body = front_blank.multiFuse([*tongues, *hooks])" in BUILD
    assert "front_body.cut(top_pockets)" not in BUILD
    assert "front_body.cut(latch_pockets)" not in BUILD
    assert "rear_body.cut(top_sockets).cut(latch_tunnels)" in BUILD
    assert ".cut(fingernail_notch)" in BUILD
```

Update `test_audit_contract.py` so `REQUIRED_CLOSURE` contains the new names
and so `audit_document` must expose:

```python
for field in (
    "front_closure_skin_removed_mm3",
    "front_closure_features_fused",
    "rear_socket_cut_mm3",
    "rear_latch_pocket_cut_mm3",
    "rear_latch_arms_fused",
    "rear_exterior_breach_mm3",
    "buzzer_obstruction_mm3",
):
    assert field in getsource(audit_document)
```

- [ ] **Step 2: Run the contract tests and verify RED**

Run:

```powershell
python -m pytest enclosure/tests/test_closure_contract.py enclosure/tests/test_audit_contract.py -q
```

Expected: FAIL because the side-petal parameter values, X-deflecting latch
geometry and buzzer envelope are not yet implemented.

- [ ] **Step 3: Build front axial tongues and rear blind sockets**

In `build_hidden_closure`, create each tongue with a 0.05 mm fusion overlap:

```python
tongue_width, tongue_thickness, tongue_projection = DEFAULTS.top_tongue_mm
tongues = []
top_socket_parts = []
for centre_x, centre_y in DEFAULTS.top_tongue_centres_mm:
    tongue = Part.makeBox(
        tongue_width,
        tongue_thickness,
        tongue_projection + 0.05,
        App.Vector(
            centre_x - tongue_width / 2.0,
            centre_y - tongue_thickness / 2.0,
            seam_z - 0.05,
        ),
    )
    socket = Part.makeBox(
        tongue_width + 2.0 * DEFAULTS.top_tongue_clearance_mm,
        tongue_thickness + 2.0 * DEFAULTS.top_tongue_clearance_mm,
        tongue_projection + 0.30,
        App.Vector(
            centre_x - tongue_width / 2.0
            - DEFAULTS.top_tongue_clearance_mm,
            centre_y - tongue_thickness / 2.0
            - DEFAULTS.top_tongue_clearance_mm,
            seam_z - 0.05,
        ),
    )
    tongues.append(tongue)
    top_socket_parts.append(socket)
```

Fuse a 0.5 mm-high tapered cap or apply an equivalent tip chamfer while
retaining the same maximum 2.5 mm projection.

- [ ] **Step 4: Build side-petal front wedge hooks and rear female arms**

Add a `make_y_prism` helper. For each centre in
`front_latch_centres_mm`, mirror an XZ hook profile and extrude it 4.0 mm along
Y. The short front hook points toward the nearest side wall. The rear arm sits
immediately outside that hook and runs 13.0 mm rearward from the seam, so the
arm deflects outward along X during insertion and removal.

```python
hook = make_y_prism(
    hook_width,
    mirrored_xz_profile,
    centre_y - hook_width / 2.0,
)
```

Create the activity tunnel around `arm_box`, fuse an anchor and R1.0 root at
the deep end, and use `arm.cut(latch_pocket)` as the review/audit arm shape.
The tunnel must leave at least 0.30 mm around the moving surfaces. Check a
small discrete grid around each initial centre, within the allowed 1.0 mm
same-petal adjustment, and accept only a mirrored pair that has zero USB,
buzzer and exterior-guard intersection.

- [ ] **Step 5: Reserve the relocated buzzer**

Create `BuzzerEnvelope` as a 12.0 mm diameter, 11.5 mm high cylinder centred at
X = -9.0 mm and Y = 4.36 mm. Its front face is the screen-PCB rear plane:

```python
buzzer_front_z = (
    DEFAULTS.front_seam_z_mm + DEFAULTS.screen_face_to_pcb_mm
)
buzzer_envelope = Part.makeCylinder(
    DEFAULTS.buzzer_clearance_mm[0] / 2.0,
    DEFAULTS.buzzer_clearance_mm[1],
    App.Vector(
        DEFAULTS.buzzer_centre_mm[0],
        DEFAULTS.buzzer_centre_mm[1],
        buzzer_front_z,
    ),
)
```

Subtract only the portion not already cleared by the main electronics cavity
from the rear blank. Keep the cylinder fully inside the 1.0 mm exterior guard,
register it as `BuzzerEnvelope`, and do not add a buzzer sound opening.

- [ ] **Step 6: Apply closure booleans without cutting the front**

Use:

```python
top_sockets = Part.makeCompound(top_socket_parts)
latch_tunnels = Part.makeCompound(tunnels)
front_body = front_blank.multiFuse([*tongues, *hooks])
rear_body = (
    rear_blank
    .cut(top_sockets)
    .cut(latch_tunnels)
    .cut(fingernail_notch)
)
rear_body = rear_body.multiFuse(arms)
```

Return the new feature lists with explicit keys:

```python
return {
    "front": front_body.removeSplitter(),
    "rear": rear_body.removeSplitter(),
    "front_tongues": tongues,
    "rear_top_sockets": top_socket_parts,
    "front_hooks": hooks,
    "rear_arms": arms,
    "rear_latch_pockets": latch_pocket_parts,
    "rear_latch_tunnels": tunnels,
    "fingernail_notch": fingernail_notch,
    "front_blank": front_blank,
    "rear_blank": rear_blank,
}
```

Register the new object names and remove the old ambiguous `TopPocket*`,
`LatchHook*`, and `LatchArm*` registrations.

- [ ] **Step 7: Add exterior-guard, closure and buzzer audit facts**

Create `RearClosureExteriorGuard` from an inward-scaled Blossom core in
`build()`, so the guard follows the curved petal perimeter instead of using
the rectangular bounding box:

```python
guard_ratio = (
    DEFAULTS.blossom_target_width_mm
    - 2.0 * DEFAULTS.rear_exterior_guard_mm
) / DEFAULTS.blossom_target_width_mm
rear_guard_core = Part.makeLoft(
    [
        wire_profile(
            outer_wire,
            svg_scale * guard_ratio,
            DEFAULTS.front_seam_z_mm - 0.1,
        ),
        wire_profile(
            outer_wire,
            svg_scale * guard_ratio,
            DEFAULTS.front_seam_z_mm
            + DEFAULTS.internal_envelope_mm[2],
        ),
        wire_profile(
            outer_wire,
            svg_scale * 0.965 * guard_ratio,
            DEFAULTS.maximum_thickness_mm
            - DEFAULTS.rear_exterior_guard_mm,
        ),
    ],
    True,
    True,
)
rear_exterior_guard = rear_body.cut(rear_guard_core)
```

Pass `rear_exterior_guard` into `build_hidden_closure`, retain it unchanged
for the audit, and register it as `RearClosureExteriorGuard`.

In `audit_document`, calculate:

```python
front_removed = front_blank.cut(front)
front_features = [
    document.getObject(name).Shape
    for name in (
        "FrontTopTongueLeft",
        "FrontTopTongueRight",
        "FrontLatchHookLeft",
        "FrontLatchHookRight",
    )
]
rear_removed_without_notch = rear_blank.cut(
    rear.fuse(fingernail_notch)
)
report.update(
    {
        "front_closure_skin_removed_mm3": round(
            front_removed.Volume, 6
        ),
        "front_closure_features_fused": all(
            abs(front.common(feature).Volume - feature.Volume) <= 1e-5
            for feature in front_features
        ),
        "rear_socket_cut_mm3": round(
            sum(
                rear_blank.common(socket).Volume
                - rear.common(socket).Volume
                for socket in rear_sockets
            ),
            6,
        ),
        "rear_latch_pocket_cut_mm3": round(
            sum(pocket.Volume for pocket in rear_latch_pockets),
            6,
        ),
        "rear_latch_arms_fused": all(
            abs(rear.common(arm).Volume - arm.Volume) <= 1e-5
            for arm in rear_arms
        ),
        "rear_exterior_breach_mm3": round(
            rear_removed_without_notch.common(rear_exterior_guard).Volume,
            6,
        ),
        "buzzer_obstruction_mm3": round(
            rear.common(buzzer_envelope).Volume,
            6,
        ),
    }
)
```

- [ ] **Step 8: Run source tests and verify GREEN**

Run:

```powershell
python -m pytest enclosure/tests/test_closure_contract.py enclosure/tests/test_audit_contract.py enclosure/tests/test_enclosure_params.py -q
```

Expected: all selected tests PASS.

- [ ] **Step 9: Build and audit the real FreeCAD geometry**

Run:

```powershell
"code=open(r'enclosure/cad/build_blossom_enclosure.py').read(); exec(compile(code, r'enclosure/cad/build_blossom_enclosure.py', 'exec'), {'__name__':'__main__','__file__':r'enclosure/cad/build_blossom_enclosure.py'})" | & 'C:\Program Files\FreeCAD 1.1\bin\FreeCADCmd.exe' -c
```

Then:

```powershell
"import sys; sys.argv=[r'enclosure/cad/audit_blossom_enclosure.py', r'enclosure/outputs/blossom-enclosure.FCStd']; code=open(r'enclosure/cad/audit_blossom_enclosure.py').read(); exec(compile(code, r'enclosure/cad/audit_blossom_enclosure.py', 'exec'), {'__name__':'__main__','__file__':r'enclosure/cad/audit_blossom_enclosure.py'})" | & 'C:\Program Files\FreeCAD 1.1\bin\FreeCADCmd.exe' -c
```

Expected: `BUILD PASS`; the front skin removal, rear exterior breach,
assembly interference, screen obstruction, USB obstruction and buzzer
obstruction are each `0.0 mm³`; both shells are valid single solids.

- [ ] **Step 10: Commit**

```powershell
git add -- codex_usb_pager/enclosure/cad/enclosure_params.py codex_usb_pager/enclosure/cad/build_blossom_enclosure.py codex_usb_pager/enclosure/cad/audit_blossom_enclosure.py codex_usb_pager/enclosure/tests/test_enclosure_params.py codex_usb_pager/enclosure/tests/test_closure_contract.py codex_usb_pager/enclosure/tests/test_audit_contract.py
git commit -m "fix: move hidden latches to side petals"
```

---

### Task 3: Add Opaque Exterior Review Views

**Files:**
- Modify: `codex_usb_pager/enclosure/cad/render_blossom_review.py`
- Modify: `codex_usb_pager/enclosure/tests/test_render_contract.py`
- Modify: `codex_usb_pager/enclosure/README.md`
- Modify: `codex_usb_pager/enclosure/outputs/README.md`

**Interfaces:**
- Consumes: new FreeCAD object names from Task 2.
- Produces: opaque exterior PNGs plus updated internal and cutaway views.

- [ ] **Step 1: Write the failing render contract**

Require both new outputs and all renamed closure objects:

```python
def test_review_renderer_includes_opaque_exterior_views():
    source = RENDER.read_text(encoding="utf-8")
    for name in (
        "review-front-exterior.png",
        "review-rear-exterior.png",
        "FrontTopTongueLeft",
        "RearTopSocketLeft",
        "FrontLatchHookLeft",
        "RearLatchArmLeft",
        "RearLatchPocketLeft",
        "BuzzerEnvelope",
    ):
        assert name in source
    assert '"FrontShell": ((0.72, 0.76, 0.80), 0)' in source
    assert '"RearCover": ((0.42, 0.46, 0.50), 0)' in source
```

- [ ] **Step 2: Run the render contract and verify RED**

Run:

```powershell
python -m pytest enclosure/tests/test_render_contract.py -q
```

Expected: FAIL because exterior filenames and renamed objects are absent.

- [ ] **Step 3: Add exterior and renamed internal views**

Add:

```python
"review-front-exterior.png": (("FrontShell",), "bottom"),
"review-rear-exterior.png": (("RearCover",), "top"),
```

Replace old closure names in internal and cutaway views with:

```python
"FrontTopTongueLeft",
"RearTopSocketLeft",
"FrontLatchHookLeft",
"RearLatchArmLeft",
"RearLatchPocketLeft",
```

Set shell styles to zero transparency. Use separate translucent helper styles
for `FrontClosureBlank` and `RearClosureBlank`.

- [ ] **Step 4: Update output documentation**

Add `review-buzzer-clearance.png`. Document all seven review images and state
that the two exterior views must show continuous opaque surfaces without
rectangular closure openings.

- [ ] **Step 5: Run the render contract and verify GREEN**

Run:

```powershell
python -m pytest enclosure/tests/test_render_contract.py -q
```

Expected: all render contract tests PASS.

- [ ] **Step 6: Commit**

```powershell
git add -- codex_usb_pager/enclosure/cad/render_blossom_review.py codex_usb_pager/enclosure/tests/test_render_contract.py codex_usb_pager/enclosure/README.md codex_usb_pager/enclosure/outputs/README.md
git commit -m "test: add opaque shell visibility review"
```

---
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

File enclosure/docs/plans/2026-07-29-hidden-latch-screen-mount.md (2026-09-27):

# Hidden Latch And Screen Mount Implementation Plan

> **For agentic workers:** REQUIRED SUB-SKILL: Use superpowers:subagent-driven-development (recommended) or superpowers:executing-plans to implement this plan task-by-task. Steps use checkbox (`- [ ]`) syntax for tracking.

**Goal:** Replace the four rectangular closure placeholders with a functional hidden, easy-open resin latch system and add a screen-face pocket, four locating posts, and two light retention lips to the front shell.

**Architecture:** Keep `enclosure/cad/build_blossom_enclosure.py` as the FreeCAD source of truth, but express every approved dimension in `enclosure_params.py`. Build screen retention and closure as named intermediate shapes, fuse/cut them into the final shells, and extend the FreeCAD audit to verify actual Boolean relationships rather than object names alone. Generate internal review views before treating the STL files as print-ready.

**Tech Stack:** Python 3.11, pytest, FreeCAD 1.1 Part/Import/Mesh APIs, OpenCascade Boolean solids, FreeCADGui image export.
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

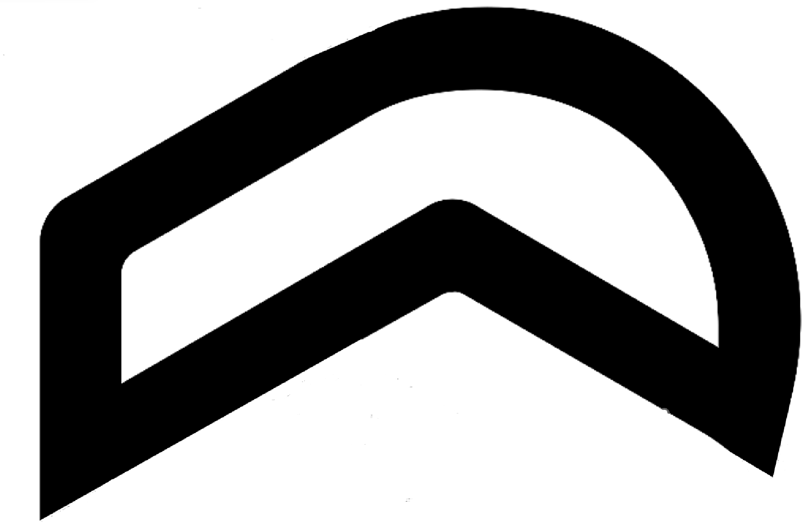
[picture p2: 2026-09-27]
assets/reference-petal-exact.png

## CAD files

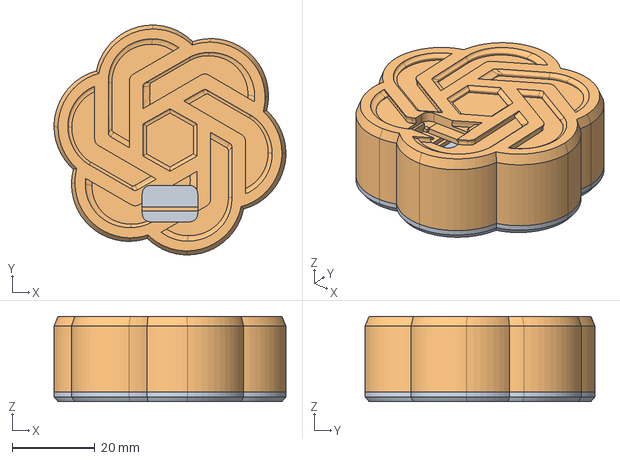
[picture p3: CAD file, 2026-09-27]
enclosure/outputs/blossom-enclosure.step
56.0 x 55.5 x 20.6 mm
FrontShell
RearCover

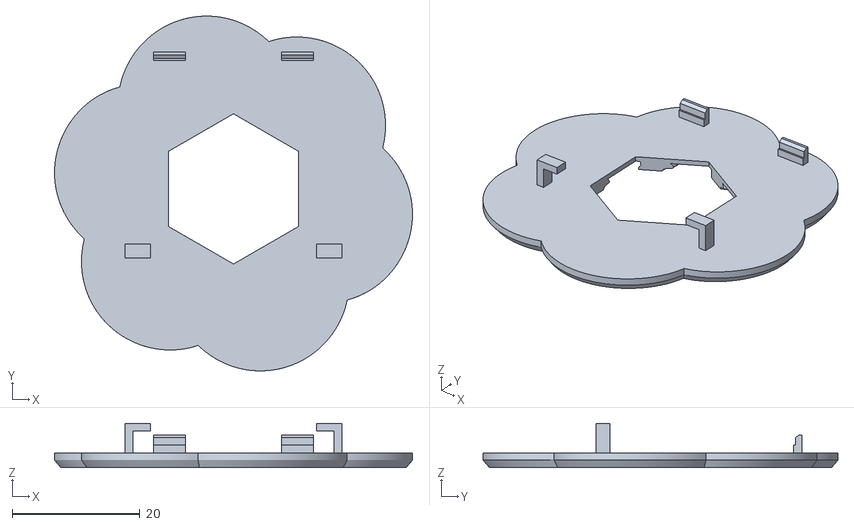
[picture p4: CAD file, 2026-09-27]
enclosure/outputs/blossom-front.stl
56.0 x 55.5 x 6.90

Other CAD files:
enclosure/outputs/blossom-enclosure.FCStd

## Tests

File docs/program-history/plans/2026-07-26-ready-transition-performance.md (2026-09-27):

# Ready And Transition Performance Implementation Plan

> **For agentic workers:** REQUIRED SUB-SKILL: Use superpowers:subagent-driven-development (recommended) or superpowers:executing-plans to implement this plan task-by-task. Steps use checkbox (`- [ ]`) syntax for tracking.

**Goal:** Remove the avoidable six-layer full-scene work and broad delta transfers that make READY and state transitions visibly slower than RUNNING.

**Architecture:** Add testable 12 x 12 dirty-tile and layer-intersection helpers to the scene module. Render only dirty tiles with compact active-layer lists, then coalesce dirty tile runs for ST7789 transfer while preserving the existing double framebuffer and RUNNING fast path.

**Tech Stack:** RP2040 Pico SDK, C11, PIO/DMA ST7789 transport, CMake/CTest, pytest source-contract tests.

## Global Constraints

- Keep the 16 ms target and elapsed-time animation.
- Preserve all approved visual geometry and timing.
- Keep display SPI at 24 MHz and preserve RGB565 byte order.
- Retain the two existing frame buffers and fit in 264 KB SRAM.
- Use failing tests before production changes.

---

### Task 1: Dirty-Tile Geometry

**Files:**
- Modify: `ports/rp2040-zero/firmware/include/display_scene.h`
- Modify: `ports/rp2040-zero/firmware/src/display_scene.c`
- Test: `ports/rp2040-zero/tests/test_pager_core.c`

**Interfaces:**
- Produces: `pager_scene_tile_map_t`
- Produces: `pager_scene_mark_motion_tiles(previous, current, map)`
- Produces: `pager_scene_tile_layer_mask(model, clips, tile_x, tile_y)`

- [ ] **Step 1: Write failing geometry tests**

Add tests that create a READY model, move one petal, and assert that only tiles
intersecting the old and new clips are dirty. Add a second test asserting that
a corner tile has no petal layers and a tile through one petal has a layer mask
with fewer than six bits.

- [ ] **Step 2: Verify RED**

Run:

```powershell
powershell -ExecutionPolicy Bypass -File tools\run_host_tests.ps1
```

Expected: compilation fails because the tile types and functions do not exist.

- [ ] **Step 3: Implement the geometry helpers**

Use 12 pixel tiles over the 228 pixel region, yielding 19 x 19 tiles. Mark the
inclusive tile range of each old/new clip. Build layer masks by testing clip
intersection against the selected tile rectangle.

- [ ] **Step 4: Verify GREEN**

Run the host tests again. Expected: all tests pass.

### Task 2: Tile Renderer And Compact Layer Sampling

**Files:**
- Modify: `ports/rp2040-zero/firmware/include/display_scene.h`
- Modify: `ports/rp2040-zero/firmware/src/display_scene.c`
- Modify: `ports/rp2040-zero/firmware/src/display_ui.c`
- Test: `ports/rp2040-zero/tests/test_pager_core.c`
- Test: `tools/test_rp2040_display_ui.py`

**Interfaces:**
- Consumes: dirty tile map and per-tile layer masks from Task 1
- Produces: `pager_scene_render_motion_span(...)`

- [ ] **Step 1: Write failing renderer-contract tests**

Assert that the UI renders complete frames only on initialization, and
subsequent petal frames call the span renderer for dirty tile rows. Assert that
RUNNING continues to use a single full-layer sampling path.

- [ ] **Step 2: Verify RED**

Run the focused pytest and C host tests. Expected: failures because the span
renderer and tile-driven UI path are absent.

- [ ] **Step 3: Implement minimal tile rendering**

Copy the previous framebuffer into the working buffer. Rebuild every dirty
tile from background and hexagon, sampling only the layer bits active for that
tile. Keep the existing complete-row renderer for the initial frame and the
RUNNING fast path.

- [ ] **Step 4: Verify GREEN**

Run both focused and complete host suites. Expected: all tests pass and
pixel-level tests remain unchanged.

### Task 3: Coalesced Tile Transfer And Firmware Verification

**Files:**
- Modify: `ports/rp2040-zero/firmware/src/display_ui.c`
- Test: `tools/test_rp2040_display_ui.py`

**Interfaces:**
- Consumes: dirty tile map from Task 1
- Produces: horizontally coalesced ST7789 transfer rectangles

- [ ] **Step 1: Write failing transfer tests**

Add a source-contract test proving separated dirty tile runs are not expanded
into one full-width eight-row band and adjacent tiles are coalesced.

- [ ] **Step 2: Verify RED**

Run:

```powershell
python -m pytest tools\test_rp2040_display_ui.py -q
```

Expected: failure against the existing `DELTA_BAND_ROWS` union transport.

- [ ] **Step 3: Implement tile-run transfer**

For each tile row, merge adjacent dirty tiles into one horizontal run. Set one
ST7789 window per run and send its 12 rows directly from the working
framebuffer. Do not transmit gaps between separated runs.

- [ ] **Step 4: Verify and build**

Run:

```powershell
powershell -ExecutionPolicy Bypass -File tools\run_host_tests.ps1
python -m pytest tools\test_blossom_asset.py tools\test_petal_preview_geometry.py tools\test_rp2040_display_ui.py tools\test_build_rp2040_script.py tools\test_run_host_tests_script.py -q
powershell -ExecutionPolicy Bypass -File tools\build_rp2040.ps1
```

Expected: all host tests pass and the UF2 build reports SRAM below 264 KB.

- [ ] **Step 5: Flash and inspect**

Enter BOOTSEL through the existing 1200-baud reset path, copy the generated
UF2, verify the serial device returns, and inspect READY plus both transition
directions on the physical screen.

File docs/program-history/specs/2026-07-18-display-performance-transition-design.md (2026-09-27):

# RP2040 Display Performance And Transition Design

## Goal

Raise the 172 x 172 animated scene from its current visibly low frame rate to a stable 35-40 FPS where hardware permits, while replacing abrupt state changes with a 650 ms continuous transition. The implementation must preserve prompt-state responsiveness and the verified ST7789 panel profile.

## Rendering And Transport

The existing PIO program consumes one 32-bit FIFO word for every display byte and the driver configures DMA once per row. The replacement PIO program consumes all 32 bits of each FIFO word, so one word carries four consecutive display bytes. Each rendered RGB565 pixel pair is packed in panel byte order and the entire animation region is submitted by one DMA operation.

The scene renderer will remove integer division from the per-pixel dynamic-background path. Frame pacing targets 25 ms. If a frame takes longer, the next frame starts immediately without accumulating timing debt, yielding a natural 30-40 FPS range instead of duplicated or skipped animation time.

## State Transition

Changing state must not call a full-screen fill. The UI keeps the outgoing rendered frame and renders the incoming state into a second frame buffer. For 650 ms it blends outgoing and incoming pixels with a smoothstep curve. The incoming scene advances normally during the blend, so rotation and ambient motion never pause. After the transition, the outgoing buffer becomes reusable.

The transition applies to every state pair, including RUNNING, MULTI, WAIT, DONE, IDLE, ERROR, and OFFLINE. USB state selection and event priority remain unchanged.

## Memory And Safety

Two packed 172 x 172 RGB565 buffers consume 118,336 bytes. This fits within the RP2040's 264 KB SRAM while leaving space for code data, USB, stacks, and PIO/DMA state. A link-time size check and firmware build verify the remaining margin.

SPI remains at the already verified 24 MHz. Raising it is unnecessary until renderer and DMA overhead are removed, and avoiding that change keeps signal integrity stable on the hand-wired display.

## Local Test Environment

The inaccessible `.pytest-*` directories were created with unusable ACLs. Reset their ownership/ACL, remove only those known temporary directories, and configure pytest to use a single ASCII-only writable base directory outside the source tree. This prevents Git traversal warnings and Chinese-path pytest temporary-directory failures.

## Verification

- Host tests cover 25 ms pacing, transition duration/easing endpoints, frame packing order, and existing scene behavior.
- A host benchmark reports scene-render duration before firmware flashing.
- The RP2040 firmware build must succeed and report SRAM usage below the device limit.
- Flash the UF2 and verify RUNNING animation, RUNNING-to-DONE, and DONE-to-IDLE transitions on the physical panel.

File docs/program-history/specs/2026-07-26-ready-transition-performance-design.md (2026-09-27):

# Ready And Transition Performance Design

## Goal

Make READY, READY-to-RUNNING, RUNNING-to-READY, and OFFLINE-to-READY
animations approach the smoothness of the existing RUNNING fast path without
changing the approved petal artwork, layout, color, motion curve, transition
duration, hexagon, or weekly-balance display.

## Root Cause

RUNNING samples one complete Blossom layer. Petal states currently scan the
entire 228 x 228 scene and advance six petal samplers for every pixel. During
crossfades they may also sample the complete Blossom. The eight-row delta
transport then combines distant changed pixels into wide rectangles, sending
unchanged background between separated petals.

## Selected Architecture

Divide the scene into 12 x 12 pixel tiles. For every frame:

1. Build old and new bounds for every visible layer.
2. Mark only tiles touched by either bound as dirty.
3. Rebuild dirty tiles from the deterministic background and fixed hexagon.
4. For each dirty tile, sample only layers whose bounds intersect that tile.
5. Coalesce horizontally adjacent dirty tiles into transfer rectangles and
   send only those rectangles.

RUNNING keeps its current single-layer fast path. Transitions may contain
petals and the complete Blossom, but each tile receives a compact active-layer
list instead of checking all seven layers at every pixel.

## Constraints

- Preserve the current 16 ms frame target and elapsed-time-based animation.
- Do not modify artwork masks, positions, scale, colors, easing, or duration.
- Preserve exact RGB565 byte order and the verified ST7789 initialization.
- Do not raise the 24 MHz display clock.
- Stay within RP2040 SRAM and retain two existing 228 x 228 frame buffers.
- State changes must still trigger an immediate frame.

## Verification

- Host tests prove tiles outside old/new layer bounds remain clean.
- Host tests prove active-layer lists exclude non-intersecting petals.
- Host tests prove separated petals no longer produce a full-width transfer.
- Existing pixel, geometry, motion, and panel-profile tests remain unchanged.
- Firmware builds within SRAM limits.
- Physical verification compares READY and both transition directions with
  the already-smooth RUNNING state.

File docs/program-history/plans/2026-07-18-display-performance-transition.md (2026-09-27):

# Display Performance And Transition Implementation Plan

> **For agentic workers:** REQUIRED SUB-SKILL: Use superpowers:subagent-driven-development (recommended) or superpowers:executing-plans to implement this plan task-by-task. Steps use checkbox (`- [ ]`) syntax for tracking.

**Goal:** Deliver a stable 35-40 FPS RP2040 display path and a smooth 650 ms transition between all pager states.

**Architecture:** Pack two RGB565 pixels into each PIO FIFO word and transfer the complete animation region with one DMA operation. Keep two scene buffers during state changes and blend them with smoothstep easing while the incoming scene remains animated.

**Tech Stack:** RP2040 Pico SDK 2.2, C11, PIO, DMA, CMake/CTest, pytest

## Global Constraints

- Keep the verified ST7789 vendor initialization and 24 MHz SPI clock.
- Keep USB status parsing and state priority unchanged.
- Use a 25 ms frame target and a 650 ms transition.
- Do not exceed RP2040's 264 KB SRAM.

---

### Task 1: Repair Local Test Environment

**Files:**
- Create: `pytest.ini`
- Remove after ACL reset: `.pytest-rp2040`, `.pytest_tmp_abort_fix`, `.pytest_tmp_runtime_red`

**Interfaces:**
- Produces: a writable ASCII-only pytest base directory used by all Python tests.

- [ ] Reset ACLs only on the three known `.pytest-*` temporary directories.
- [ ] Remove those directories and add `pytest.ini` with `addopts = --basetemp=C:/Temp/codex-pager-pytest`.
- [ ] Run `python -m pytest -q tools/test_session_watcher.py tools/test_pager_runtime.py` and verify all tests pass without ACL warnings.

### Task 2: Pack The Display Transport

**Files:**
- Modify: `ports/rp2040-zero/firmware/src/st7789_spi.pio`
- Modify: `ports/rp2040-zero/firmware/include/st7789.h`
- Modify: `ports/rp2040-zero/firmware/src/st7789.c`
- Modify: `ports/rp2040-zero/tests/test_pager_core.c`

**Interfaces:**
- Produces: `uint32_t st7789_pack_pixel_pair(uint16_t first, uint16_t second)` and `st7789_write_packed_pixels(const uint32_t *words, size_t word_count)`.

- [ ] Add a host test asserting red then green packs as `0xF80007E0`.
- [ ] Run the host test and verify it fails because the packing API is absent.
- [ ] Change the PIO loop to shift 32 bits per pull and implement packed frame DMA.
- [ ] Run CTest and verify the packing test and existing panel-profile tests pass.

### Task 3: Add Transition Math And Faster Background Sampling

**Files:**
- Modify: `ports/rp2040-zero/firmware/include/display_scene.h`
- Modify: `ports/rp2040-zero/firmware/src/display_scene.c`
- Modify: `ports/rp2040-zero/tests/test_pager_core.c`

**Interfaces:**
- Produces: `pager_scene_transition_alpha(uint32_t elapsed_ms)` returning 0..255 and division-free background intensity.

- [ ] Add tests for alpha values at 0 ms, 325 ms, and 650 ms and for monotonic smoothstep behavior.
- [ ] Run the host test and verify it fails because the transition API is absent.
- [ ] Implement fixed-point smoothstep and replace per-pixel background division with fixed-point multiplication.
- [ ] Run CTest and verify all scene tests pass.

### Task 4: Integrate Double-Buffer State Transitions

**Files:**
- Modify: `ports/rp2040-zero/firmware/src/display_ui.c`
- Modify: `ports/rp2040-zero/firmware/include/display_scene.h`
- Modify: `ports/rp2040-zero/tests/test_pager_core.c`

**Interfaces:**
- Consumes: packed display transport and `pager_scene_transition_alpha`.
- Produces: 25 ms paced frames and 650 ms transitions without full-screen state fills.

- [ ] Add tests asserting `PAGER_SCENE_FRAME_MS == 25` and `PAGER_SCENE_TRANSITION_MS == 650`.
- [ ] Run the host test and verify it fails against the old constants.
- [ ] Render incoming state into the back buffer, blend from the frozen outgoing buffer during transition, pack in place, and submit one DMA operation.
- [ ] Build firmware and inspect the linker size output for SRAM overflow.
- [ ] Run all host and Python tests.

### Task 5: Flash And Physical Verification

**Files:**
- Update: `ports/rp2040-zero/README.md`

**Interfaces:**
- Consumes: `build-rp2040/codex_pager_rp2040.uf2`.
- Produces: verified physical display behavior.

- [ ] Record the final UF2 size and SHA-256.
- [ ] Copy UF2 to the RPI-RP2 boot volume and wait for the serial device to return.
- [ ] Send RUNNING, DONE, and IDLE states and visually verify frame rate and transition continuity.
- [ ] Document measured behavior and any remaining hardware limitation.

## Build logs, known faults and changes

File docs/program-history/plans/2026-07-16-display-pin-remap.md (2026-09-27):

# Display Pin Remap Implementation Plan

> **For agentic workers:** REQUIRED SUB-SKILL: Use superpowers:subagent-driven-development (recommended) or superpowers:executing-plans to implement this plan task-by-task. Steps use checkbox (`- [ ]`) syntax for tracking.

**Goal:** Remap the ST7789 signal pins to SCL=PB9, SDA=PB8, RES=PB7, DC=PB6, and BLK=PB5, then program a static RGB diagnostic build.

**Architecture:** Keep the existing software SPI and color-bar diagnostic paths. Only the GPIO pin constants change; power remains GND and 3.3V. Automated source tests lock the mapping before the firmware is rebuilt and programmed.

**Tech Stack:** STM32F103 HAL, C, GNU Arm Embedded Toolchain, pytest, STM32CubeProgrammer

## Global Constraints

- ST7789 GND connects to STM32 GND and VCC connects to STM32 3.3V.
- Use software SPI because PB9/PB8 are not a hardware SPI clock/data pair.
- Keep static red, green, and blue bars enabled until visual hardware verification succeeds.

---

### Task 1: Remap And Program The Display

**Files:**
- Modify: `tools/test_display_transport.py`
- Modify: `Core/Src/oled.c`

**Interfaces:**
- Consumes: Existing `LCD_*_PIN` constants and software SPI transport.
- Produces: Firmware using PB9/PB8/PB7/PB6/PB5 for SCL/SDA/RES/DC/BLK.

- [ ] **Step 1: Write the failing pin-map test**

```python
def test_display_signal_pins_use_pb5_to_pb9_mapping():
    assert "#define LCD_SCL_PIN GPIO_PIN_9" in SOURCE
    assert "#define LCD_SDA_PIN GPIO_PIN_8" in SOURCE
    assert "#define LCD_RES_PIN GPIO_PIN_7" in SOURCE
    assert "#define LCD_DC_PIN GPIO_PIN_6" in SOURCE
    assert "#define LCD_BLK_PIN GPIO_PIN_5" in SOURCE
```

- [ ] **Step 2: Run the test and verify RED**

Run: `python -m pytest -q tools/test_display_transport.py -k pb5_to_pb9`

Expected: FAIL because the current constants still reference PB13/PB15/PB14/PB12/PB1.

- [ ] **Step 3: Change the display pin constants**

```c
#define LCD_SCL_PIN GPIO_PIN_9
#define LCD_SDA_PIN GPIO_PIN_8
#define LCD_RES_PIN GPIO_PIN_7
#define LCD_DC_PIN GPIO_PIN_6
#define LCD_BLK_PIN GPIO_PIN_5
```

- [ ] **Step 4: Run tests and build**

Run: `python -m pytest -q tools/test_display_transport.py tools/test_blossom_asset.py tools/test_pager_state.py`

Expected: all tests pass.

Run: `make -j4`

Expected: build completes and creates `build/codex_usb_pager.hex`.

- [ ] **Step 5: Program and verify the MCU**

Run: `STM32_Programmer_CLI.exe -c port=SWD -w build/codex_usb_pager.hex -v -rst`

Expected: `Download verified successfully` followed by an MCU reset.

- [ ] **Step 6: Commit the implementation**

```bash
git add codex_usb_pager/Core/Src/oled.c codex_usb_pager/tools/test_display_transport.py codex_usb_pager/docs/superpowers/plans/2026-07-16-display-pin-remap.md
git commit -m "fix: remap display signals to pb5-pb9"
```

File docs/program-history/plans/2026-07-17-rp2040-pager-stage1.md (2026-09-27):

# RP2040 Pager Stage 1 Implementation Plan

> **For agentic workers:** REQUIRED SUB-SKILL: Use superpowers:subagent-driven-development (recommended) or superpowers:executing-plans to implement this plan task-by-task. Steps use checkbox (`- [ ]`) syntax for tracking.

**Goal:** Build and flash a Pico SDK firmware that receives the existing pager protocol over USB CDC and renders every pager state on the RP2040-Zero onboard WS2812 at no more than 8 percent brightness.

**Architecture:** Keep protocol parsing and LED effect sampling in SDK-independent C modules with native host tests. The RP2040 entry point owns non-blocking USB CDC input, the eight-second offline timeout, and a GP16 WS2812 PIO driver. Stage 1 uses one core and does not connect the display or buzzer.

**Tech Stack:** Raspberry Pi Pico SDK 2.2.0, C11/C++17, CMake, NMake, ARM GNU Toolchain 14.3, PIO, pico_stdio_usb, Python pytest

## Global Constraints

- Controller is RP2040-Zero with 2 MB flash; configure the SDK as `PICO_BOARD=pico`.
- WS2812 DIN is GP16 and no RGB channel may exceed 20 out of 255.
- USB transport is CDC serial and remains compatible with `STATE <state> RUN=<n> WAIT=<n> DONE=<n> BAL=<token> EV=<event>\n`.
- Host heartbeat is two seconds and firmware enters OFFLINE after eight seconds without a valid snapshot.
- No display or buzzer wiring is added in stage 1.
- Future reserved pins are GP29/GP28/GP27/GP26/GP15 for SCL/SDA/RES/DC/BLK and GP14 for the active-low buzzer module.

---

### Task 1: Create The Testable Pager Core

**Files:**
- Create: `ports/rp2040-zero/firmware/include/pager_core.h`
- Create: `ports/rp2040-zero/firmware/src/pager_core.c`
- Create: `ports/rp2040-zero/tests/CMakeLists.txt`
- Create: `ports/rp2040-zero/tests/test_pager_core.c`

**Interfaces:**
- Produces: `bool pager_parse_line(const char *, pager_snapshot_t *)`, `pager_state_t pager_select_state(const pager_snapshot_t *)`, and `pager_state_t pager_apply_timeout(pager_state_t, uint32_t, uint32_t)`.
- Consumes: newline-free ASCII lines from the USB layer in Task 3.

- [ ] **Step 1: Write failing parser and state tests**

```c
static void test_valid_multi_snapshot(void) {
    pager_snapshot_t snapshot;
    assert(pager_parse_line("STATE RUNNING RUN=3 WAIT=0 DONE=14 BAL=82 EV=NONE", &snapshot));
    assert(snapshot.running == 3);
    assert(pager_select_state(&snapshot) == PAGER_MULTI);
}

static void test_wait_priority_and_timeout(void) {
    pager_snapshot_t snapshot;
    assert(pager_parse_line("STATE RUNNING RUN=2 WAIT=1 DONE=4 BAL=NA EV=WAIT", &snapshot));
    assert(pager_select_state(&snapshot) == PAGER_WAIT);
    assert(pager_apply_timeout(PAGER_WAIT, 1000, 9001) == PAGER_OFFLINE);
}

static void test_malformed_line_is_rejected(void) {
    pager_snapshot_t snapshot;
    assert(!pager_parse_line("STATE RUNNING RUN=x", &snapshot));
}
```

- [ ] **Step 2: Configure and run the native test to verify RED**

Run from a Visual Studio developer shell:

```powershell
cmake -S ports/rp2040-zero/tests -B build-rp2040-host -G "NMake Makefiles"
cmake --build build-rp2040-host
ctest --test-dir build-rp2040-host --output-on-failure
```

Expected: build fails because `pager_core.h` and its functions do not exist.

- [ ] **Step 3: Implement strict protocol parsing and state selection**

Define exact enums for `IDLE`, `RUNNING`, `MULTI`, `WAIT`, `DONE`, `ERROR`, and `OFFLINE`; parse all six required wire fields; reject unknown states, unknown events, missing fields, negative counts, overlong balance tokens, and trailing fields. Select ERROR first, then WAIT, then MULTI/RUNNING, then DONE/IDLE. Timeout when unsigned elapsed time is at least `8000U`.

- [ ] **Step 4: Run the native tests to verify GREEN**

Run the three commands from Step 2.

Expected: one test executable builds and all tests pass.

---

### Task 2: Implement Bounded LED Effects

**Files:**
- Create: `ports/rp2040-zero/firmware/include/led_effects.h`
- Create: `ports/rp2040-zero/firmware/src/led_effects.c`
- Modify: `ports/rp2040-zero/tests/CMakeLists.txt`
- Modify: `ports/rp2040-zero/tests/test_pager_core.c`

**Interfaces:**
- Produces: `pager_rgb_t pager_led_sample(pager_state_t state, uint32_t elapsed_ms)` with 8-bit `r`, `g`, and `b` fields.
- Consumes: `pager_state_t` from Task 1.

- [ ] **Step 1: Add failing color, timing, and brightness tests**

```c
static void assert_bounded(pager_rgb_t rgb) {
    assert(rgb.r <= 20 && rgb.g <= 20 && rgb.b <= 20);
}

static void test_led_effects(void) {
    pager_rgb_t idle = pager_led_sample(PAGER_IDLE, 0);
    pager_rgb_t run_a = pager_led_sample(PAGER_RUNNING, 0);
    pager_rgb_t run_b = pager_led_sample(PAGER_RUNNING, 900);
    pager_rgb_t wait_on = pager_led_sample(PAGER_WAIT, 40);
    pager_rgb_t wait_off = pager_led_sample(PAGER_WAIT, 300);
    assert(idle.r == idle.g && idle.g == idle.b);
    assert(run_a.b != run_b.b);
    assert(wait_on.r > wait_on.b);
    assert(wait_off.r < wait_on.r);
    for (int state = PAGER_IDLE; state <= PAGER_OFFLINE; ++state)
        for (uint32_t t = 0; t < 5000; t += 37)
            assert_bounded(pager_led_sample((pager_state_t)state, t));
}
```

- [ ] **Step 2: Run ctest and verify the new test fails**

Expected: compile or link failure because `pager_led_sample` is missing.

- [ ] **Step 3: Implement integer-only perceptual effects**

Implement low-brightness cool white IDLE, blue-purple triangular breathing RUNNING, alternating blue/purple MULTI, amber double-flash WAIT, soft green ease-out DONE, red triple-flash ERROR, and dim red slow-flash OFFLINE. Apply a small quadratic brightness curve and clamp every output channel to `20U`.

- [ ] **Step 4: Run ctest and verify all samples pass**

Expected: all host tests pass with no channel above 20.

---

### Task 3: Add Pico SDK Firmware And WS2812 PIO

**Files:**
- Create: `ports/rp2040-zero/firmware/CMakeLists.txt`
- Create: `ports/rp2040-zero/firmware/src/main.c`
- Create: `ports/rp2040-zero/firmware/src/ws2812.pio`
- Create: `ports/rp2040-zero/firmware/include/board_config.h`

**Interfaces:**
- Consumes: `pager_parse_line`, `pager_select_state`, `pager_apply_timeout`, and `pager_led_sample`.
- Produces: `codex_pager_rp2040.uf2`, a USB CDC device, and WS2812 output on GP16.

- [ ] **Step 1: Add compile-time board constraints**

```c
#define PAGER_WS2812_PIN 16U
#define PAGER_BUZZER_PIN 14U
#define PAGER_DISPLAY_BLK_PIN 15U
#define PAGER_DISPLAY_DC_PIN 26U
#define PAGER_DISPLAY_RES_PIN 27U
#define PAGER_DISPLAY_SDA_PIN 28U
#define PAGER_DISPLAY_SCL_PIN 29U
#define PAGER_OFFLINE_TIMEOUT_MS 8000U
#define PAGER_LINE_CAPACITY 96U
```

Add `_Static_assert(PAGER_WS2812_PIN == 16U, "RP2040-Zero WS2812 pin mismatch");` in `main.c`.

- [ ] **Step 2: Add the official-style WS2812 PIO program**

Use a four-instruction 800 kHz PIO program with side-set, generated by `pico_generate_pio_header`. Initialize one state machine on `pio0`, transmit GRB words, and never block longer than one LED word.

- [ ] **Step 3: Implement non-blocking USB CDC input**

Enable `pico_stdio_usb` and disable UART stdio. Poll `getchar_timeout_us(0)` in the main loop, accumulate at most 95 printable ASCII bytes, dispatch only on newline, reset the buffer after overflow, and update `last_valid_snapshot_ms` only when `pager_parse_line` succeeds.

- [ ] **Step 4: Integrate state and LED scheduling**

Initialize to OFFLINE, sample the current effect every 10 ms, reset `state_started_ms` when the selected state changes, and call `pager_apply_timeout` each loop. Sleep at most 1 ms so USB input remains responsive.

- [ ] **Step 5: Create the Pico SDK build target**

```cmake
cmake_minimum_required(VERSION 3.13)
include($ENV{PICO_SDK_PATH}/external/pico_sdk_import.cmake)
project(codex_pager_rp2040 C CXX ASM)
set(CMAKE_C_STANDARD 11)
set(CMAKE_CXX_STANDARD 17)
pico_sdk_init()
add_executable(codex_pager_rp2040
    src/main.c src/pager_core.c src/led_effects.c)
pico_generate_pio_header(codex_pager_rp2040
    ${CMAKE_CURRENT_LIST_DIR}/src/ws2812.pio)
target_include_directories(codex_pager_rp2040 PRIVATE include)
target_link_libraries(codex_pager_rp2040 PRIVATE pico_stdlib hardware_pio)
pico_enable_stdio_usb(codex_pager_rp2040 1)
pico_enable_stdio_uart(codex_pager_rp2040 0)
pico_add_extra_outputs(codex_pager_rp2040)
```

---

### Task 4: Make Host Discovery Support RP2040

**Files:**
- Modify: `tools/send_pager.py`
- Create: `tools/test_send_pager.py`

**Interfaces:**
- Consumes: pyserial port records.
- Produces: automatic discovery for both STM32 `0483:5740` and Raspberry Pi `2E8A:000A`, while retaining `--port` override.

- [ ] **Step 1: Write failing discovery tests**

```python
def test_find_port_accepts_rp2040(monkeypatch):
    ports = [SimpleNamespace(device="COM9", vid=0x2E8A, pid=0x000A)]
    monkeypatch.setattr(serial.tools.list_ports, "comports", lambda: ports)
    assert find_port() == "COM9"

def test_find_port_keeps_stm32_compatibility(monkeypatch):
    ports = [SimpleNamespace(device="COM5", vid=0x0483, pid=0x5740)]
    monkeypatch.setattr(serial.tools.list_ports, "comports", lambda: ports)
    assert find_port() == "COM5"
```

- [ ] **Step 2: Run pytest and verify the RP2040 test fails**

Run: `python -m pytest -q tools/test_send_pager.py`

Expected: STM32 passes and RP2040 fails.

- [ ] **Step 3: Generalize device discovery**

Replace STM32-only constants with an ordered tuple of supported VID/PID pairs and change user-facing errors from `STM32 USB CDC` to `Codex pager USB CDC`.

- [ ] **Step 4: Run the complete Python suite**

Run: `python -m pytest -q tools/test_send_pager.py tools/test_pager_state.py tools/test_pager_runtime.py`

Expected: all tests pass.

---

### Task 5: Install The Reproducible SDK And Build UF2

**Files:**
- Modify: `ports/rp2040-zero/README.md`
- Modify: `ports/rp2040-zero/port_manifest.json`
- Generated, not committed: `build-rp2040/`
- External dependency, not committed: `../third_party/pico-sdk/`

**Interfaces:**
- Consumes: official Raspberry Pi Pico SDK tag `2.2.0`, Visual Studio Build Tools, and ARM GNU Toolchain 14.3.
- Produces: `build-rp2040/codex_pager_rp2040.uf2`.

- [ ] **Step 1: Obtain the official SDK after network approval**

```powershell
git clone --branch 2.2.0 --depth 1 https://github.com/raspberrypi/pico-sdk.git ..\third_party\pico-sdk
git -C ..\third_party\pico-sdk submodule update --init --depth 1
```

- [ ] **Step 2: Configure a Visual Studio developer shell**

Call `VsDevCmd.bat -arch=x64`, add the existing ARM GCC `bin` directory to PATH, and set `PICO_SDK_PATH` to the absolute SDK directory. Verify `cl`, `nmake`, `arm-none-eabi-gcc`, and `cmake` all resolve.

- [ ] **Step 3: Configure and build the RP2040 target**

```powershell
cmake -S ports\rp2040-zero\firmware -B build-rp2040 -G "NMake Makefiles" -DPICO_BOARD=pico
cmake --build build-rp2040
```

Expected: CMake creates `.elf`, `.bin`, `.hex`, and `.uf2`; the UF2 is below 2 MB.

- [ ] **Step 4: Update migration metadata**

Record SDK `2.2.0`, stage 1 status, GP16 WS2812, GP14 buzzer reservation, left-side display pins, PIO+DMA display transport, and the exact host/build verification commands.

---

### Task 6: Flash And Perform The Hardware Smoke Test

**Files:**
- No source changes expected.

**Interfaces:**
- Consumes: mounted `RPI-RP2` drive and generated UF2.
- Produces: running firmware, a Windows COM port, and visible state effects.

- [ ] **Step 1: Re-run fresh verification before flashing**

Run native C tests, the complete Python suite from Task 4, and `cmake --build build-rp2040`. All commands must exit zero.

- [ ] **Step 2: Ask for explicit flash confirmation**

Confirm the board remains disconnected from the screen and buzzer and that `RPI-RP2` is mounted. Do not copy the UF2 without this confirmation.

- [ ] **Step 3: Copy UF2 and discover the new COM port**

```powershell
Copy-Item -LiteralPath build-rp2040\codex_pager_rp2040.uf2 -Destination D:\
```

Wait for `RPI-RP2` to disconnect, then locate VID/PID `2E8A:000A` through pyserial or Windows PnP.

- [ ] **Step 4: Send each state and visually verify the LED**

```powershell
python tools\send_pager.py IDLE --port COMx
python tools\send_pager.py RUNNING --run 1 --port COMx
python tools\send_pager.py RUNNING --run 3 --port COMx
python tools\send_pager.py WAIT --wait 1 --port COMx
python tools\send_pager.py DONE --done 1 --port COMx
python tools\send_pager.py ERROR --port COMx
```

Verify low-brightness cool white, blue-purple breathing, alternating multi-task color, amber double flash, green pop, and red triple flash. Stop heartbeats for more than eight seconds and verify dim red OFFLINE.

- [ ] **Step 5: Commit the stage 1 implementation**

```bash
git add codex_usb_pager/ports/rp2040-zero codex_usb_pager/tools/send_pager.py codex_usb_pager/tools/test_send_pager.py
git commit -m "feat: add rp2040 usb led pager"
```

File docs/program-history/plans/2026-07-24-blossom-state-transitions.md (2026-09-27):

# Blossom State Transitions Implementation Plan

> **For agentic workers:** REQUIRED SUB-SKILL: Use superpowers:subagent-driven-development (recommended) or superpowers:executing-plans to implement this plan task-by-task. Steps use checkbox (`- [ ]`) syntax for tracking.

**Goal:** Implement seamless six-piece Blossom animations for OFFLINE, READY, RUNNING, and the transitions between them on the RP2040 pager.

**Architecture:** Extend the generated Blossom asset with a packed six-piece ownership map whose union is the existing official alpha mask. Add a fixed-point scene-motion model that captures the current six-piece pose when a state changes, then renders state-specific continuous transitions without replacing the assembled pieces or freezing a frame. Keep the existing RGB565 scene buffer, 25 ms pacing, PIO, DMA, USB protocol, and non-Blossom status priority.

**Tech Stack:** Python 3, Pillow, C11, RP2040 Pico SDK, CMake/CTest, pytest, ST7789 RGB565 renderer.

## Global Constraints

- OFFLINE color is logical RGB `#738094`.
- READY color is logical RGB `#39D298`.
- RUNNING color is logical RGB `#6449E0`.
- READY to RUNNING uses 900 ms gather, 150 ms whole-logo hold, and 400 ms recolor before rotation begins.
- RUNNING or DONE to READY uses 350 ms deceleration, 350 ms recolor, and 800 ms separation.
- OFFLINE to READY lasts 1,200 ms and does not assemble the full Blossom.
- The weekly balance is an integer without a percent sign and appears only in READY.
- Six assembled piece masks must equal the official Blossom mask byte for byte.
- Animation uses elapsed time, fixed-point math, no per-frame heap allocation, and a 25 ms target frame interval.
- The verified ST7789 profile, 24 MHz display transport, 172 x 172 scene region, GPIO mapping, and USB protocol remain unchanged.

---

### Task 1: Generate A Lossless Six-Piece Blossom Asset

**Files:**
- Modify: `tools/generate_blossom_asset.py`
- Modify: `tools/test_blossom_asset.py`
- Regenerate: `Core/Inc/blossom_asset.h`
- Regenerate: `Core/Src/blossom_asset.c`

**Interfaces:**
- Produces: `partition_blossom(svg_path: Path, mask: Image.Image) -> Image.Image`
- Produces: `pack_piece_ids(piece_ids: Image.Image) -> bytes`
- Produces: `g_blossom_piece_id_4bpp[BLOSSOM_PIECE_ID_BYTES]`
- Produces: IDs `0` for background and `1..6` for the six woven pieces.

- [ ] **Step 1: Add failing asset-partition tests**

```python
def test_piece_partition_is_lossless():
    mask = rasterize_svg(SVG, size=128, supersample=4)
    pieces = partition_blossom(SVG, mask)
    mask_values = list(mask.getdata())
    piece_values = list(pieces.getdata())

    assert set(piece_values) <= set(range(7))
    assert all(
        (alpha == 0 and piece == 0) or (alpha > 0 and 1 <= piece <= 6)
        for alpha, piece in zip(mask_values, piece_values)
    )
    assert {piece for piece in piece_values if piece} == set(range(1, 7))

def test_piece_ids_pack_two_pixels_per_byte():
    mask = rasterize_svg(SVG, size=128, supersample=4)
    pieces = partition_blossom(SVG, mask)
    packed = pack_piece_ids(pieces)
    assert len(packed) == 128 * 128 // 2
```

- [ ] **Step 2: Run the focused tests and verify failure**

Run:

```powershell
python -m pytest tools/test_blossom_asset.py -q
```

Expected: collection fails because `partition_blossom` and
`pack_piece_ids` do not exist.

- [ ] **Step 3: Implement six-piece ownership**

Parse the official SVG subpaths, identify the six non-central interior holes,
rasterize each hole at the mask resolution, and calculate a two-pass chamfer
distance map for each hole. Assign every nonzero Blossom alpha pixel to the
nearest outer-hole map, sorting holes by polar angle so piece IDs are stable.
Pack two four-bit IDs per byte:

```python
def pack_piece_ids(piece_ids):
    values = list(piece_ids.getdata())
    if len(values) % 2:
        values.append(0)
    return bytes(
        ((values[index] & 0x0F) << 4) | (values[index + 1] & 0x0F)
        for index in range(0, len(values), 2)
    )
```

Update `emit_c` so the header declares:

```c
#define BLOSSOM_PIECE_COUNT 6U
#define BLOSSOM_PIECE_ID_BYTES 8192U
extern const uint8_t
    g_blossom_piece_id_4bpp[BLOSSOM_PIECE_ID_BYTES];
```

- [ ] **Step 4: Regenerate and test the assets**

Run:

```powershell
python tools/generate_blossom_asset.py
python -m pytest tools/test_blossom_asset.py -q
```

Expected: all Blossom asset tests pass and the generated C file contains
exactly `8192` alpha bytes plus `8192` piece-ID bytes.

- [ ] **Step 5: Commit the asset work**

```powershell
git add tools/generate_blossom_asset.py tools/test_blossom_asset.py Core/Inc/blossom_asset.h Core/Src/blossom_asset.c
git commit -m "feat: generate lossless blossom pieces"
```

### Task 2: Add The Fixed-Point Blossom Motion Model

**Files:**
- Create: `ports/rp2040-zero/firmware/include/blossom_motion.h`
- Create: `ports/rp2040-zero/firmware/src/blossom_motion.c`
- Modify: `ports/rp2040-zero/firmware/CMakeLists.txt`
- Modify: `ports/rp2040-zero/tests/CMakeLists.txt`
- Modify: `ports/rp2040-zero/tests/test_pager_core.c`

**Interfaces:**
- Produces: `pager_blossom_piece_pose_t`
- Produces: `pager_blossom_model_t`
- Produces: `pager_blossom_motion_t`
- Produces: `void pager_blossom_motion_init(...)`
- Produces: `void pager_blossom_motion_set_target(...)`
- Produces: `void pager_blossom_motion_sample(...)`

- [ ] **Step 1: Add failing motion tests**

Add tests that assert:

```c
assert(PAGER_READY_TO_RUNNING_MS == 1450U);
assert(PAGER_RUNNING_TO_READY_MS == 1500U);
assert(PAGER_OFFLINE_TO_READY_MS == 1200U);
```

Sample READY to RUNNING at `0`, `900`, `1050`, and `1450` ms and verify:

- position starts separated and ends assembled;
- balance opacity reaches zero before recolor;
- all six pieces are green at 1050 ms;
- all six pieces are deep purple at 1450 ms;
- running angular velocity is zero before 1450 ms and positive afterward.

Sample RUNNING to READY and OFFLINE to READY endpoints and verify their piece
positions, colors, balance opacity, and ordered-orbit flags.

- [ ] **Step 2: Run the C host tests and verify failure**

Run:

```powershell
cmake -S ports/rp2040-zero/tests -B build-rp2040-host
cmake --build build-rp2040-host
ctest --test-dir build-rp2040-host --output-on-failure
```

Expected: compilation fails because `blossom_motion.h` is absent.

- [ ] **Step 3: Implement the motion data structures**

Use these public structures:

```c
typedef struct {
    int16_t center_x_q8;
    int16_t center_y_q8;
    int16_t angle_q8;
    uint16_t scale_q12;
    uint16_t color;
    uint8_t opacity;
} pager_blossom_piece_pose_t;

typedef struct {
    pager_blossom_piece_pose_t pieces[BLOSSOM_PIECE_COUNT];
    uint8_t balance_opacity;
    int16_t angular_velocity_q8;
    bool assembled;
} pager_blossom_model_t;

typedef struct {
    pager_state_t source;
    pager_state_t target;
    uint32_t started_ms;
    pager_blossom_model_t start;
    pager_blossom_model_t current;
} pager_blossom_motion_t;
```

Use Q15 smoothstep interpolation and the existing sine table. READY targets
are six evenly spaced positions on the orbit. OFFLINE targets use six fixed,
asymmetric anchors plus independent sine phases. RUNNING targets share the
display center and zero relative piece angles.

- [ ] **Step 4: Implement interruption from the current pose**

`pager_blossom_motion_set_target` first samples the active motion at `now_ms`,
copies `current` to `start`, and then changes `source`, `target`, and
`started_ms`. It must never reset pieces to a canned source endpoint.

- [ ] **Step 5: Run motion tests**

Run the host configure, build, and CTest commands from Step 2.

Expected: all existing tests and the new motion tests pass.

- [ ] **Step 6: Commit the motion model**

```powershell
git add ports/rp2040-zero/firmware/include/blossom_motion.h ports/rp2040-zero/firmware/src/blossom_motion.c ports/rp2040-zero/firmware/CMakeLists.txt ports/rp2040-zero/tests/CMakeLists.txt ports/rp2040-zero/tests/test_pager_core.c
git commit -m "feat: add blossom state motion"
```

### Task 3: Render Six Pieces And Integrate State Changes

**Files:**
- Modify: `ports/rp2040-zero/firmware/include/display_scene.h`
- Modify: `ports/rp2040-zero/firmware/src/display_scene.c`
- Modify: `ports/rp2040-zero/firmware/src/display_ui.c`
- Modify: `tools/test_rp2040_display_ui.py`
- Modify: `ports/rp2040-zero/tests/test_pager_core.c`

**Interfaces:**
- Consumes: `pager_blossom_model_t`
- Produces: `pager_scene_render_model_row(...)`
- Produces: piece-aware `sampler_alpha_for_piece(...)`

- [ ] **Step 1: Add failing renderer and UI tests**

Add host tests that reconstruct the assembled frame with all six piece IDs and
compare it with the existing official full-mask frame. Add source-contract
tests that assert the specialized Blossom path does not call
`blend_from_frozen`, and that state changes call
`pager_blossom_motion_set_target`.

- [ ] **Step 2: Run focused tests and verify failure**

Run:

```powershell
python -m pytest tools/test_rp2040_display_ui.py -q
ctest --test-dir build-rp2040-host --output-on-failure
```

Expected: new assertions fail against the generic frozen-frame transition.

- [ ] **Step 3: Add piece-aware sampling**

Decode `g_blossom_piece_id_4bpp` alongside the alpha nibble:

```c
static uint8_t piece_id_value(int16_t x, int16_t y);
static uint8_t sampler_alpha_for_piece(
    logo_sampler_t *sampler, uint8_t piece_id);
```

Render six transformed piece layers from `pager_blossom_model_t`. In steady
RUNNING, use the existing single full-logo sampler for performance. In READY,
OFFLINE, and specialized transitions, use piece masks and skip sampling rows
outside each transformed piece bound.

- [ ] **Step 4: Render READY balance without a percent sign**

Change `format_balance` to return the validated one-to-three digit string
unchanged. Draw it at the scene center with opacity from the motion model.
Remove `WEEK` from READY. Preserve `BAL=NA` behavior.

- [ ] **Step 5: Replace specialized frozen-frame cross-fades**

`display_ui.c` owns one `pager_blossom_motion_t`. On every state update it
captures the current model and sets the new target. `render_frame` passes the
sampled model into the scene renderer for transitions involving OFFLINE,
READY, RUNNING, MULTI, or the end of DONE. Generic frozen-frame blending
remains only for WAIT and ERROR transitions.

- [ ] **Step 6: Run all host tests**

Run:

```powershell
python -m pytest tools/test_blossom_asset.py tools/test_rp2040_display_ui.py -q
cmake --build build-rp2040-host
ctest --test-dir build-rp2040-host --output-on-failure
```

Expected: all Python and C host tests pass.

- [ ] **Step 7: Commit renderer integration**

```powershell
git add ports/rp2040-zero/firmware/include/display_scene.h ports/rp2040-zero/firmware/src/display_scene.c ports/rp2040-zero/firmware/src/display_ui.c tools/test_rp2040_display_ui.py ports/rp2040-zero/tests/test_pager_core.c
git commit -m "feat: animate blossom state transitions"
```

### Task 4: Build, Flash, And Verify The Device

**Files:**
- Modify if required: `ports/rp2040-zero/README.md`
- Output: `build-rp2040/codex_usb_pager_rp2040.uf2`

**Interfaces:**
- Consumes: completed firmware and the existing RPI-RP2 mass-storage bootloader.
- Produces: flashed RP2040 pager with the approved state animations.

- [ ] **Step 1: Run the complete regression suite**

Run:

```powershell
python -m pytest -q
cmake --build build-rp2040-host
ctest --test-dir build-rp2040-host --output-on-failure
```

Expected: all tests pass.

- [ ] **Step 2: Build RP2040 firmware**

Run:

```powershell
powershell -ExecutionPolicy Bypass -File tools/build_rp2040.ps1
```

Expected: the UF2 is produced, flash and SRAM fit RP2040 limits, and no PDB
service remains locked.

- [ ] **Step 3: Flash the UF2**

Detect the mounted `RPI-RP2` volume and copy the generated UF2 to it. Wait for
the volume to disappear and the serial device to return. Do not ask the user
to press BOOT unless the volume is absent.

- [ ] **Step 4: Exercise live transitions**

Send or trigger, in order:

```text
OFFLINE -> READY -> RUNNING -> DONE -> READY
```

Verify on the physical panel:

- offline scatter becomes the ordered green ready orbit;
- the balance appears in the ready center;
- ready gathers into a gap-free green Blossom;
- green changes to deep purple before rotation starts;
- running rotation never intentionally pauses;
- completion returns through the green separation animation;
- no black band, square shadow, full-frame flash, or row refresh wave appears.

- [ ] **Step 5: Document verified behavior and commit**

Update the RP2040 README with the three colors, transition order, and automatic
flashing behavior, then commit:

```powershell
git add ports/rp2040-zero/README.md
git commit -m "docs: record blossom transition behavior"
```

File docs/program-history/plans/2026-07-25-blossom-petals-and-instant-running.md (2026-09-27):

# Blossom Petals And Instant Running Implementation Plan

> **For agentic workers:** REQUIRED SUB-SKILL: Use superpowers:subagent-driven-development (recommended) or superpowers:executing-plans to implement this plan task-by-task. Steps use checkbox (`- [ ]`) syntax for tracking.

**Goal:** Render READY/OFFLINE from six canonical, equal-width closed Blossom petals, crossfade them cleanly into the full rotating Blossom, and send RUNNING to the RP2040 within 100 ms of Codex accepting a prompt.

**Architecture:** Asset generation derives all six closed petal rings from the six outer hole contours in `assets/openai-blossom.svg` at one global scale and emits both masks and clipping metadata. Firmware motion keeps the six-petal layer and full-Blossom layer separate so transitions can move petals and crossfade masks without a geometry jump. The Windows daemon adds a read-only incremental watcher for Codex's SQLite diagnostic log while retaining JSONL for completion and fallback.

**Tech Stack:** Python 3.11, Pillow, standard-library SQLite, pytest, C11, CMake, Raspberry Pi Pico SDK, RP2040 PIO SPI, ST7789 RGB565.

## Global Constraints

- `assets/openai-blossom.svg` is the only geometry source.
- Canonical ribbon width is exactly `15.889` SVG units before raster scaling.
- All six petal rings use one global transform; never crop, fit, or normalize a petal independently.
- READY petals are green; RUNNING is a visibly deeper purple.
- READY to RUNNING aggregation lasts exactly `800 ms`.
- The first sampled RUNNING transition frame is purple.
- READY balance is centered and contains digits only.
- Existing display wiring, ST7789 profile, weekly balance, buzzer, USB CDC protocol, and state priority remain unchanged.
- SQLite prompt detection is read-only, WAL-compatible, cursor-based, and targets less than `100 ms` from log insertion to serial send.
- JSONL remains the completion source and a deduplicated prompt-start fallback.
- Do not replace generated C assets when generation fails.
- Do not stage or revert unrelated files in the existing dirty worktree.

## File Structure

- `tools/generate_blossom_asset.py`: canonical SVG rasterization, six outward petal-ring masks, packed asset data, and generated clip metadata.
- `tools/test_blossom_asset.py`: geometry, ring closure, width consistency, shared transform, and generated-output regression tests.
- `Core/Inc/blossom_asset.h`: generated asset declarations shared by STM32 and RP2040 builds.
- `Core/Src/blossom_asset.c`: generated full mask, six ring masks, and mask-bound metadata.
- `ports/rp2040-zero/firmware/include/blossom_motion.h`: transition durations and the two-layer render model.
- `ports/rp2040-zero/firmware/src/blossom_motion.c`: READY, OFFLINE, RUNNING, aggregation, separation, and recolor timelines.
- `ports/rp2040-zero/firmware/src/display_scene.c`: simultaneous petal/full-mask rendering with independent opacity.
- `ports/rp2040-zero/tests/test_pager_core.c`: host-side motion contract tests.
- `tools/codex_log_watcher.py`: focused read-only SQLite cursor and UserInput parser.
- `tools/test_codex_log_watcher.py`: temporary SQLite integration tests.
- `tools/pager_daemon.py`: combine immediate SQLite starts with JSONL completion/fallback.
- `tools/test_session_watcher.py`: daemon event integration and deduplication tests.
- `tools/render_blossom_partition_preview.py`: preview utility updated to call the production generator rather than carrying separate geometry logic.

---

### Task 1: Generate Canonical Closed Petal Rings

**Files:**
- Modify: `tools/test_blossom_asset.py`
- Modify: `tools/generate_blossom_asset.py`
- Modify: `tools/render_blossom_partition_preview.py`
- Regenerate: `Core/Inc/blossom_asset.h`
- Regenerate: `Core/Src/blossom_asset.c`

**Interfaces:**
- Consumes: `rasterize_svg(svg_path, size) -> PIL.Image.Image` and the six SVG hole contours.
- Produces: `rasterize_petals(svg_path, size, ribbon_width_svg=15.889) -> list[PIL.Image.Image]`.
- Produces: generated arrays `g_blossom_piece_min_x`, `g_blossom_piece_min_y`, `g_blossom_piece_max_x`, `g_blossom_piece_max_y`, and `g_blossom_piece_radius`.

- [ ] **Step 1: Add failing tests for shared-scale closed rings**

Add these helpers and tests to `tools/test_blossom_asset.py`:

```python
from PIL import Image

def mask_bbox(mask: Image.Image) -> tuple[int, int, int, int]:
    box = mask.getbbox()
    assert box is not None
    return box

def ring_width_samples(mask: Image.Image) -> list[int]:
    pixels = mask.load()
    widths: list[int] = []
    for y in range(mask.height):
        runs: list[int] = []
        current = 0
        for x in range(mask.width):
            if pixels[x, y] >= 8:
                current += 1
            elif current:
                runs.append(current)
                current = 0
        if current:
            runs.append(current)
        widths.extend(run for run in runs if 3 <= run <= 32)
    return widths

def test_petals_are_six_closed_equal_width_rings() -> None:
    petals = generator.rasterize_petals(SVG, size=128)
    assert len(petals) == 6
    medians = []
    for petal in petals:
        widths = sorted(ring_width_samples(petal))
        assert widths
        medians.append(widths[len(widths) // 2])
        box = mask_bbox(petal)
        assert box[0] >= 0 and box[1] >= 0
        assert box[2] <= 128 and box[3] <= 128
    assert max(medians) - min(medians) <= 1

def test_petals_keep_one_global_scale() -> None:
    small = generator.rasterize_petals(SVG, size=128)
    large = generator.rasterize_petals(SVG, size=192)
    for small_mask, large_mask in zip(small, large, strict=True):
        sw = mask_bbox(small_mask)[2] - mask_bbox(small_mask)[0]
        lw = mask_bbox(large_mask)[2] - mask_bbox(large_mask)[0]
        assert abs(lw / sw - 1.5) < 0.08

def test_full_blossom_mask_is_unchanged_by_petal_generation() -> None:
    before = generator.rasterize_svg(SVG, size=128).tobytes()
    generator.rasterize_petals(SVG, size=128)
    after = generator.rasterize_svg(SVG, size=128).tobytes()
    assert after == before
```

- [ ] **Step 2: Run the new tests and verify RED**

Run:

```powershell
python -m pytest tools/test_blossom_asset.py -k "petals_are_six or petals_keep_one or full_blossom_mask" -v --basetemp "$env:TEMP\saltyfish-petal-red"
```

Expected: the first two tests fail because `rasterize_petals` does not exist; the full-mask test may also error at the same missing call.

- [ ] **Step 3: Implement outward-only ring rasterization**

In `tools/generate_blossom_asset.py`, preserve the existing SVG contour parser and add:

```python
CANONICAL_RIBBON_WIDTH_SVG = 15.889

def _binary_dilate_outward(
    hole: Image.Image,
    radius_px: float,
) -> Image.Image:
    source = hole.convert("L")
    width, height = source.size
    values = list(source.getdata())
    distance = _chamfer_distance(
        [1 if value else 0 for value in values],
        width,
        height,
    )
    threshold = int(round(radius_px * 1000.0))
    output = Image.new("L", source.size, 0)
    output.putdata(
        255 if not values[index] and distance[index] <= threshold else 0
        for index in range(width * height)
    )
    return output

def rasterize_petals(
    svg_path: Path,
    size: int = 128,
    supersample: int = 4,
    ribbon_width_svg: float = CANONICAL_RIBBON_WIDTH_SVG,
) -> list[Image.Image]:
    view_box, contours = _outer_lobes(svg_path)
    high_size = size * supersample
    min_x, min_y, view_width, view_height = view_box
    scale = min(high_size / view_width, high_size / view_height)
    offset_x = (high_size - view_width * scale) / 2.0 - min_x * scale
    offset_y = (high_size - view_height * scale) / 2.0 - min_y * scale
    radius_px = ribbon_width_svg * scale
    petals: list[Image.Image] = []
    for contour in contours:
        hole = Image.new("L", (high_size, high_size), 0)
        draw = ImageDraw.Draw(hole)
        points = [
            (x * scale + offset_x, y * scale + offset_y)
            for x, y in contour
        ]
        draw.polygon(points, fill=255)
        expanded = _binary_dilate_outward(hole, radius_px)
        ring = ImageChops.subtract(expanded, hole)
        ring = ring.resize((size, size), Image.Resampling.LANCZOS)
        petals.append(
            ring.point(
                lambda value: min(15, max(0, (value * 15 + 127) // 255))
            )
        )
    if len(petals) != 6:
        raise ValueError(f"expected six Blossom holes, found {len(petals)}")
    return petals
```

Import `ImageChops` from Pillow. Replace the old `rasterize_piece_strokes(...)` call in `main()` with `rasterize_petals(...)`; `_outer_lobes(...)` remains the single contour parser.

- [ ] **Step 4: Emit clip metadata from the generated masks**

Add:

```python
def petal_bounds(
    masks: list[Image.Image],
) -> tuple[list[int], list[int], list[int], list[int], list[int]]:
    minimum_x: list[int] = []
    minimum_y: list[int] = []
    maximum_x: list[int] = []
    maximum_y: list[int] = []
    radius: list[int] = []
    for mask in masks:
        box = mask.getbbox()
        if box is None:
            raise ValueError("generated Blossom petal is empty")
        left, top, right, bottom = box
        right -= 1
        bottom -= 1
        minimum_x.append(left)
        minimum_y.append(top)
        maximum_x.append(right)
        maximum_y.append(bottom)
        radius.append(max(right - left, bottom - top) // 2 + 2)
    return minimum_x, minimum_y, maximum_x, maximum_y, radius
```

Extend generated declarations with:

```c
extern const uint8_t g_blossom_piece_min_x[BLOSSOM_PIECE_COUNT];
extern const uint8_t g_blossom_piece_min_y[BLOSSOM_PIECE_COUNT];
extern const uint8_t g_blossom_piece_max_x[BLOSSOM_PIECE_COUNT];
extern const uint8_t g_blossom_piece_max_y[BLOSSOM_PIECE_COUNT];
extern const uint8_t g_blossom_piece_radius[BLOSSOM_PIECE_COUNT];
```

Emit the five arrays after `g_blossom_piece_alpha_4bpp` in `Core/Src/blossom_asset.c`.

- [ ] **Step 5: Make the preview use production geometry**

Replace the preview-only dilation code in `tools/render_blossom_partition_preview.py` with:

```python
piece_masks = rasterize_petals(
    ROOT / "assets" / "openai-blossom.svg",
    size=128,
)
```

Remove the `skimage` import and `uniform_ribbon_pieces()` so the accepted preview and firmware assets cannot diverge.

- [ ] **Step 6: Run asset tests and regenerate assets**

Run:

```powershell
python -m pytest tools/test_blossom_asset.py -v --basetemp "$env:TEMP\saltyfish-petal-green"
python tools/generate_blossom_asset.py --svg assets/openai-blossom.svg --header Core/Inc/blossom_asset.h --source Core/Src/blossom_asset.c
python tools/render_blossom_partition_preview.py
```

Expected: all asset tests pass, generator exits `0`, and `outputs/blossom_partition_preview.png` contains six equal-width closed rings matching the accepted preview.

- [ ] **Step 7: Commit only the asset task**

```powershell
git add tools/test_blossom_asset.py tools/generate_blossom_asset.py tools/render_blossom_partition_preview.py Core/Inc/blossom_asset.h Core/Src/blossom_asset.c outputs/blossom_partition_preview.png
git commit -m "fix: generate canonical Blossom petal rings"
```

---

### Task 2: Crossfade Petal And Full-Blossom Layers

**Files:**
- Modify: `ports/rp2040-zero/firmware/include/blossom_motion.h`
- Modify: `ports/rp2040-zero/firmware/src/blossom_motion.c`
- Modify: `ports/rp2040-zero/firmware/src/display_scene.c`
- Modify: `ports/rp2040-zero/tests/test_pager_core.c`

**Interfaces:**
- Consumes: six generated petal masks and clip arrays from Task 1.
- Produces: `pager_blossom_model_t.petal_layer_opacity` and `pager_blossom_model_t.full_layer_opacity`.
- Produces: an `800 ms` READY-to-RUNNING transition whose first frame is purple.

- [ ] **Step 1: Replace old assembled tests with failing two-layer contracts**

In `ports/rp2040-zero/tests/test_pager_core.c`, replace assertions based on `assembled` with:

```c
static void test_ready_to_running_crossfades_without_pause(void) {
    pager_blossom_motion_t motion;
    pager_blossom_model_t start;
    pager_blossom_model_t middle;
    pager_blossom_model_t finish;

    pager_blossom_motion_init(&motion, PAGER_IDLE, 1000U);
    pager_blossom_motion_set_target(&motion, PAGER_RUNNING, 1000U);
    pager_blossom_motion_sample(&motion, 1000U, &start);
    pager_blossom_motion_sample(&motion, 1640U, &middle);
    pager_blossom_motion_sample(&motion, 1800U, &finish);

    assert(PAGER_READY_TO_RUNNING_MS == 800U);
    assert(start.pieces[0].color == PAGER_BLOSSOM_RUNNING_COLOR);
    assert(start.petal_layer_opacity == 255U);
    assert(start.full_layer_opacity == 0U);
    assert(middle.petal_layer_opacity > 0U);
    assert(middle.full_layer_opacity > 0U);
    assert(finish.petal_layer_opacity == 0U);
    assert(finish.full_layer_opacity == 255U);
    assert(finish.pieces[0].scale_q12 == start.pieces[0].scale_q12);
}

static void test_running_to_ready_reverses_crossfade(void) {
    pager_blossom_motion_t motion;
    pager_blossom_model_t middle;
    pager_blossom_model_t finish;

    pager_blossom_motion_init(&motion, PAGER_RUNNING, 2000U);
    pager_blossom_motion_set_target(&motion, PAGER_IDLE, 2000U);
    pager_blossom_motion_sample(&motion, 2700U, &middle);
    pager_blossom_motion_sample(
        &motion, 2000U + PAGER_RUNNING_TO_READY_MS, &finish);

    assert(middle.petal_layer_opacity > 0U);
    assert(middle.full_layer_opacity > 0U);
    assert(finish.petal_layer_opacity == 255U);
    assert(finish.full_layer_opacity == 0U);
    assert(finish.balance_opacity == 255U);
    assert(finish.ordered_orbit);
}

static void test_offline_to_ready_never_uses_full_layer(void) {
    pager_blossom_motion_t motion;
    pager_blossom_model_t middle;

    pager_blossom_motion_init(&motion, PAGER_OFFLINE, 3000U);
    pager_blossom_motion_set_target(&motion, PAGER_IDLE, 3000U);
    pager_blossom_motion_sample(&motion, 3600U, &middle);

    assert(middle.petal_layer_opacity == 255U);
    assert(middle.full_layer_opacity == 0U);
}
```

Call all three tests from `main()`.

- [ ] **Step 2: Run host tests and verify RED**

Run:

```powershell
powershell -ExecutionPolicy Bypass -File tools/run_host_tests.ps1
```

Expected: compilation fails because the two opacity fields do not exist, or assertions fail against the old `1450 ms` timeline.

- [ ] **Step 3: Extend the render model**

In `blossom_motion.h`, use:

```c
#define PAGER_READY_TO_RUNNING_MS 800U
#define PAGER_RUNNING_TO_READY_MS 1200U
#define PAGER_OFFLINE_TO_READY_MS 1200U

typedef struct {
    pager_blossom_piece_pose_t pieces[BLOSSOM_PIECE_COUNT];
    uint8_t balance_opacity;
    uint8_t petal_layer_opacity;
    uint8_t full_layer_opacity;
    int16_t angular_velocity_q8;
    bool ordered_orbit;
} pager_blossom_model_t;
```

Remove `assembled`; the renderer must no longer select one layer with a boolean.

- [ ] **Step 4: Implement the exact aggregation timeline**

Set layer defaults in model builders:

```c
static void assembled_model(
    pager_blossom_model_t *model,
    uint16_t color,
    int16_t angle_q8) {
    model->petal_layer_opacity = 0U;
    model->full_layer_opacity = 255U;
}

static void ready_model(pager_blossom_model_t *model, uint32_t elapsed_ms) {
    model->petal_layer_opacity = 255U;
    model->full_layer_opacity = 0U;
}

static void offline_model(pager_blossom_model_t *model, uint32_t elapsed_ms) {
    model->petal_layer_opacity = 255U;
    model->full_layer_opacity = 0U;
}
```

The snippets above are exact assignments added after each builder's current pose loop. Keep each builder's current `memset`, position, angle, scale, color, balance, orbit, and velocity assignments unchanged.

Interpolate both opacity fields in `lerp_model()`:

```c
result->petal_layer_opacity = lerp_u8(
    from->petal_layer_opacity, to->petal_layer_opacity, amount_q15);
result->full_layer_opacity = lerp_u8(
    from->full_layer_opacity, to->full_layer_opacity, amount_q15);
```

Implement READY to RUNNING with a `640 ms` gather and `160 ms` crossfade:

```c
static void sample_ready_to_running(
    const pager_blossom_motion_t *motion,
    uint32_t elapsed,
    pager_blossom_model_t *model) {
    pager_blossom_model_t gathered;
    pager_blossom_model_t full;
    uint8_t piece;

    assembled_model(&gathered, PAGER_BLOSSOM_RUNNING_COLOR, 0);
    gathered.petal_layer_opacity = 255U;
    gathered.full_layer_opacity = 0U;
    for (piece = 0U; piece < BLOSSOM_PIECE_COUNT; ++piece) {
        gathered.pieces[piece].color = PAGER_BLOSSOM_RUNNING_COLOR;
    }
    if (elapsed < 640U) {
        pager_blossom_model_t purple_start = motion->start;
        for (piece = 0U; piece < BLOSSOM_PIECE_COUNT; ++piece) {
            purple_start.pieces[piece].color = PAGER_BLOSSOM_RUNNING_COLOR;
        }
        purple_start.balance_opacity = 0U;
        lerp_model(
            &purple_start, &gathered, smooth_q15(elapsed, 640U), model);
        model->petal_layer_opacity = 255U;
        model->full_layer_opacity = 0U;
        return;
    }
    if (elapsed <= PAGER_READY_TO_RUNNING_MS) {
        full = gathered;
        full.petal_layer_opacity = 0U;
        full.full_layer_opacity = 255U;
        lerp_model(
            &gathered,
            &full,
            smooth_q15(elapsed - 640U, 160U),
            model);
        return;
    }
    running_model(model, elapsed - PAGER_READY_TO_RUNNING_MS);
}
```

Implement RUNNING to READY as the reverse: ease rotation for `240 ms`, crossfade full purple to gathered green petals from `240-400 ms`, then separate those petals into the READY orbit from `400-1200 ms`. Keep scale `FULL_SCALE_Q12` through all phases.

- [ ] **Step 5: Render both layers with generated clip metadata**

In `display_scene.c`, replace hard-coded bounds with generated arrays:

```c
const int32_t source_center_x_q8 =
    ((int32_t)g_blossom_piece_min_x[piece] +
     g_blossom_piece_max_x[piece]) * 128;
const int32_t source_center_y_q8 =
    ((int32_t)g_blossom_piece_min_y[piece] +
     g_blossom_piece_max_y[piece]) * 128;
const uint8_t clip_radius = g_blossom_piece_radius[piece];
```

Multiply per-piece alpha by the petal layer opacity:

```c
const uint16_t opacity =
    ((uint16_t)pose->opacity * model->petal_layer_opacity + 127U) / 255U;
```

Render the full canonical mask whenever `full_layer_opacity != 0U`, using piece `0` as the common full-layer transform:

```c
if (model->full_layer_opacity != 0U) {
    pager_blossom_piece_pose_t full_pose = model->pieces[0];
    full_pose.opacity = (uint8_t)(
        ((uint16_t)full_pose.opacity * model->full_layer_opacity + 127U)
        / 255U);
    render_blossom_layer(
        frame,
        &full_pose,
        sample_full_blossom_alpha,
        0U,
        0U,
        BLOSSOM_ASSET_WIDTH - 1U,
        BLOSSOM_ASSET_HEIGHT - 1U);
}
```

Render the six petal masks first and the canonical full mask second so crossfade overlap converges to the exact RUNNING logo.

- [ ] **Step 6: Run host tests and firmware build**

Run:

```powershell
powershell -ExecutionPolicy Bypass -File tools/run_host_tests.ps1
powershell -ExecutionPolicy Bypass -File tools/build_rp2040.ps1
```

Expected: host tests report success; firmware build exits `0`; SRAM and flash size checks stay within the existing limits.

- [ ] **Step 7: Commit only motion/render changes**

```powershell
git add ports/rp2040-zero/firmware/include/blossom_motion.h ports/rp2040-zero/firmware/src/blossom_motion.c ports/rp2040-zero/firmware/src/display_scene.c ports/rp2040-zero/tests/test_pager_core.c
git commit -m "feat: crossfade Blossom petals into running"
```

---

### Task 3: Detect Prompt Submission From Codex SQLite

**Files:**
- Create: `tools/codex_log_watcher.py`
- Create: `tools/test_codex_log_watcher.py`

**Interfaces:**
- Produces: `CodexLogWatcher(path: Path)`.
- Produces: `poll_events() -> list[tuple[str, str]]`, where events are `(thread_id, "UserPromptSubmit")`.
- The first poll initializes `last_id` to `MAX(logs.id)` and emits no stale events.

- [ ] **Step 1: Write a temporary-database integration test**

Create `tools/test_codex_log_watcher.py`:

```python
from pathlib import Path
import sqlite3

from codex_log_watcher import CodexLogWatcher

CREATE_LOGS = """
CREATE TABLE logs (
    id INTEGER PRIMARY KEY,
    ts TEXT,
    ts_nanos INTEGER,
    level TEXT,
    target TEXT,
    feedback_log_body TEXT,
    module_path TEXT,
    file TEXT,
    line INTEGER,
    thread_id TEXT,
    process_uuid TEXT,
    estimated_bytes INTEGER
)
"""

def insert_log(
    path: Path,
    *,
    target: str,
    body: str,
    thread_id: str | None,
) -> None:
    with sqlite3.connect(path) as connection:
        connection.execute(
            """
            INSERT INTO logs(target, feedback_log_body, thread_id)
            VALUES (?, ?, ?)
            """,
            (target, body, thread_id),
        )

def test_ignores_stale_rows_and_emits_new_user_input(tmp_path: Path) -> None:
    path = tmp_path / "logs_2.sqlite"
    with sqlite3.connect(path) as connection:
        connection.execute(CREATE_LOGS)
    insert_log(
        path,
        target="codex_core::session::handlers",
        body="Submission op: UserInput stale",
        thread_id="old",
    )
    watcher = CodexLogWatcher(path)
    assert watcher.poll_events() == []

    insert_log(path, target="other", body="noise", thread_id="noise")
    insert_log(
        path,
        target="codex_core::session::handlers",
        body="session_loop Submission sub=Submission op: UserInput text",
        thread_id="thread-7",
    )
    assert watcher.poll_events() == [("thread-7", "UserPromptSubmit")]
    assert watcher.poll_events() == []

def test_missing_thread_is_ignored_but_cursor_advances(tmp_path: Path) -> None:
    path = tmp_path / "logs_2.sqlite"
    with sqlite3.connect(path) as connection:
        connection.execute(CREATE_LOGS)
    watcher = CodexLogWatcher(path)
    assert watcher.poll_events() == []
    insert_log(
        path,
        target="codex_core::session::handlers",
        body="Submission op: UserInput",
        thread_id=None,
    )
    assert watcher.poll_events() == []
    assert watcher.poll_events() == []

def test_missing_database_recovers_after_creation(tmp_path: Path) -> None:
    path = tmp_path / "logs_2.sqlite"
    watcher = CodexLogWatcher(path)
    assert watcher.poll_events() == []
    with sqlite3.connect(path) as connection:
        connection.execute(CREATE_LOGS)
    assert watcher.poll_events() == []
    insert_log(
        path,
        target="codex_core::session::handlers",
        body="Submission op: UserInput",
        thread_id="thread-new",
    )
    assert watcher.poll_events() == [("thread-new", "UserPromptSubmit")]
```

- [ ] **Step 2: Run watcher tests and verify RED**

Run:

```powershell
python -m pytest tools/test_codex_log_watcher.py -v --basetemp "$env:TEMP\saltyfish-log-red"
```

Expected: collection fails with `ModuleNotFoundError: No module named 'codex_log_watcher'`.

- [ ] **Step 3: Implement the read-only incremental watcher**

Create `tools/codex_log_watcher.py`:

```python
from __future__ import annotations

from pathlib import Path
import sqlite3

TARGET = "codex_core::session::handlers"

class CodexLogWatcher:
    def __init__(self, path: str | Path) -> None:
        self.path = Path(path)
        self.last_id: int | None = None
        self._identity: tuple[int, int] | None = None

    def _file_identity(self) -> tuple[int, int]:
        stat = self.path.stat()
        return stat.st_dev, stat.st_ino

    def _connect(self) -> sqlite3.Connection:
        uri = self.path.resolve().as_uri() + "?mode=ro"
        connection = sqlite3.connect(uri, uri=True, timeout=0.02)
        connection.execute("PRAGMA query_only = ON")
        connection.execute("PRAGMA busy_timeout = 20")
        return connection

    def poll_events(self) -> list[tuple[str, str]]:
        try:
            identity = self._file_identity()
            if identity != self._identity:
                self._identity = identity
                self.last_id = None
            with self._connect() as connection:
                if self.last_id is None:
                    row = connection.execute(
                        "SELECT COALESCE(MAX(id), 0) FROM logs"
                    ).fetchone()
                    self.last_id = int(row[0])
                    return []
                rows = connection.execute(
                    """
                    SELECT id, target, feedback_log_body, thread_id
                    FROM logs
                    WHERE id > ?
                    ORDER BY id
                    """,
                    (self.last_id,),
                ).fetchall()
        except (OSError, sqlite3.Error):
            self._identity = None
            self.last_id = None
            return []

        events: list[tuple[str, str]] = []
        for row_id, target, body, thread_id in rows:
            self.last_id = max(self.last_id, int(row_id))
            if (
                target == TARGET
                and isinstance(body, str)
                and "Submission" in body
                and "op: UserInput" in body
                and isinstance(thread_id, str)
                and thread_id
            ):
                events.append((thread_id, "UserPromptSubmit"))
        return events
```

- [ ] **Step 4: Verify watcher behavior**

Run:

```powershell
python -m pytest tools/test_codex_log_watcher.py -v --basetemp "$env:TEMP\saltyfish-log-green"
```

Expected: all watcher tests pass.

- [ ] **Step 5: Add explicit database-replacement coverage**

Add:

```python
def test_database_replacement_reinitializes_without_replaying(tmp_path: Path) -> None:
    path = tmp_path / "logs_2.sqlite"
    with sqlite3.connect(path) as connection:
        connection.execute(CREATE_LOGS)
    watcher = CodexLogWatcher(path)
    assert watcher.poll_events() == []
    path.unlink()
    with sqlite3.connect(path) as connection:
        connection.execute(CREATE_LOGS)
    insert_log(
        path,
        target="codex_core::session::handlers",
        body="Submission op: UserInput replacement-stale",
        thread_id="stale-after-replace",
    )
    assert watcher.poll_events() == []
```

Run the test and keep it green.

- [ ] **Step 6: Commit the focused watcher**

```powershell
git add tools/codex_log_watcher.py tools/test_codex_log_watcher.py
git commit -m "feat: watch Codex prompt submissions in sqlite"
```

---

### Task 4: Integrate Immediate Starts Without Duplicate Sends

**Files:**
- Modify: `tools/pager_runtime.py`
- Modify: `tools/test_pager_runtime.py`
- Modify: `tools/pager_daemon.py`
- Modify: `tools/test_session_watcher.py`

**Interfaces:**
- Consumes: `CodexLogWatcher.poll_events()` from Task 3.
- Consumes: existing `SessionLogWatcher.poll_events()` for completion/fallback.
- Produces: one immediate snapshot send per task state change.

- [ ] **Step 1: Add failing daemon integration tests**

Add to `tools/test_session_watcher.py`:

```python
from pager_daemon import process_session_events

class QueueWatcher:
    def __init__(self, events):
        self.events = list(events)

    def poll_events(self):
        events = self.events
        self.events = []
        return events

def test_sqlite_prompt_event_immediately_sends_running(tmp_path: Path) -> None:
    store = RuntimeStore(tmp_path / "runtime.sqlite")
    sent = []
    watcher = QueueWatcher([("thread-fast", "UserPromptSubmit")])
    snapshot = process_session_events(store, watcher, sent.append, now=10.0)
    assert snapshot is not None
    assert snapshot.state == "RUNNING"
    assert snapshot.running == 1
    assert [item.state for item in sent] == ["RUNNING"]

def test_duplicate_prompt_does_not_send_same_snapshot_twice(tmp_path: Path) -> None:
    store = RuntimeStore(tmp_path / "runtime.sqlite")
    sent = []
    first = QueueWatcher([("thread-fast", "UserPromptSubmit")])
    fallback = QueueWatcher([("thread-fast", "UserPromptSubmit")])
    assert process_session_events(store, first, sent.append, now=10.0)
    assert process_session_events(store, fallback, sent.append, now=10.1) is None
    assert len(sent) == 1
```

- [ ] **Step 2: Run integration tests and verify RED**

Run:

```powershell
python -m pytest tools/test_session_watcher.py -k "sqlite_prompt or duplicate_prompt" -v --basetemp "$env:TEMP\saltyfish-daemon-red"
```

Expected: the immediate-send test passes with existing behavior, while duplicate suppression fails because `process_session_events` sends twice.

- [ ] **Step 3: Make RuntimeStore report whether a record changed**

Change `RuntimeStore.record(...)` to return `bool`:

```python
def record(self, session_id: str, event_name: str, now: float) -> bool:
    state = EVENT_STATES.get(event_name)
    if not state or not session_id:
        return False
```

Inside the existing transaction, immediately after assigning `previous`, add:

```python
if previous == state and state == "RUNNING":
    return False
changed = previous != state
```

After the existing UPSERT, add:

```python
return changed
```

Preserve existing WAIT/DONE pending-event semantics. A duplicate `UserPromptSubmit` for an already RUNNING task updates neither state nor `updated_at`, preventing the delayed JSONL fallback from extending the task TTL or sending a second serial frame.

Update `process_session_events()`:

```python
changed = False
for session_id, event_name in events:
    changed = store.record(session_id, event_name, now=current_time) or changed
if not changed:
    return None
return run_cycle(store, sender, now=current_time)
```

Add to `tools/test_pager_runtime.py`:

```python
def test_duplicate_running_event_reports_no_change(tmp_path: Path) -> None:
    store = make_store(tmp_path)
    assert store.record("thread-a", "UserPromptSubmit", now=10.0) is True
    assert store.record("thread-a", "UserPromptSubmit", now=10.1) is False
    assert store.snapshot(now=10.2).running == 1
```

- [ ] **Step 4: Add the SQLite watcher to the daemon loop**

Import and construct:

```python
from codex_log_watcher import CodexLogWatcher

prompt_watcher = CodexLogWatcher(Path.home() / ".codex" / "logs_2.sqlite")
session_watcher = SessionLogWatcher(Path.home() / ".codex" / "sessions")
```

Poll `prompt_watcher` first on every `100 ms` loop:

```python
prompt_snapshot = process_session_events(
    store, prompt_watcher, send_snapshot
)
if prompt_snapshot is not None:
    next_heartbeat = current_monotonic + interval

event_snapshot = process_session_events(
    store, session_watcher, send_snapshot
)
if event_snapshot is not None:
    next_heartbeat = current_monotonic + interval
```

Do not let a missing/locked SQLite database stop JSONL polling or heartbeat.

- [ ] **Step 5: Run all daemon/runtime tests**

Run:

```powershell
python -m pytest tools/test_codex_log_watcher.py tools/test_session_watcher.py tools/test_pager_runtime.py -v --basetemp "$env:TEMP\saltyfish-daemon-green"
```

Expected: all selected tests pass and duplicate prompt fallback sends only once.

- [ ] **Step 6: Commit daemon integration**

```powershell
git add tools/pager_daemon.py tools/pager_runtime.py tools/test_session_watcher.py tools/test_pager_runtime.py
git commit -m "feat: send running state immediately from Codex logs"
```

---

### Task 5: Full Verification, Daemon Restart, And RP2040 Flash

**Files:**
- Verify all changed files.
- Flash: `build-rp2040/codex_usb_pager.uf2` to the detected `RPI-RP2` drive.

**Interfaces:**
- Consumes: generated asset, firmware build, SQLite watcher, daemon integration.
- Produces: running RP2040 firmware and a restarted host daemon using the new watcher.

- [ ] **Step 1: Run the full Python test suite**

Run with a unique elevated base temp because the machine's default pytest temp ACL is known to be broken:

```powershell
$base = Join-Path $env:TEMP ("saltyfish-full-" + [guid]::NewGuid().ToString("N"))
python -m pytest -v --basetemp $base
```

Expected: all tests pass; no collection errors or warnings from project code.

- [ ] **Step 2: Run host C tests and rebuild firmware from clean staging**

Run:

```powershell
powershell -ExecutionPolicy Bypass -File tools/run_host_tests.ps1
powershell -ExecutionPolicy Bypass -File tools/build_rp2040.ps1
```

Expected: host test executable exits `0`; Pico build exits `0`; generated UF2 exists; reported SRAM use remains below the linker limit.

- [ ] **Step 3: Restart the pager daemon**

Find only the daemon process whose command line contains `tools\pager_daemon.py`, stop it, and start the current workspace copy hidden:

```powershell
Get-CimInstance Win32_Process |
    Where-Object { $_.CommandLine -like '*tools\pager_daemon.py*' } |
    ForEach-Object { Stop-Process -Id $_.ProcessId -Force }
Start-Process python `
    -ArgumentList 'tools\pager_daemon.py' `
    -WorkingDirectory 'C:\Users\28026\Documents\saltyfish\codex_usb_pager' `
    -WindowStyle Hidden
```

Expected: exactly one daemon process remains and it references the `saltyfish` workspace.

- [ ] **Step 4: Enter BOOTSEL and flash**

Trigger RP2040 USB boot by opening COM7 at 1200 baud, wait for the `RPI-RP2` volume, then copy the UF2:

```powershell
$port = New-Object System.IO.Ports.SerialPort 'COM7',1200,'None',8,'one'
try { $port.Open() } catch { }
finally { if ($port.IsOpen) { $port.Close() } }
Start-Sleep -Milliseconds 800
$drive = Get-Volume -FileSystemLabel 'RPI-RP2' |
    Select-Object -First 1 -ExpandProperty DriveLetter
if (-not $drive) { throw 'RPI-RP2 drive not found' }
Copy-Item -LiteralPath 'build-rp2040\codex_usb_pager.uf2' `
    -Destination "${drive}:\codex_usb_pager.uf2" -Force
```

Expected: `RPI-RP2` disconnects after the copy and COM7 returns as the pager CDC port.

- [ ] **Step 5: Verify firmware identity and host state latency**

Run:

```powershell
Get-PnpDevice -PresentOnly |
    Where-Object {
        $_.FriendlyName -match 'COM7|RP2040|Serial|CDC'
    } |
    Select-Object Status, FriendlyName, InstanceId
Get-FileHash -Algorithm SHA256 build-rp2040\codex_usb_pager.uf2
```

Then send one new Codex prompt. Compare its newest matching `logs.id` timestamp with the `tasks.updated_at` value in the pager runtime database. The measured difference must be below `0.100 s`, and the display must begin purple aggregation on the first visible frame.

- [ ] **Step 6: Perform visual acceptance checks**

Verify on the physical display:

1. READY shows six green equal-width closed petals and centered weekly digits.
2. READY orbit is slow and continuous.
3. Sending a prompt changes to purple immediately.
4. Six petals gather without pause, gap, or size jump.
5. The canonical full Blossom rotates continuously in RUNNING.
6. Completion reverses into six READY petals smoothly.
7. OFFLINE petals drift irregularly; reopening Codex settles them into READY without assembling.
8. No blue/black band, square ghost, row-wave refresh, or clipped petal appears.

- [ ] **Step 7: Record environment issues and recommendation**

Report each local issue observed during the run and whether it should be repaired:

- Broken pytest temp ACL: recommend repair only if it still reproduces outside the unique `--basetemp`; otherwise retain the workaround.
- Stale PDB/compiler service: recommend repair if build scripts still need to terminate it.
- COM7 1200-baud open exception during USB identity change: expected behavior; no repair recommended.
- Any duplicate daemon process or stale non-English workspace command line: repair immediately.

- [ ] **Step 8: Commit final verification documentation only if changed**

If verification updates `ports/rp2040-zero/README.md`, stage only that file:

```powershell
git add ports/rp2040-zero/README.md
git commit -m "docs: record Blossom pager verification"
```

Do not create an empty commit when no documentation changed.

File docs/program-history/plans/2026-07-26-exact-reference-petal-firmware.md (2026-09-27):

# Exact Reference Petal Firmware Implementation Plan

> **For Codex:** REQUIRED SUB-SKILL: Use executing-plans to implement this plan task-by-task.

**Goal:** Replace the obsolete inferred petal rings with the user-approved exact reference petal, apply the approved READY geometry, preserve smooth state transitions, and build a flashable RP2040 UF2.

**Architecture:** Keep the existing full SVG mask as the RUNNING fast path. Generate one canonical 4bpp petal sprite directly from the approved PNG and expose it through the existing six-piece asset interface without changing its geometry. The motion model owns all six positions and orientations; READY uses the validated 68-pixel orbit and a single counterclockwise 90-degree orientation offset. Rendering remains time-based and moves to a 16 ms target interval.

**Tech Stack:** Python 3, Pillow, pytest, C11, CMake/NMake, Raspberry Pi Pico SDK, ST7789 SPI/DMA.

---

### Task 1: Lock the exact reference asset contract

**Files:**
- Modify: `tools/test_blossom_asset.py`
- Modify: `tools/generate_blossom_asset.py`
- Reference: `assets/reference-petal-exact.png`

**Step 1: Write the failing tests**

Add tests that require the generated canonical petal to equal the thresholded/cropped black reference, require six emitted masks to be byte-identical, and reject the old SVG-hole expansion path.

**Step 2: Run the tests to verify they fail**

Run: `python -m pytest tools/test_blossom_asset.py -q`

Expected: FAIL because `rasterize_petals()` still derives six rings from SVG holes.

**Step 3: Implement the minimal generator**

Add `rasterize_reference_petal()` that loads the PNG, thresholds black foreground, crops once, scales once into the 128x128 canonical canvas, quantizes to 4bpp, and returns six independent copies of the same bytes. Add `--petal` to the CLI and make it the default source for piece masks.

**Step 4: Run the tests to verify they pass**

Run: `python -m pytest tools/test_blossom_asset.py tools/test_petal_preview_geometry.py -q`

Expected: all tests pass.

**Step 5: Regenerate the C asset**

Run: `python tools/generate_blossom_asset.py`

Expected: `Core/Inc/blossom_asset.h` and `Core/Src/blossom_asset.c` update atomically.

### Task 2: Encode the approved READY geometry and transitions

**Files:**
- Modify: `ports/rp2040-zero/tests/test_pager_core.c`
- Modify: `ports/rp2040-zero/firmware/src/blossom_motion.c`
- Modify if required: `ports/rp2040-zero/firmware/include/blossom_motion.h`

**Step 1: Write the failing motion tests**

Require READY piece centers to lie on a 67-68 pixel orbit, all pieces to keep `FULL_SCALE_Q12`, the base orientation to be exactly counterclockwise 90 degrees plus the common orbit phase, and the first READY-to-RUNNING frame to start both gathering and green-to-purple interpolation.

**Step 2: Run host tests to verify they fail**

Run: `powershell -ExecutionPolicy Bypass -File tools/run_host_tests.ps1`

Expected: FAIL on the old 20-pixel READY radius and old color transition.

**Step 3: Implement the minimal motion changes**

Set the approved orbit radius, apply one 90-degree counterclockwise orientation offset, retain one shared scale, and interpolate color and position on the same transition timeline. Keep RUNNING continuous and faster than READY.

**Step 4: Run host tests**

Run: `powershell -ExecutionPolicy Bypass -File tools/run_host_tests.ps1`

Expected: `pager core tests passed`.

### Task 3: Raise the frame target and keep bounded rendering

**Files:**
- Modify: `ports/rp2040-zero/tests/test_pager_core.c`
- Modify: `ports/rp2040-zero/firmware/include/display_scene.h`
- Modify if required: `ports/rp2040-zero/firmware/src/display_scene.c`
- Modify if required: `ports/rp2040-zero/src/main.cpp`

**Step 1: Write the failing timing test**

Require `PAGER_SCENE_FRAME_MS == 16U` and verify every piece clip remains inside the 240x240 scene for a full READY orbit.

**Step 2: Run host tests to verify failure**

Run: `powershell -ExecutionPolicy Bypass -File tools/run_host_tests.ps1`

Expected: FAIL while the frame target remains 25 ms.

**Step 3: Implement the minimal scheduler/render change**

Change the target interval to 16 ms, preserve time-based sampling, and keep the generated rotation-safe clip bounds. Do not add full-frame per-pixel work to READY.

**Step 4: Run all focused tests**

Run: `python -m pytest tools/test_blossom_asset.py tools/test_petal_preview_geometry.py tools/test_rp2040_display_ui.py -q`

Run: `powershell -ExecutionPolicy Bypass -File tools/run_host_tests.ps1`

Expected: all tests pass.

### Task 4: Build and flash

**Files:**
- Verify: `tools/build_rp2040.ps1`
- Output: `build-rp2040/codex_usb_pager_rp2040.uf2`

**Step 1: Build with the ASCII staging script**

Run: `powershell -ExecutionPolicy Bypass -File tools/build_rp2040.ps1`

Expected: the UF2 is generated without a lingering compiler or PDB process.

**Step 2: Verify the artifact**

Check the UF2 exists, has nonzero size, and has a fresh timestamp.

**Step 3: Detect BOOTSEL**

Check mounted volumes for `RPI-RP2`. If present, copy the UF2 directly. If absent, ask the user to enter BOOTSEL once.

**Step 4: Verify flashing completed**

Confirm the `RPI-RP2` volume disappears after the copy and report the exact UF2 path, test results, and any local environment issue with a repair recommendation.

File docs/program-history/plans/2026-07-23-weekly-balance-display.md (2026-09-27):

# Weekly Balance Display Implementation Plan

> **For agentic workers:** REQUIRED SUB-SKILL: Use superpowers:subagent-driven-development (recommended) or superpowers:executing-plans to implement this plan task-by-task. Steps use checkbox (`- [ ]`) syntax for tracking.

**Goal:** Automatically read the remaining Codex seven-day allowance and show it only on the RP2040 pager's idle screen.

**Architecture:** A focused host-side watcher extracts the newest `10080`-minute rate-limit event and persists the remaining integer percentage in the existing SQLite runtime store. The unchanged `BAL` protocol field carries that value to firmware, where a fixed bitmap font is composed into the existing double-buffered scene only for `PAGER_IDLE`.

**Tech Stack:** Python 3, JSONL, SQLite, pytest, C11, Pico SDK, CMake/CTest, RP2040 PIO SPI, ST7789.

## Global Constraints

- Use only `rate_limits.primary` records whose `window_minutes` is exactly `10080`.
- Calculate remaining allowance as `clamp(100 - used_percent, 0, 100)`.
- Keep the existing `STATE ... BAL=<token> ...` wire format.
- Show weekly allowance only in `PAGER_IDLE`.
- Preserve every non-idle scene's existing appearance, motion, and target frame interval.
- Use fixed storage only: no heap allocation, extra frame buffer, or floating-point rendering.
- Show no percentage when no valid current or cached weekly value exists.

---

## File Structure

- Create `tools/weekly_balance.py`: parse rate-limit events and incrementally watch session JSONL files.
- Create `tools/test_weekly_balance.py`: host extraction, precedence, malformed-input, and incremental-read tests.
- Modify `tools/pager_runtime.py`: persist and retrieve the last valid weekly percentage.
- Modify `tools/pager_daemon.py`: poll the weekly watcher and send changed balances immediately.
- Modify `tools/test_pager_runtime.py`: verify cached balance propagation into snapshots.
- Create `ports/rp2040-zero/firmware/include/tiny_font.h`: fixed glyph rendering interface.
- Create `ports/rp2040-zero/firmware/src/tiny_font.c`: glyphs for `WEEK`, digits, and `%`.
- Modify `ports/rp2040-zero/firmware/CMakeLists.txt`: compile the font source.
- Modify `ports/rp2040-zero/firmware/include/display_scene.h`: add balance-aware scene interfaces and an idle layout description.
- Modify `ports/rp2040-zero/firmware/src/display_scene.c`: render the idle label/value and move only the idle Blossom upward.
- Modify `ports/rp2040-zero/firmware/include/display_ui.h`: accept balance updates.
- Modify `ports/rp2040-zero/firmware/src/display_ui.c`: retain the latest balance and invalidate the frame when it changes.
- Modify `ports/rp2040-zero/firmware/src/main.c`: pass parsed `snapshot.balance` to the display.
- Modify `ports/rp2040-zero/tests/test_pager_core.c`: test parsing, idle text layout, and non-idle isolation.
- Modify `ports/rp2040-zero/tests/CMakeLists.txt`: compile the font in host tests.

---

### Task 1: Extract Weekly Remaining Allowance

**Files:**
- Create: `codex_usb_pager/tools/weekly_balance.py`
- Create: `codex_usb_pager/tools/test_weekly_balance.py`

**Interfaces:**
- Produces: `parse_weekly_remaining(event: object) -> int | None`
- Produces: `WeeklyBalanceWatcher(root: Path).poll() -> int | None`

- [ ] **Step 1: Write failing parser and watcher tests**

```python
def token_event(used: object, minutes: object = 10080) -> dict:
    return {
        "timestamp": "2026-07-23T13:43:21.210Z",
        "type": "event_msg",
        "payload": {
            "type": "token_count",
            "rate_limits": {
                "primary": {
                    "used_percent": used,
                    "window_minutes": minutes,
                }
            },
        },
    }

def test_converts_weekly_used_to_remaining() -> None:
    assert parse_weekly_remaining(token_event(12.0)) == 88
    assert parse_weekly_remaining(token_event(0)) == 100
    assert parse_weekly_remaining(token_event(100)) == 0

def test_rejects_non_weekly_and_malformed_records() -> None:
    assert parse_weekly_remaining(token_event(12, 300)) is None
    assert parse_weekly_remaining(token_event("12")) is None
    assert parse_weekly_remaining({"type": "event_msg", "payload": {}}) is None

def test_watcher_reads_only_new_complete_lines(tmp_path: Path) -> None:
    path = tmp_path / "rollout.jsonl"
    path.write_text(json.dumps(token_event(10)) + "\n", encoding="utf-8")
    watcher = WeeklyBalanceWatcher(tmp_path)
    assert watcher.poll() == 90

    with path.open("a", encoding="utf-8") as handle:
        handle.write(json.dumps(token_event(12)) + "\n")
    assert watcher.poll() == 88
    assert watcher.poll() is None
```

- [ ] **Step 2: Run the focused test and verify failure**

Run: `python -m pytest tools/test_weekly_balance.py -q`

Expected: collection fails because `weekly_balance` does not exist.

- [ ] **Step 3: Implement strict parsing and incremental offsets**

```python
def parse_weekly_remaining(event: object) -> int | None:
    if not isinstance(event, dict) or event.get("type") != "event_msg":
        return None
    payload = event.get("payload")
    if not isinstance(payload, dict) or payload.get("type") != "token_count":
        return None
    limits = payload.get("rate_limits")
    primary = limits.get("primary") if isinstance(limits, dict) else None
    if not isinstance(primary, dict) or primary.get("window_minutes") != 10080:
        return None
    used = primary.get("used_percent")
    if not isinstance(used, (int, float)) or isinstance(used, bool):
        return None
    return max(0, min(100, 100 - int(round(used))))
```

`WeeklyBalanceWatcher` must retain one byte offset per path, parse only
newline-terminated UTF-8 JSON records, recover when a file shrinks, and return
only the newest valid percentage observed during that poll. Its first poll
reads existing records so a fresh installation can bootstrap without waiting
for another Codex response.

- [ ] **Step 4: Run focused tests**

Run: `python -m pytest tools/test_weekly_balance.py -q`

Expected: all weekly-balance tests pass.

- [ ] **Step 5: Commit**

```powershell
git add -- codex_usb_pager/tools/weekly_balance.py codex_usb_pager/tools/test_weekly_balance.py
git commit -m "feat: read Codex weekly allowance"
```

### Task 2: Cache and Transmit Weekly Balance

**Files:**
- Modify: `codex_usb_pager/tools/pager_runtime.py`
- Modify: `codex_usb_pager/tools/pager_daemon.py`
- Modify: `codex_usb_pager/tools/test_pager_runtime.py`

**Interfaces:**
- Consumes: `WeeklyBalanceWatcher.poll() -> int | None`
- Produces: `RuntimeStore.set_weekly_balance(percent: int) -> None`
- Produces: `RuntimeStore.weekly_balance() -> str`

- [ ] **Step 1: Add failing persistence and daemon tests**

```python
def test_weekly_balance_is_cached_and_added_to_snapshot(tmp_path: Path) -> None:
    path = tmp_path / "runtime.sqlite"
    first = RuntimeStore(path)
    assert first.snapshot(now=100).balance == "NA"
    first.set_weekly_balance(88)

    restarted = RuntimeStore(path)
    assert restarted.weekly_balance() == "88"
    assert restarted.snapshot(now=101).balance == "88"

def test_daemon_sends_immediately_when_balance_changes(tmp_path: Path) -> None:
    store = RuntimeStore(tmp_path / "runtime.sqlite")
    sent = []
    snapshot = process_balance_update(
        store, watcher=lambda: 88, sender=sent.append, now=100
    )
    assert snapshot is not None
    assert snapshot.balance == "88"
    assert sent == [snapshot]
```

- [ ] **Step 2: Verify focused failures**

Run: `python -m pytest tools/test_pager_runtime.py -q`

Expected: failures report missing `set_weekly_balance`,
`weekly_balance`, and `process_balance_update`.

- [ ] **Step 3: Add SQLite metadata and daemon integration**

Add a `weekly_balance` row to the existing integer `meta` table with sentinel
`-1`. `set_weekly_balance` accepts only `0..100`. `weekly_balance` returns
`"NA"` for the sentinel and a decimal string otherwise. When `snapshot` is
called without an explicit `balance`, it reads this cached value.

```python
def process_balance_update(store, watcher, sender, now=None):
    remaining = watcher() if callable(watcher) else watcher.poll()
    if remaining is None:
        return None
    store.set_weekly_balance(remaining)
    return run_cycle(store, sender, now=now)
```

Construct `WeeklyBalanceWatcher(Path.home() / ".codex" / "sessions")` beside
the existing session watcher. Poll it every daemon loop before the periodic
heartbeat; when it yields a value, call `process_balance_update` and advance
the next heartbeat deadline.

- [ ] **Step 4: Run all host tests**

Run: `python -m pytest tools -q`

Expected: all host tests pass, including cached restoration and `BAL=88`.

- [ ] **Step 5: Commit**

```powershell
git add -- codex_usb_pager/tools/pager_runtime.py codex_usb_pager/tools/pager_daemon.py codex_usb_pager/tools/test_pager_runtime.py
git commit -m "feat: cache and transmit weekly balance"
```

### Task 3: Render Weekly Balance Only in Idle

**Files:**
- Create: `codex_usb_pager/ports/rp2040-zero/firmware/include/tiny_font.h`
- Create: `codex_usb_pager/ports/rp2040-zero/firmware/src/tiny_font.c`
- Modify: `codex_usb_pager/ports/rp2040-zero/firmware/CMakeLists.txt`
- Modify: `codex_usb_pager/ports/rp2040-zero/firmware/include/display_scene.h`
- Modify: `codex_usb_pager/ports/rp2040-zero/firmware/src/display_scene.c`
- Modify: `codex_usb_pager/ports/rp2040-zero/firmware/include/display_ui.h`
- Modify: `codex_usb_pager/ports/rp2040-zero/firmware/src/display_ui.c`
- Modify: `codex_usb_pager/ports/rp2040-zero/firmware/src/main.c`
- Modify: `codex_usb_pager/ports/rp2040-zero/tests/CMakeLists.txt`
- Modify: `codex_usb_pager/ports/rp2040-zero/tests/test_pager_core.c`

**Interfaces:**
- Produces: `bool tiny_font_sample(char glyph, uint8_t x, uint8_t y)`
- Produces: `bool pager_scene_idle_text_pixel(const char *balance, int16_t x, int16_t y, uint16_t *color)`
- Produces: `void pager_display_ui_set_snapshot(pager_state_t state, const char *balance, uint32_t now_ms)`

- [ ] **Step 1: Add failing firmware tests**

```c
static void test_balance_parser_boundaries(void) {
    pager_snapshot_t snapshot;
    assert(pager_parse_line(
        "STATE IDLE RUN=0 WAIT=0 DONE=0 BAL=0 EV=NONE", &snapshot));
    assert(strcmp(snapshot.balance, "0") == 0);
    assert(pager_parse_line(
        "STATE IDLE RUN=0 WAIT=0 DONE=0 BAL=100 EV=NONE", &snapshot));
    assert(strcmp(snapshot.balance, "100") == 0);
}

static void test_idle_balance_layout_is_centered(void) {
    pager_idle_layout_t one = pager_scene_idle_layout("8");
    pager_idle_layout_t two = pager_scene_idle_layout("88");
    pager_idle_layout_t three = pager_scene_idle_layout("100");
    assert(one.value_center_x == PAGER_SCENE_CENTER_X);
    assert(two.value_center_x == PAGER_SCENE_CENTER_X);
    assert(three.value_center_x == PAGER_SCENE_CENTER_X);
    assert(three.value_left >= PAGER_SCENE_REGION_X);
    assert(three.value_right <
           PAGER_SCENE_REGION_X + PAGER_SCENE_REGION_SIZE);
}

static void test_non_idle_scene_ignores_balance(void) {
    uint16_t without_balance[PAGER_SCENE_REGION_SIZE];
    uint16_t with_balance[PAGER_SCENE_REGION_SIZE];
    pager_scene_render_row(PAGER_RUNNING, 500U, "NA", 160, without_balance);
    pager_scene_render_row(PAGER_RUNNING, 500U, "88", 160, with_balance);
    assert(memcmp(without_balance, with_balance, sizeof(with_balance)) == 0);
}
```

- [ ] **Step 2: Run C tests and verify failure**

Run:

```powershell
cmake -S ports/rp2040-zero/tests -B build-rp2040-host
cmake --build build-rp2040-host --config Release
ctest --test-dir build-rp2040-host -C Release --output-on-failure
```

Expected: compilation fails because the idle layout and balance-aware render
interfaces are not defined.

- [ ] **Step 3: Implement the fixed bitmap font**

Define five-column, seven-row glyphs for `W`, `E`, `K`, digits `0..9`, and
`%`. `tiny_font_sample` returns false for unsupported glyphs and out-of-range
coordinates. Store glyph rows as compile-time constants; do not allocate or
scale buffers.

- [ ] **Step 4: Implement the idle composition**

Add a `pager_idle_layout_t` containing integer bounds and centers. For known
balances `0..100`, render:

- a smaller Blossom centered above the text;
- `WEEK` at 2x bitmap scale;
- `<balance>%` at 4x bitmap scale;
- neutral `WEEK` color and blue-purple percentage color.

For `NA` or malformed balance text, render the existing idle Blossom with no
text. Pass the balance through each row renderer. Text sampling occurs only
inside the `PAGER_IDLE` branch and only within the text bounds.

`pager_display_ui_set_snapshot` updates the state and a fixed
`char balance[PAGER_BALANCE_CAPACITY]`. It starts the existing state
cross-fade when the state changes; a same-state balance change invalidates
the next frame without starting a transition. `main.c` calls it after every
valid parsed snapshot.

- [ ] **Step 5: Run host C tests**

Run:

```powershell
cmake --build build-rp2040-host --config Release
ctest --test-dir build-rp2040-host -C Release --output-on-failure
```

Expected: `pager_core_tests` passes.

- [ ] **Step 6: Run Python regression tests**

Run: `python -m pytest tools -q`

Expected: all Python tests pass.

- [ ] **Step 7: Commit**

```powershell
git add -- codex_usb_pager/ports/rp2040-zero/firmware codex_usb_pager/ports/rp2040-zero/tests
git commit -m "feat: show weekly balance when idle"
```

### Task 4: Build, Flash, and Live-Verify

**Files:**
- Modify only if verification reveals a scoped defect in files from Tasks 1-3.

**Interfaces:**
- Consumes: RP2040 UF2 firmware and the host daemon's `BAL=<remaining>` snapshot.
- Produces: a physically verified idle weekly balance display.

- [ ] **Step 1: Run the complete host suite**

Run: `python -m pytest tools -q`

Expected: all tests pass.

- [ ] **Step 2: Run the complete C host suite**

Run:

```powershell
cmake --build build-rp2040-host --config Release
ctest --test-dir build-rp2040-host -C Release --output-on-failure
```

Expected: all tests pass.

- [ ] **Step 3: Build RP2040 firmware**

Run:

```powershell
powershell -ExecutionPolicy Bypass -File tools/build_rp2040.ps1
```

Expected: the build emits `codex_pager_rp2040.uf2` and reports flash/SRAM
usage within RP2040 limits.

- [ ] **Step 4: Verify the live host value before flashing**

Run the watcher once against `%USERPROFILE%\.codex\sessions` and print the
newest value.

Expected on the current account: `88`.

- [ ] **Step 5: Flash the mounted RP2040 boot volume**

Copy the verified UF2 to the detected `RPI-RP2` volume. Wait for the volume to
disconnect and for the CDC serial device to reappear.

- [ ] **Step 6: Restart the pager daemon**

Stop only the existing `pager_daemon.py` process and start the daemon from
`C:\Users\28026\Documents\saltyfish\codex_usb_pager\tools`.

- [ ] **Step 7: Verify hardware behavior**

Confirm:

- idle shows `WEEK` and the same remaining percentage as the watcher;
- submitting a Codex task fades the weekly text out and starts the existing
  running animation;
- finishing the task returns through the existing done transition and then
  fades the weekly text back in;
- running animation frame rate and color match the pre-change firmware.

- [ ] **Step 8: Report local environment issues**

Report build locks, stale daemon processes, serial reconnect delays, missing
rate-limit records, or boot-volume behavior encountered during the run, and
state whether each issue should be fixed.

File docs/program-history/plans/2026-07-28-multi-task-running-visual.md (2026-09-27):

# Multi-Task Running Visual Implementation Plan

> **For agentic workers:** REQUIRED SUB-SKILL: Use superpowers:subagent-driven-development (recommended) or superpowers:executing-plans to implement this plan task-by-task. Steps use checkbox (`- [ ]`) syntax for tracking.

**Goal:** Preserve the existing smooth foreground RUNNING Blossom while showing one complete blurred background Blossom for each additional active Codex task, capped at three ghosts.

**Architecture:** Keep `PAGER_MULTI` as the existing priority-selected semantic state, but propagate `pager_snapshot_t.running` into `display_ui`. Store ghost-count transitions independently from `pager_blossom_motion_t` so RUNNING-to-MULTI changes never restart the foreground phase. Extend the prepared full-mask renderer with up to three complete Blossom ghost layers and render those layers with a low-cost 2 x 2 sampling path.

**Tech Stack:** RP2040 Pico SDK C, ST7789 RGB565 renderer, 4-bpp Blossom masks, CMake/CTest host tests, PowerShell UF2 build and Windows RPI-RP2 flashing.

## Global Constraints

- The foreground uses the canonical complete `g_blossom_alpha_4bpp` mask.
- No multi-task path may use `g_blossom_piece_alpha_4bpp`.
- Additional tasks map to `min(running_count - 1, 3)` background ghosts.
- The foreground keeps the existing RUNNING purple, centered rotation, acceleration, and scale pulse.
- Ghosts use deep blue, blue-violet, and cyan-violet in decreasing opacity.
- Ghost direction alternates counter-clockwise, clockwise, counter-clockwise.
- Ghost periods are 5.6 s, 4.8 s, and 6.4 s.
- Ghost scales are 1.08, 1.16, and 1.24 times the foreground scale.
- Ghost base opacities are 30%, 23%, and 17%.
- Ghost-count fades last 320 ms.
- The display frame interval remains 16 ms.
- The white full-screen hex outline remains unchanged.
- GP14 drives the active-low buzzer: HIGH is silent and LOW is active.
- Boot, WAIT, DONE, and ERROR map to 1, 3, 1, and 5 non-blocking pulses.
- Each pulse is 25 ms with 180 ms silent spacing; RUNNING and MULTI are silent.
- WAIT, DONE, ERROR, OFFLINE, balance, USB parsing, and priority behavior remain unchanged.

---

### Task 1: Preserve Running Count Through the Display Boundary

**Files:**
- Modify: `ports/rp2040-zero/firmware/include/display_ui.h`
- Modify: `ports/rp2040-zero/firmware/src/display_ui.c`
- Modify: `ports/rp2040-zero/firmware/include/display_scene.h`
- Modify: `ports/rp2040-zero/firmware/src/display_scene.c`
- Modify: `ports/rp2040-zero/firmware/src/main.c`
- Modify: `ports/rp2040-zero/tests/test_pager_core.c`
- Test: `tools/test_rp2040_display_ui.py`

**Interfaces:**
- Consumes: `pager_snapshot_t.running` from `pager_core.h`.
- Produces: `pager_display_ui_set_snapshot(pager_state_t state, uint32_t running_count, const char *balance, uint32_t now_ms)`.
- Produces: `pager_scene_ghost_count(pager_state_t state, uint32_t running_count) -> uint8_t` for host-testable count mapping.

- [ ] **Step 1: Add failing count-mapping and source-contract tests**

Add to `ports/rp2040-zero/tests/test_pager_core.c`:

```c
static void test_display_ghost_count_caps_additional_tasks(void) {
    assert(pager_scene_ghost_count(PAGER_RUNNING, 1U) == 0U);
    assert(pager_scene_ghost_count(PAGER_MULTI, 2U) == 1U);
    assert(pager_scene_ghost_count(PAGER_MULTI, 3U) == 2U);
    assert(pager_scene_ghost_count(PAGER_MULTI, 4U) == 3U);
    assert(pager_scene_ghost_count(PAGER_MULTI, 99U) == 3U);
    assert(pager_scene_ghost_count(PAGER_WAIT, 3U) == 0U);
}
```

Register it in the existing `main()` test list.

Add to `tools/test_rp2040_display_ui.py`:

```python
MAIN_SOURCE = (
    ROOT / "ports/rp2040-zero/firmware/src/main.c"
).read_text(encoding="ascii")
UI_HEADER = (
    ROOT / "ports/rp2040-zero/firmware/include/display_ui.h"
).read_text(encoding="ascii")

def test_main_forwards_running_count_to_display_snapshot():
    assert "state, snapshot.running, snapshot.balance, current_ms" in MAIN_SOURCE

def test_snapshot_api_accepts_running_count():
    assert "pager_state_t state, uint32_t running_count," in UI_HEADER
```

- [ ] **Step 2: Run the focused tests and verify failure**

Run:

```powershell
python -m pytest tools/test_rp2040_display_ui.py -q
cmake --build build-rp2040-host
ctest --test-dir build-rp2040-host --output-on-failure
```

Expected: Python source-contract tests fail because the API has no count, and the C test fails to compile because `pager_scene_ghost_count` is undefined.

- [ ] **Step 3: Implement count propagation and capped mapping**

Declare in `display_ui.h`:

```c
void pager_display_ui_set_snapshot(
    pager_state_t state,
    uint32_t running_count,
    const char *balance,
    uint32_t now_ms);
```

Declare in `display_scene.h` and implement in `display_scene.c`:

```c
uint8_t pager_scene_ghost_count(
    pager_state_t state, uint32_t running_count) {
    uint32_t additional;

    if (state != PAGER_MULTI || running_count < 2U) {
        return 0U;
    }
    additional = running_count - 1U;
    return (uint8_t)(additional > 3U ? 3U : additional);
}
```

Use `pager_scene_ghost_count` from `display_ui.c`, store the latest count, and
pass it from `main.c`:

```c
pager_display_ui_set_snapshot(
    state, snapshot.running, snapshot.balance, current_ms);
```

Keep `pager_display_ui_set_state` forwarding the stored count so timeout and legacy callers retain a valid API path.

- [ ] **Step 4: Run focused tests and verify success**

Run the same commands from Step 2.

Expected: all focused Python and C host tests pass.

- [ ] **Step 5: Commit the count boundary**

```powershell
git add ports/rp2040-zero/firmware/include/display_ui.h ports/rp2040-zero/firmware/src/display_ui.c ports/rp2040-zero/firmware/include/display_scene.h ports/rp2040-zero/firmware/src/display_scene.c ports/rp2040-zero/firmware/src/main.c ports/rp2040-zero/tests/test_pager_core.c tools/test_rp2040_display_ui.py
git commit -m "feat: retain running task count in display ui"
```

---

### Task 2: Define Complete Blossom Ghost Layers

**Files:**
- Modify: `ports/rp2040-zero/firmware/include/display_scene.h`
- Modify: `ports/rp2040-zero/firmware/src/display_scene.c`
- Modify: `ports/rp2040-zero/tests/test_pager_core.c`
- Test: `tools/test_rp2040_display_ui.py`

**Interfaces:**
- Consumes: foreground `pager_blossom_model_t`, `ghost_count`, and per-ghost opacity values from `display_ui`.
- Produces: `pager_scene_prepare_render_context(..., uint8_t ghost_count, const uint8_t ghost_opacity[3], uint32_t motion_ms, ...)`.
- Produces: `pager_scene_render_context_t.ghosts[3]` and `.ghost_count`.

- [ ] **Step 1: Add failing context tests for full-mask ghosts**

Add to `ports/rp2040-zero/tests/test_pager_core.c`:

```c
#include "blossom_asset.h"

static void test_multi_context_builds_complete_blossom_ghosts(void) {
    pager_blossom_motion_t motion;
    pager_blossom_model_t model;
    pager_scene_render_context_t context;
    const uint8_t opacity[3] = {77U, 59U, 43U};

    pager_blossom_motion_init(&motion, PAGER_RUNNING, 0U);
    pager_blossom_motion_sample(&motion, 1200U, &model);
    pager_scene_prepare_render_context(
        &model, "NA", 3U, opacity, 1200U, &context);

    assert(context.ghost_count == 3U);
    assert(context.ghosts[0].mask_4bpp == g_blossom_alpha_4bpp);
    assert(context.ghosts[1].mask_4bpp == g_blossom_alpha_4bpp);
    assert(context.ghosts[2].mask_4bpp == g_blossom_alpha_4bpp);
    assert(!context.petals_visible);
    assert(context.ghosts[0].opacity > context.ghosts[1].opacity);
    assert(context.ghosts[1].opacity > context.ghosts[2].opacity);
}
```

Add source guards to `tools/test_rp2040_display_ui.py`:

```python
def test_multi_ghosts_use_complete_blossom_masks():
    assert "ghosts[PAGER_MULTI_GHOST_MAX]" in SCENE_HEADER
    assert "g_blossom_alpha_4bpp" in SCENE_SOURCE
    assert "context->ghosts" in SCENE_SOURCE

def test_multi_ghost_palette_has_no_yellow_or_ready_petals():
    ghost_helper = SCENE_SOURCE.split(
        "static void prepare_multi_ghosts", 1
    )[1].split("void pager_scene_prepare_render_context", 1)[0]
    assert "PAGER_BLOSSOM_WAIT_COLOR" not in ghost_helper
    assert "g_blossom_piece_alpha_4bpp" not in ghost_helper
```

- [ ] **Step 2: Run focused tests and verify failure**

Run:

```powershell
python -m pytest tools/test_rp2040_display_ui.py -q
cmake --build build-rp2040-host
ctest --test-dir build-rp2040-host --output-on-failure
```

Expected: context signature and ghost fields are missing.

- [ ] **Step 3: Add prepared ghost-layer fields and constants**

Add to `display_scene.h`:

```c
#define PAGER_MULTI_GHOST_MAX 3U
#define PAGER_MULTI_GHOST_FADE_MS 320U

typedef struct {
    pager_scene_prepared_layer_t pieces[BLOSSOM_PIECE_COUNT];
    pager_scene_prepared_layer_t full;
    pager_scene_prepared_layer_t ghosts[PAGER_MULTI_GHOST_MAX];
    char value_text[5];
    uint8_t value_length;
    uint8_t balance_opacity;
    int16_t value_left;
    int16_t value_top;
    uint8_t ghost_count;
    bool petals_visible;
    bool full_visible;
} pager_scene_render_context_t;
```

In `display_scene.c`, define fixed ghost colors and motion:

```c
static const uint16_t ghost_period_ms[PAGER_MULTI_GHOST_MAX] =
    {5600U, 4800U, 6400U};
static const uint16_t ghost_scale_ratio_q12[PAGER_MULTI_GHOST_MAX] =
    {4424U, 4751U, 5079U};
static const uint8_t ghost_base_opacity[PAGER_MULTI_GHOST_MAX] =
    {77U, 59U, 43U};
```

Use `pager_scene_rgb565(64, 92, 238)`,
`pager_scene_rgb565(112, 86, 244)`, and
`pager_scene_rgb565(76, 180, 224)` for the three layers.

Prepare every ghost with `make_mask_layer_at`, center
`PAGER_SCENE_CENTER_X/Y`, and `g_blossom_alpha_4bpp`. Compute angle directly
from `motion_ms`; negate the first and third angles to alternate direction.
Compute each output scale from the current foreground scale:

```c
const uint16_t ghost_scale = (uint16_t)(
    ((uint32_t)model->pieces[0].scale_q12 *
     ghost_scale_ratio_q12[index] + 2048U) >> 12U);
```

Update every existing `pager_scene_prepare_render_context` call site. Pass zero
ghost count and zero opacity for non-MULTI callers so all existing state
rendering remains unchanged.

- [ ] **Step 4: Run focused tests and verify success**

Run the commands from Step 2.

Expected: complete-mask context tests pass and existing rendering tests remain green.

- [ ] **Step 5: Commit complete ghost-layer preparation**

```powershell
git add ports/rp2040-zero/firmware/include/display_scene.h ports/rp2040-zero/firmware/src/display_scene.c ports/rp2040-zero/tests/test_pager_core.c tools/test_rp2040_display_ui.py
git commit -m "feat: prepare complete Blossom multi-task ghosts"
```

---

### Task 3: Add Independent Ghost Fades Without Restarting Foreground Motion

**Files:**
- Modify: `ports/rp2040-zero/firmware/src/display_ui.c`
- Modify: `ports/rp2040-zero/firmware/src/display_scene.c`
- Modify: `ports/rp2040-zero/firmware/include/display_scene.h`
- Modify: `ports/rp2040-zero/tests/test_pager_core.c`
- Test: `tools/test_rp2040_display_ui.py`

**Interfaces:**
- Consumes: capped ghost count from Task 1 and prepared layers from Task 2.
- Produces: `pager_scene_ghost_opacity(uint8_t from_count, uint8_t to_count, uint32_t elapsed_ms, uint8_t output[3])`.
- Preserves: `pager_blossom_motion_t` target and phase when only RUNNING/MULTI classification changes.

- [ ] **Step 1: Add failing fade and phase-continuity tests**

Add host-testable fade assertions:

```c
static void test_ghost_count_transition_fades_only_changed_layers(void) {
    uint8_t opacity[3];

    pager_scene_ghost_opacity(1U, 3U, 0U, opacity);
    assert(opacity[0] == 255U);
    assert(opacity[1] == 0U);
    assert(opacity[2] == 0U);

    pager_scene_ghost_opacity(1U, 3U, 160U, opacity);
    assert(opacity[0] == 255U);
    assert(opacity[1] > 0U && opacity[1] < 255U);
    assert(opacity[2] > 0U && opacity[2] < 255U);

    pager_scene_ghost_opacity(1U, 3U, 320U, opacity);
    assert(opacity[0] == 255U);
    assert(opacity[1] == 255U);
    assert(opacity[2] == 255U);
}
```

Add a source-contract test:

```python
def test_running_multi_switch_does_not_retarget_foreground_motion():
    assert "running_family_change" in UI_SOURCE
    assert "if (!running_family_change)" in UI_SOURCE
```

- [ ] **Step 2: Run tests and verify failure**

Run:

```powershell
python -m pytest tools/test_rp2040_display_ui.py -q
cmake --build build-rp2040-host
ctest --test-dir build-rp2040-host --output-on-failure
```

Expected: fade helper and running-family guard are absent.

- [ ] **Step 3: Implement independent ghost transition state**

Add to `display_ui.c`:

```c
static uint8_t ghost_from_count;
static uint8_t ghost_to_count;
static uint32_t ghost_transition_started_ms;

static bool is_running_family(pager_state_t state) {
    return state == PAGER_RUNNING || state == PAGER_MULTI;
}
```

Declare in `display_scene.h` and implement
`pager_scene_ghost_opacity` in `display_scene.c` with smoothstep progress:

```c
void pager_scene_ghost_opacity(
    uint8_t from_count,
    uint8_t to_count,
    uint32_t elapsed_ms,
    uint8_t output[PAGER_MULTI_GHOST_MAX]) {
    const uint32_t t = elapsed_ms >= PAGER_MULTI_GHOST_FADE_MS
        ? 32768U
        : (elapsed_ms * 32768U) / PAGER_MULTI_GHOST_FADE_MS;
    const uint32_t smooth =
        (t * t >> 15U) * (3U * 32768U - 2U * t) >> 15U;
    uint8_t index;

    for (index = 0U; index < PAGER_MULTI_GHOST_MAX; ++index) {
        const bool was_visible = index < from_count;
        const bool is_visible = index < to_count;
        output[index] = was_visible == is_visible
            ? (was_visible ? 255U : 0U)
            : (is_visible
                ? (uint8_t)((smooth * 255U + 16384U) >> 15U)
                : (uint8_t)(255U -
                    ((smooth * 255U + 16384U) >> 15U)));
    }
}
```

When a snapshot changes ghost count, snapshot the current effective visibility,
set the new target, record `now_ms`, and force the next frame.

When switching only between `PAGER_RUNNING` and `PAGER_MULTI`, update
`current_state` but do not call `pager_blossom_motion_set_target`. Other state
changes retain the existing transition call.

- [ ] **Step 4: Render ghosts with true 2 x 2 sampling**

Add `pager_scene_render_prepared_row_pair` to `display_scene.h/.c`. It accepts
two destination rows for adjacent screen rows:

```c
void pager_scene_render_prepared_row_pair(
    pager_state_t state,
    uint32_t elapsed_ms,
    const pager_scene_render_context_t *context,
    int16_t x_start,
    int16_t y,
    uint16_t pixel_count,
    uint16_t *top_pixels,
    uint16_t *bottom_pixels);
```

For each ghost and each even horizontal offset:

1. sample the ghost mask once at `(x, y)`;
2. reuse that alpha for `(x + 1, y)`, `(x, y + 1)`, and
   `(x + 1, y + 1)`;
3. blend ghosts in back-to-front order;
4. sample and blend the foreground separately at all four pixels.

Change `render_scene` in `display_ui.c` to advance by two rows and call this
pair renderer. When either the current or previously rendered state is MULTI,
select the full-frame/delta transport branch so MULTI never enters the
piece-oriented dirty-tile path. Non-MULTI dirty-tile rendering remains
unchanged.

Add this source-contract test to `tools/test_rp2040_display_ui.py`:

```python
def test_multi_ghosts_are_sampled_once_per_two_by_two_block():
    pair = SCENE_SOURCE.split(
        "void pager_scene_render_prepared_row_pair", 1
    )[1].split("void pager_scene_render_motion_span", 1)[0]
    assert "pixel += 2U" in pair
    assert "top_pixels[pixel + 1U]" in pair
    assert "bottom_pixels[pixel]" in pair
    assert "bottom_pixels[pixel + 1U]" in pair
```

- [ ] **Step 5: Run focused and full host tests**

Run:

```powershell
python -m pytest tools -q
cmake --build build-rp2040-host
ctest --test-dir build-rp2040-host --output-on-failure
```

Expected: all tests pass; no legacy MULTI READY-petal path is selected.

- [ ] **Step 6: Commit motion continuity and rendering**

```powershell
git add ports/rp2040-zero/firmware/src/display_ui.c ports/rp2040-zero/firmware/src/display_scene.c ports/rp2040-zero/firmware/include/display_scene.h ports/rp2040-zero/tests/test_pager_core.c tools/test_rp2040_display_ui.py
git commit -m "feat: animate multi-task Blossom ghost layers"
```

---

### Task 4: Add the Active-Low Non-Blocking Buzzer

**Files:**
- Create: `ports/rp2040-zero/firmware/include/buzzer.h`
- Create: `ports/rp2040-zero/firmware/src/buzzer.c`
- Modify: `ports/rp2040-zero/firmware/src/main.c`
- Modify: `ports/rp2040-zero/firmware/CMakeLists.txt`
- Modify: `ports/rp2040-zero/tests/CMakeLists.txt`
- Modify: `ports/rp2040-zero/tests/test_pager_core.c`
- Test: `tools/test_rp2040_display_ui.py`

**Interfaces:**
- Consumes: `pager_event_t` from `pager_core.h` and `PAGER_BUZZER_PIN` from `board_config.h`.
- Produces: `pager_buzzer_event_pulses(pager_event_t event) -> uint8_t`.
- Produces: `pager_buzzer_start(pager_buzzer_t *buzzer, uint8_t pulses, uint32_t now_ms)` and `pager_buzzer_update(pager_buzzer_t *buzzer, uint32_t now_ms) -> bool`.

- [ ] **Step 1: Write failing scheduler and source-contract tests**

Add to `ports/rp2040-zero/tests/test_pager_core.c`:

```c
static void test_buzzer_event_pulse_counts_and_nonblocking_timing(void) {
    pager_buzzer_t buzzer;

    assert(pager_buzzer_event_pulses(PAGER_EVENT_NONE) == 0U);
    assert(pager_buzzer_event_pulses(PAGER_EVENT_WAIT) == 3U);
    assert(pager_buzzer_event_pulses(PAGER_EVENT_DONE) == 1U);
    assert(pager_buzzer_event_pulses(PAGER_EVENT_ERROR) == 5U);

    pager_buzzer_init(&buzzer, 0U);
    pager_buzzer_start(&buzzer, 3U, 0U);
    assert(pager_buzzer_is_active(&buzzer));
    assert(!pager_buzzer_update(&buzzer, 24U));
    assert(pager_buzzer_update(&buzzer, 25U));
    assert(!pager_buzzer_is_active(&buzzer));
    assert(!pager_buzzer_update(&buzzer, 204U));
    assert(pager_buzzer_update(&buzzer, 205U));
    assert(pager_buzzer_is_active(&buzzer));
}
```

Add to `tools/test_rp2040_display_ui.py`:

```python
def test_main_configures_active_low_buzzer_on_gp14():
    assert "gpio_init(PAGER_BUZZER_PIN)" in MAIN_SOURCE
    assert "gpio_put(PAGER_BUZZER_PIN, true)" in MAIN_SOURCE
    assert "gpio_put(PAGER_BUZZER_PIN, !pager_buzzer_is_active" in MAIN_SOURCE

def test_multi_task_state_does_not_trigger_buzzer():
    assert "pager_buzzer_event_pulses(snapshot.event)" in MAIN_SOURCE
    assert "PAGER_MULTI" not in MAIN_SOURCE.split(
        "pager_buzzer_event_pulses", 1
    )[1].split("pager_display_ui_update", 1)[0]
```

- [ ] **Step 2: Run focused tests and verify failure**

Run:

```powershell
python -m pytest tools/test_rp2040_display_ui.py -q
cmake --build build-rp2040-host
ctest --test-dir build-rp2040-host --output-on-failure
```

Expected: the buzzer scheduler types and source hooks are missing.

- [ ] **Step 3: Implement the pure buzzer scheduler**

Create `buzzer.h`:

```c
#ifndef CODEX_BUZZER_H
#define CODEX_BUZZER_H

#include "pager_core.h"

#include <stdbool.h>
#include <stdint.h>

#define PAGER_BUZZER_ON_MS 25U
#define PAGER_BUZZER_GAP_MS 180U

typedef struct {
    uint8_t remaining;
    bool active;
    uint32_t changed_ms;
} pager_buzzer_t;

uint8_t pager_buzzer_event_pulses(pager_event_t event);
void pager_buzzer_init(pager_buzzer_t *buzzer, uint32_t now_ms);
void pager_buzzer_start(
    pager_buzzer_t *buzzer, uint8_t pulses, uint32_t now_ms);
bool pager_buzzer_update(pager_buzzer_t *buzzer, uint32_t now_ms);
bool pager_buzzer_is_active(const pager_buzzer_t *buzzer);

#endif
```

Implement `buzzer.c` so `pager_buzzer_start` begins the first active pulse
immediately, `pager_buzzer_update` changes state only after the configured
duration, and returns true only on an output change. Map WAIT/DONE/ERROR to
3/1/5 and all other events to zero.

- [ ] **Step 4: Connect GP14 in the RP2040 entry point**

In `main.c`, include `buzzer.h`, configure GP14 as a GPIO output before the
main loop, and set it HIGH before starting USB:

```c
gpio_init(PAGER_BUZZER_PIN);
gpio_set_dir(PAGER_BUZZER_PIN, GPIO_OUT);
gpio_put(PAGER_BUZZER_PIN, true);
```

Start the boot pulse once after initialization:

```c
pager_buzzer_init(&buzzer, last_valid_snapshot_ms);
pager_buzzer_start(&buzzer, 1U, last_valid_snapshot_ms);
```

For every parsed snapshot, trigger only a newly observed non-NONE event. Keep
`last_buzzer_event`; clear it when `snapshot.event` returns to NONE. In the
main loop write the active-low pin only when the scheduler changes:

```c
if (pager_buzzer_update(&buzzer, current_ms)) {
    gpio_put(PAGER_BUZZER_PIN, !pager_buzzer_is_active(&buzzer));
}
```

Add `src/buzzer.c` to both RP2040 firmware and host-test CMake source lists.

- [ ] **Step 5: Run focused and full host tests**

Run:

```powershell
python -m pytest tools/test_rp2040_display_ui.py -q
cmake --build build-rp2040-host
ctest --test-dir build-rp2040-host --output-on-failure
python -m pytest tools -q
```

Expected: all existing tests pass and the host buzzer timing test proves that
the 25 ms/180 ms sequence advances without sleeps or blocking calls.

- [ ] **Step 6: Commit buzzer support**

```powershell
git add ports/rp2040-zero/firmware/include/buzzer.h ports/rp2040-zero/firmware/src/buzzer.c ports/rp2040-zero/firmware/src/main.c ports/rp2040-zero/firmware/CMakeLists.txt ports/rp2040-zero/tests/CMakeLists.txt ports/rp2040-zero/tests/test_pager_core.c tools/test_rp2040_display_ui.py
git commit -m "feat: add nonblocking active-low buzzer"
```

---

### Task 5: Build, Flash, and Verify Two-Conversation Behavior

**Files:**
- Inspect after measured evidence: `ports/rp2040-zero/firmware/src/display_scene.c`
- Build output: `build-rp2040/codex_pager_rp2040.uf2`
- Update: `ports/rp2040-zero/README.md`

**Interfaces:**
- Consumes: completed host-tested firmware.
- Produces: flashed RP2040-Zero and physical acceptance results.

- [ ] **Step 1: Run the complete verification suite**

Run:

```powershell
powershell -ExecutionPolicy Bypass -File tools/run_host_tests.ps1
```

Expected: Python tests and RP2040 host C tests all pass.

- [ ] **Step 2: Build a release UF2**

Run:

```powershell
powershell -ExecutionPolicy Bypass -File tools/build_rp2040.ps1
```

Expected: `build-rp2040/codex_pager_rp2040.uf2` exists, has a non-zero size,
and the build completes without PDB-server hangs.

- [ ] **Step 3: Flash when RPI-RP2 is present**

Verify the boot drive:

```powershell
Get-Volume | Where-Object FileSystemLabel -eq 'RPI-RP2'
```

Copy the UF2 to the returned drive:

```powershell
Copy-Item -LiteralPath build-rp2040/codex_pager_rp2040.uf2 -Destination 'D:\codex_pager_rp2040.uf2'
```

Use the actual detected drive letter rather than assuming `D:`.

Expected: the RPI-RP2 drive disconnects after copying and the firmware starts.

- [ ] **Step 4: Run state-level smoke tests**

Send:

```powershell
python tools/send_pager.py RUNNING --run 1
python tools/send_pager.py RUNNING --run 2
python tools/send_pager.py RUNNING --run 3
python tools/send_pager.py RUNNING --run 4
python tools/send_pager.py WAIT --wait 1 --event WAIT
python tools/send_pager.py DONE --done 1 --event DONE
python tools/send_pager.py ERROR --event ERROR
python tools/send_pager.py READY --run 0
```

Expected:

- RUN=1: sharp purple foreground only.
- RUN=2: one deep-blue softened ghost.
- RUN=3: two softened ghosts.
- RUN=4: three softened ghosts.
- WAIT: three quiet, short active-low buzzer pulses.
- DONE: one quiet, short active-low buzzer pulse.
- ERROR: five quiet, short active-low buzzer pulses.
- READY: all ghosts fade out and the existing READY design returns.

- [ ] **Step 5: Verify real concurrent Codex tasks**

Start two Codex conversations simultaneously.

Expected:

- the second task produces one ghost on the first display frame after the
  snapshot reaches the board;
- the foreground does not jump, restart, turn yellow, or split into petals;
- completing either task fades the surplus ghost out over 320 ms;
- completing all tasks returns through the existing RUNNING-to-READY path.
- entering or leaving MULTI does not produce a buzzer pulse.

- [ ] **Step 6: Record physical tuning and update documentation**

Document observed frame rate, visibility, and any color adjustment in
`ports/rp2040-zero/README.md`. Only tune ghost RGB565 constants or opacity after
physical evidence; do not alter the foreground Blossom or hex geometry.

- [ ] **Step 7: Commit verified firmware documentation**

```powershell
git add ports/rp2040-zero/README.md
git commit -m "docs: record multi-task display verification"
```

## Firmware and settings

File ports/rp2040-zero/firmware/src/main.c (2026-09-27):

#include "board_config.h"
#include "buzzer.h"
#include "display_ui.h"
#include "led_effects.h"
#include "pager_core.h"
#include "pager_stream.h"
#include "st7789.h"

#include "hardware/clocks.h"
#include "hardware/gpio.h"
#include "hardware/pio.h"
#include "pico/stdlib.h"
#include "ws2812.pio.h"

#include <stdbool.h>
#include <stdint.h>

_Static_assert(PAGER_WS2812_PIN == 16U, "RP2040-Zero WS2812 pin mismatch");

typedef struct {
    PIO pio;
    uint sm;
} ws2812_output_t;

static uint32_t now_ms(void) {
    return to_ms_since_boot(get_absolute_time());
}

static ws2812_output_t ws2812_init(void) {
    ws2812_output_t output;
    const uint offset = pio_add_program(pio0, &ws2812_program);

    output.pio = pio0;
    output.sm = pio_claim_unused_sm(output.pio, true);
    ws2812_program_init(
        output.pio, output.sm, offset, PAGER_WS2812_PIN, 800000.0f, false);
    return output;
}

static void ws2812_try_write(ws2812_output_t output, pager_rgb_t color) {
    if (!pio_sm_is_tx_fifo_full(output.pio, output.sm)) {
        pio_sm_put(output.pio, output.sm, pager_led_pack_rgb(color));
    }
}

static int read_usb_byte(void *context) {
    const int byte = getchar_timeout_us(0U);
    (void)context;
    return byte == PICO_ERROR_TIMEOUT ? PAGER_STREAM_NO_BYTE : byte;
}

int main(void) {
    pager_stream_t stream = {{0}, 0U};
    pager_snapshot_t snapshot = {0};
    pager_state_t state = PAGER_OFFLINE;
    uint32_t last_valid_snapshot_ms = now_ms();
    uint32_t state_started_ms = last_valid_snapshot_ms;
    uint32_t last_led_update_ms = last_valid_snapshot_ms;
    pager_buzzer_t buzzer;
    pager_event_t last_buzzer_event = PAGER_EVENT_NONE;
    ws2812_output_t ws2812;

    stdio_init_all();
    gpio_init(PAGER_BUZZER_PIN);
    gpio_set_dir(PAGER_BUZZER_PIN, GPIO_OUT);
    gpio_put(PAGER_BUZZER_PIN, true);
    pager_buzzer_init(&buzzer, last_valid_snapshot_ms);
    pager_buzzer_start(&buzzer, 1U, last_valid_snapshot_ms);
    gpio_put(PAGER_BUZZER_PIN, !pager_buzzer_is_active(&buzzer));
    ws2812 = ws2812_init();
    st7789_init();
    st7789_set_backlight(true);
    pager_display_ui_init(state, now_ms());

    while (true) {
        const uint32_t current_ms = now_ms();
        if (pager_stream_drain(
                &stream, read_usb_byte, NULL, &snapshot) > 0U) {
            const pager_state_t selected = pager_select_state(&snapshot);
            last_valid_snapshot_ms = current_ms;
            if (selected != state) {
                state = selected;
                state_started_ms = current_ms;
            }
            pager_display_ui_set_snapshot(
                state, snapshot.running, snapshot.balance, current_ms);
            if (snapshot.event == PAGER_EVENT_NONE) {
                last_buzzer_event = PAGER_EVENT_NONE;
            } else if (snapshot.event != last_buzzer_event) {
                pager_buzzer_start(
                    &buzzer,
                    pager_buzzer_event_pulses(snapshot.event),
                    current_ms);
                gpio_put(PAGER_BUZZER_PIN, !pager_buzzer_is_active(&buzzer));
                last_buzzer_event = snapshot.event;
            }
        }
        if (pager_buzzer_update(&buzzer, current_ms)) {
            gpio_put(PAGER_BUZZER_PIN, !pager_buzzer_is_active(&buzzer));
        }

        {
            const pager_state_t timed_state = pager_apply_timeout(
                state, last_valid_snapshot_ms, current_ms);
            if (timed_state != state) {
                state = timed_state;
                state_started_ms = current_ms;
                pager_display_ui_set_state(state, current_ms);
            }
        }

        if ((uint32_t)(current_ms - last_led_update_ms) >= PAGER_LED_UPDATE_MS) {
            const pager_rgb_t color = pager_led_sample(
                state, (uint32_t)(current_ms - state_started_ms));
            ws2812_try_write(ws2812, color);
            last_led_update_ms = current_ms;
        }
        pager_display_ui_update(current_ms);
        sleep_ms(1U);
    }
}

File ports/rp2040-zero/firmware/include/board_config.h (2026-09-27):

#ifndef CODEX_BOARD_CONFIG_H
#define CODEX_BOARD_CONFIG_H

#define PAGER_WS2812_PIN 16U
#define PAGER_BUZZER_PIN 14U
#define PAGER_DISPLAY_BLK_PIN 8U
#define PAGER_DISPLAY_DC_PIN 9U
#define PAGER_DISPLAY_RES_PIN 10U
#define PAGER_DISPLAY_SDA_PIN 11U
#define PAGER_DISPLAY_SCL_PIN 12U

#define PAGER_DISPLAY_WIDTH 240U
#define PAGER_DISPLAY_HEIGHT 240U
#define PAGER_DISPLAY_SPI_HZ 48000000U

#define PAGER_LINE_CAPACITY 96U
#define PAGER_LED_UPDATE_MS 10U

#endif
